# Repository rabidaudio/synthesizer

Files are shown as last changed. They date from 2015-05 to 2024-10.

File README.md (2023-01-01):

# Synth

> These are my custom modules for a from-scratch [Eurorack](https://en.wikipedia.org/wiki/Eurorack) analog synthesizer.

https://rabid.audio/projects/synth

## Modules

1. [Amplifier](amp)
  - LM13700
  - matched-pair PNP exponential converter
  - CV of 10V -> Gain=1
  - CV of <=0V -> Gain=\~0, 6 decades below Gain=1
  - allow overdrive to Gain=2
    - ideally this would begin to clip
  - mixdown
    - mono - full mix -> left and right
    - stereo split - A+C->left B+D->right
  - Direct stereo input jack
    - mix arbitrary signal with mixdown
    - e.g. for accepting signals from other synths
2. [Oscillator](vco)
  - 0-10V, 1V/octave, A0 to A10
  - Square/Triangle core via LM13700
  - Waveshapper for triangle -> sine
  - PWM control
    - triangle wave applied to comparator with CV controlling reference. Triangle wave means CV is linear
  - abs(triangle) can be used for 2x square
    - adds a lot of parts for little benefit
  - blending shapes isn't useful here, since we could use other oscillators for that
  - Option to sync with another osc?
    - in theory, grounding osc at a regular interval would reset the osc over and over, effectively changing it's frequency
  - CV control for shape?
  - Room for more shapes
    - white noise?
    - PDS
      - https://en.wikipedia.org/wiki/Phase_distortion_synthesis
      - a bit of wild harmonics
      - multiplication techniques
        - log/antilog
        - https://en.wikipedia.org/wiki/Gilbert_cell
        - AD633 ($11-$13 /unit on DigiKey!?)
        - EL4450C ($4/unit on Digikey but out of stock). It's a little more awkward to use since it's max differerential input voltage for linearity is 2V
      - the hard part will be the "slightly higher frequency" bit
        - perhaps instead you have another osc (555?) running at a fixed frequency and clipping the sine
        - square PWM control could also adjust this clip frequency
      - In Max you do PDS by `kink~`-ing a `phasor~` and using that to drive the phase of `cycle~`. Kink is somewhat straightforward to do - use a comparator to adjust the charge current after a threshold. But how you drive a sine wave phase with that I'm not sure
    - down ramp wave with just a JFET
      - up ramp wave probably needs another JFET and an inverter
    - sub octave
      - theory and example circuit: http://www.valvewizard.co.uk/uboat.html
    - octave
      - full wave rectifier
    - multiplying the triangle with a square wave with different phases and pulse-widths gives some neat sounds
    - polynomial
      - The EL4450C datasheet describes using a multiplier ic to create a polynomial of the form (k1 v^2 + v) / k2
      - it sounds like crap on a triangle wave and does nothing for a square wave, but it adds a nice second harmonic to a sine wave
      - from experiments in Max, good values are k1=1.5-2.5, k2=2
      - but at that point, should you just use 2 oscillators?
3. [A/D/S/R envelope](adsr)
  - 4 envelopes required for 4-voice polyphony
  - wired to VCA by default
  - save surface area with 1 set of ADSR controls for a pair of envelopes
  - fully modular means you could borrow one for VCF instead, or send to both VCA and VCF
4. Filter
  -  4P LP(/HP?)
  - Cutoff frequency control has same range as oscillator
    - 0-10V, 1V/octave, A0 to A10
  - filter we designed for class
    - standard vactrols are available on Thonk
  - CV control of cutoff + resonance
  - Default to track cutoff with VCO-CV
  - individual filter knobs, plus a global knob for filter sweeps
5. [Utilities](utils)
  - Buffer, Sum, Attenuate, Invert, Gate
  - Could be all-in one
    - A input (default ground)
    - B input (default ground)
    - level knob attenuator
    - gate digital CV in, default on
    - `(A+B)*level*gate` output
    - `-(A+B)*level*gate` output
    - Constant CV out if A and B disconnected

Bitcrusher?
4 filters or one?
Noise?
Clock?
Headphone output no longer required
2D mixer?

## TODO

- utility module
  - [x] Verify on breadboard
  - [x] design PCB
  - [x] order parts
  - [x] come up with a cute name
  - [x] design front panel
  - [x] assemble Rev. A PCB
    - bend the regulators first
    - plenty of 4066s
    - flip orientation of power connector
    - pot orientation - both channels:
      - right side (facing) to inside of board (from top)
      - left side (facing) to outside of board (from top)
  - [x] test with Neutron
    - constant output is only 9 to -7.8
    - high noise when used as a buffer
      - perhaps input signal is clipping?
      - white noise when the gain is turned down
  - [x] adjust design for Rev. B
  - [x] assemble Rev. B proto board
  - fix prototype issues
    - [ ] sum pot is backwards
    - [ ] a bit of noise on the constant output near the center
    - [ ] verify output levels
    - [ ] hard click on gate
      - needs a LPF?
  - [ ] assemble Rev. B PCB
  - [ ] manufacture front panel
  - [ ] assemble module
- VCA
  - [x] Confirm amp on breadboard, finalize CV levels
  - [x] figure out where tuning trimmers are needed
  - [x] build prototype
  - fix prototype issues
    - [ ] output is too quiet for headphones, need about 2x gain
    - [ ] CV range is too wide, adjust scaling for faster change in db/V
  - [ ] finish PCB schematic for complete amplifier
  - [ ] Create PCB
  - [ ] design front panel
  - [ ] manufacture front panel
  - [ ] assemble module
- VCO
  - [ ] design core
    - [x] core osc - square/triangle
    - [x] wave shaper (sine)
    - [x] pwm control
    - [ ] additional shape
    - [x] shape selection
  - [x] Confirm amp on breadboard, finalize CV levels
  - fix breadboard test issues
    - [ ] pitch is very sensitive to power supply noise
    - [ ] tuning is rather difficult
  - [ ] Build prototype
  - fix prototype issues
    - TBD
  - [ ] design PCB
  - [ ] Create PCB
  - [ ] design front panel
  - [ ] manufacture front panel
  - [ ] assemble module
- Envelope
  - [x] design in SPICE
  - [ ] verify on breadboard
  - [ ] build prototype
  - fix prototype issues
    - TBD
  - [ ] design PCB
  - [ ] Create PCB
  - [ ] design front panel
  - [ ] manufacture front panel
  - [ ] assemble module
- VCF
  - TBD
- build tools
  - [x] tiny Breakout pcbs for headphone jacks
  - ~~transistor matcher circuit~~
    - bought matched pair BJTs instead
  - [x] quantized selector with hysteresis

## License

Schematics, board layouts, documentation, etc. is licensed under [Creative Commons Attribution-NonCommercial-ShareAlike 4.0 International License](http://creativecommons.org/licenses/by-nc-sa/4.0/).



If you're interested in commercial use, please ask first.

Any source code is licensed under [MIT](SOFTWARE_LICENSE).

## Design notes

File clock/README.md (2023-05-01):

# The Count

## [Writeup and documentation](https://rabid.audio/projects/synth/clk/)

## Features

- BPM from 15 to 400
- two outputs with relative rates
- 3-digit LED 7-segment display
- swing control
- tap tempo
- CV in
- pause
- save/load/reset settings

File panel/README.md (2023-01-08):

# Layout

- Jacks at the top, controls at the bottom
- 14mm spacing between jacks (center to center) in both directions
- Knob/switch spacing?

- 1HP=1/5"=5.08mm
  - standard graph paper is 5 squares per inch, meaning exactly 1 real world HP per square
- 84 HPs (426mm) of usable horizontal space in a 19" rack
- 3U=128.5mm
  - 112.5mm of useable vertical space after leaving room for mounting screws
- Maximum control density:
  - jacks = 14mm wide, 9mm high (12+ recommended)
  - knobs = 22mm square (30mm recommended)
    - note: some knobs have 21mm base and need to be bigger
- each jack is 3HP wide, each knob is 5 or 6HP wide

Reference for dimensions: http://www.doepfer.de/a100_man/a100m_e.htm

# Panels

Material: 0.08" thick 6061 Aluminum

This series of posts is super helpful for aluminum panel cutting and applying graphics with transfer paper:

- https://syntherjack.net/eurorack-module-diy-tutorial-1-drilling/
- https://syntherjack.net/eurorack-module-diy-tutorial-2-graphics/

# Case

TipTop is good starter product, has it has adapter for mounting modules in 19" rack, and included power supply

Power supply:

- 2000mA at +12V
- 500mA at -12V
- 170mA at +5V

- https://www.amazon.com/Tiptop-Audio-Happy-Ending-Kit/dp/B074B29GPR

NiftyKeyz - 112 HP

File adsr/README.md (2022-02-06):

# ADSR Envelope

This circuit operates by using the LM13700 as a variable current source charging
a capacitor. It is configured as a non-inverting op-amp charging the capacitor
to a reference voltage `V_ref` at the `+` pin with a slew rate limited by the current
control. The capacitor's voltage will change linearly based on `I_abc` until it settles
at `V_ref`. Then a bit of digital logic to create a 3-state state machine to select the
correct  `V_ref` and `I_abc`.

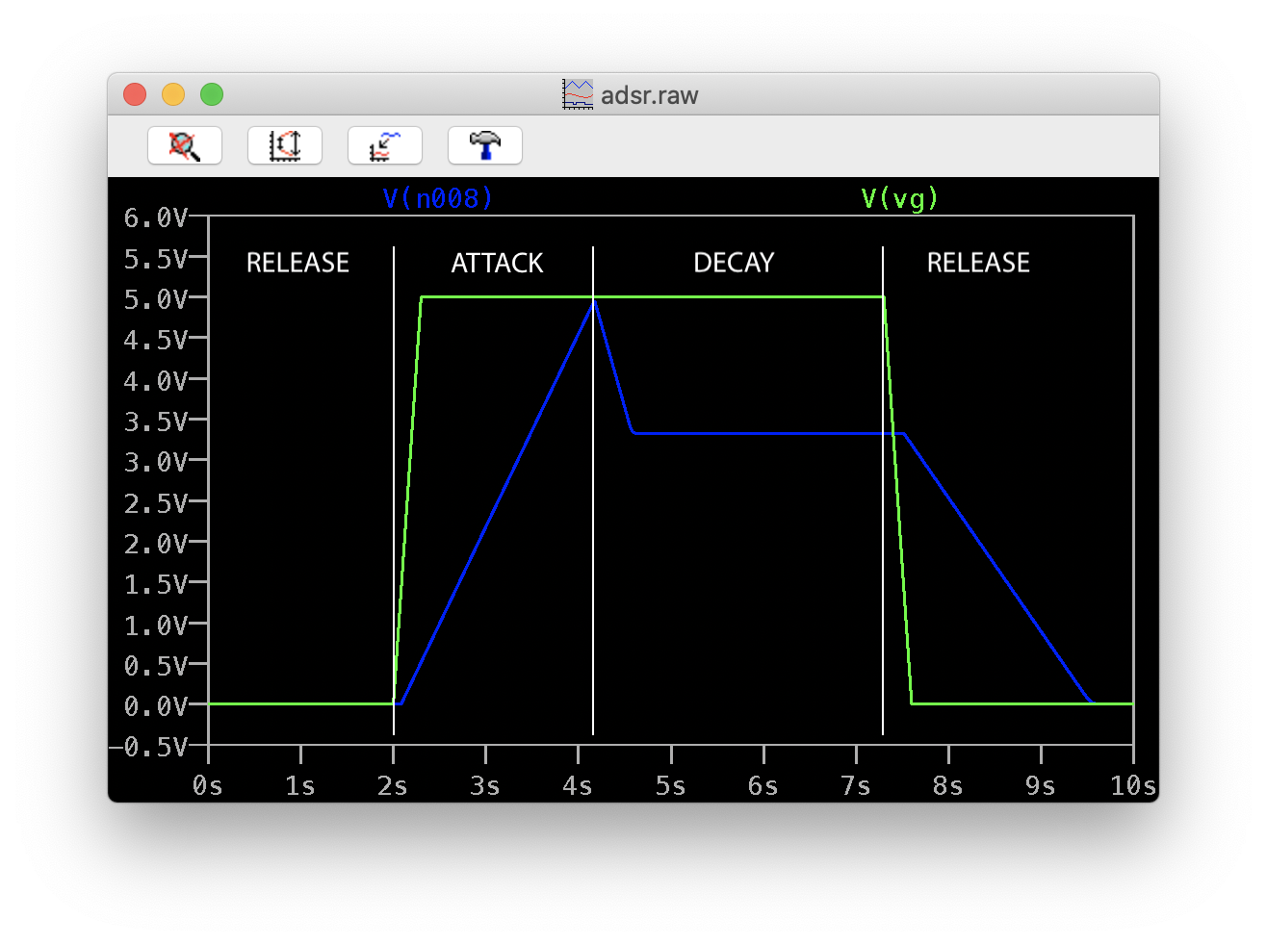
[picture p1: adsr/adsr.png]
shape


States:

- Attack: `V_gate=5V`, `V_ref=V_in`, `I_abc` controlled by `R_attack`
- Decay: `V_gate=5V`, `V_ref=V_sustain`, `I_abc` controlled by `R_decay`
- Release: `V_gate=0`, `V_ref=0`, `I_abc` controlled by `R_release`

The Attack, Decay, and Release knobs control `I_abc` in each state,
while the Sustain knob divides down `V_in` to set `V_ref` in the
Decay state.

A comparator, capacitor, and a few transistors create cheap analog
a flip-flop that turns on when the output hits `V_in` (flipping from
the Attack state to the Decay state), and turns off when `V_gate`
turns off.

Voltage control of the parameters could be possible by exposing
access to `I_abc`, but it doesn't make much sense to me to expose
those parameters with any control other than a knob - it's not the
kind of thing you need to modulate automatically.

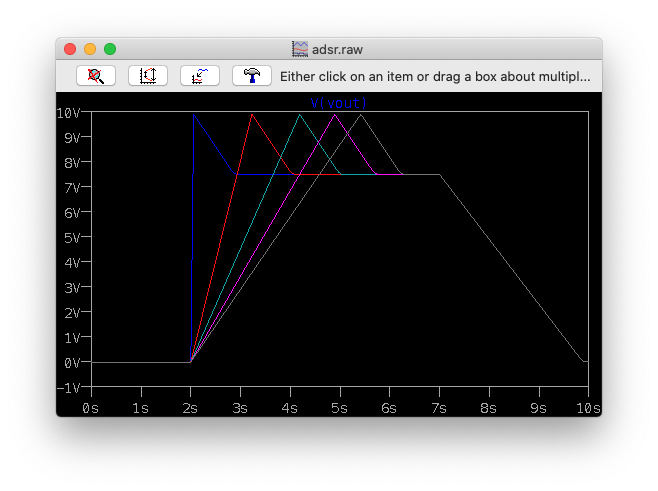
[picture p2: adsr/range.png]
range


Choice of the capacitor and the knob resistance control the time
range. Large values for both mean a longer charge time, but a large
capacitance effects the fastest charge time too, since `I_abc` is
capped at 2mA. Pot size effects dynamic range.

In practice, charge times less than 15ms are undetectable, and charge times above 2s are largely unnecessary.

A non-linear resistance would allow finer control at larger charge times. However linear seems to have plenty of expressiveness.

C=4.7u and a knob range of 1M gives a control range of 12ms to \~1.8s for a
0-5V change, i.e. a slew rate between 356 V/s and 2.4 V/s.

Could offer two caps, fast and slow, with a toggle switch. A 22u capacitor gives 58ms to 8.6s. A 1u capacitor gives \~5ms to \~55ms.

A current mirror isolates the 3 different reference voltages, without it they
interfere with each other.

Rates are dependant on the input level. This means if the input gate level is variable (for example it depends on MIDI note velocity), then the times will be slower for harder hits. We'd probably want constant rates regardless of velocity for example. However this seems difficult to achieve with the current design, as during release the input voltage is off, so without memory you don't have a reference to scale the output by.

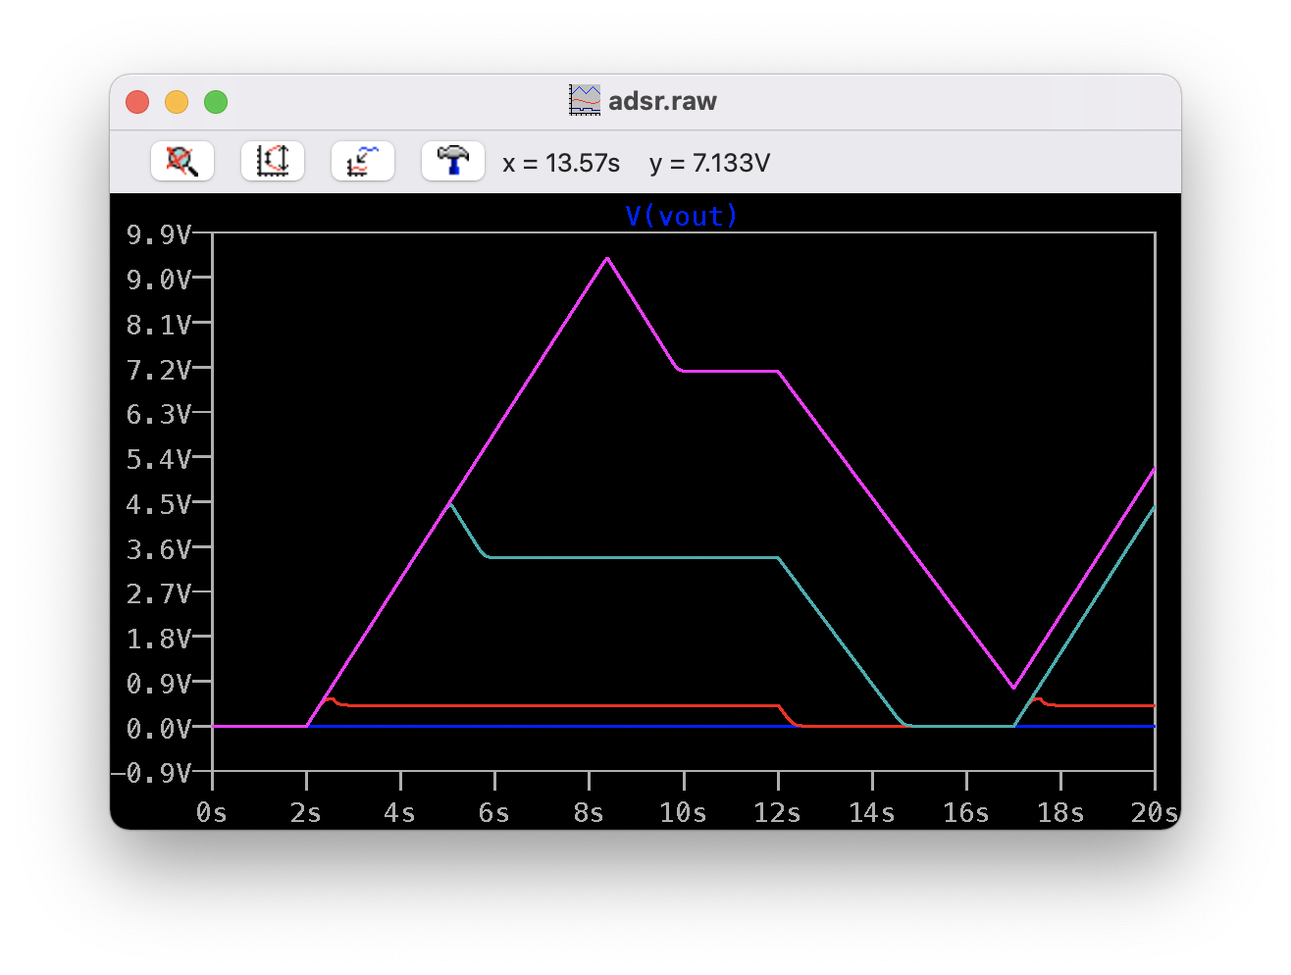
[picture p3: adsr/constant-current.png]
constant current means time depends on level


**TODO: power usage**

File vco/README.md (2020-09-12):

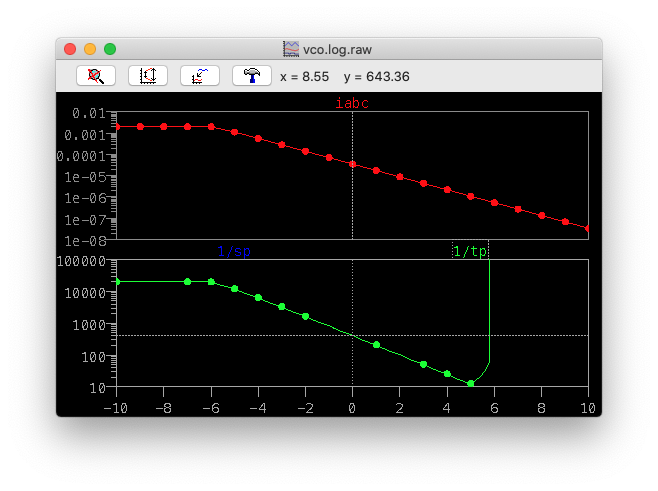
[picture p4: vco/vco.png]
vco response


Here, the frequency measurement flies off to infinity after 5V that's because the frequency has gotten too low to fit in the `.tran` time window. Increasing the time window wide enough to measure the frequency up to CV=10V causes the simulation to timeout. However, the exp. converter remains accurate to 3 decades below 0V, which is hypothetically CV=20V -> A-16 (f=419mHz or a period of \~40 seconds). The power supply max at CV=12 would be A-8 for a period of 9.8s.

`R_ref` was calculated to be 341K but empirically determined from LTSpice model to be 326K. A trim pot should allow precision tuning.

Accuracy seems to be dependant on min/max opamp output voltages. Might be good to invest in a real rail-to-rail comparator or use offset-null of TL071.

High-freq error seems to be from comparator slew rate. TL07X slew rate is roughly 13V/us (under best circumstances). At 14.08KHz, the period is \~71us, and it's got to travel 8.2V in two directions. That means 1.8% error right there.

From the simulation, the slew rate at 14.08KHz seems to be 3.8V/us, for an error of 6.2%, which is a bit closer to the measured 14%.

The LM311 datasheet claims a slew rate of up to 50V/us, equating to a \~0.5% error.

## Shapes

### Triangle

Triangle wave comes from the square/triangle core.

### Square

A base square wave comes from the square/triangle core. We feed that into a comparator which gives control over PWM.

### Sine

Triangle wave is converted to a sine wave using a textbook transistor waveshaper. The THD is on the order of 1-2%.

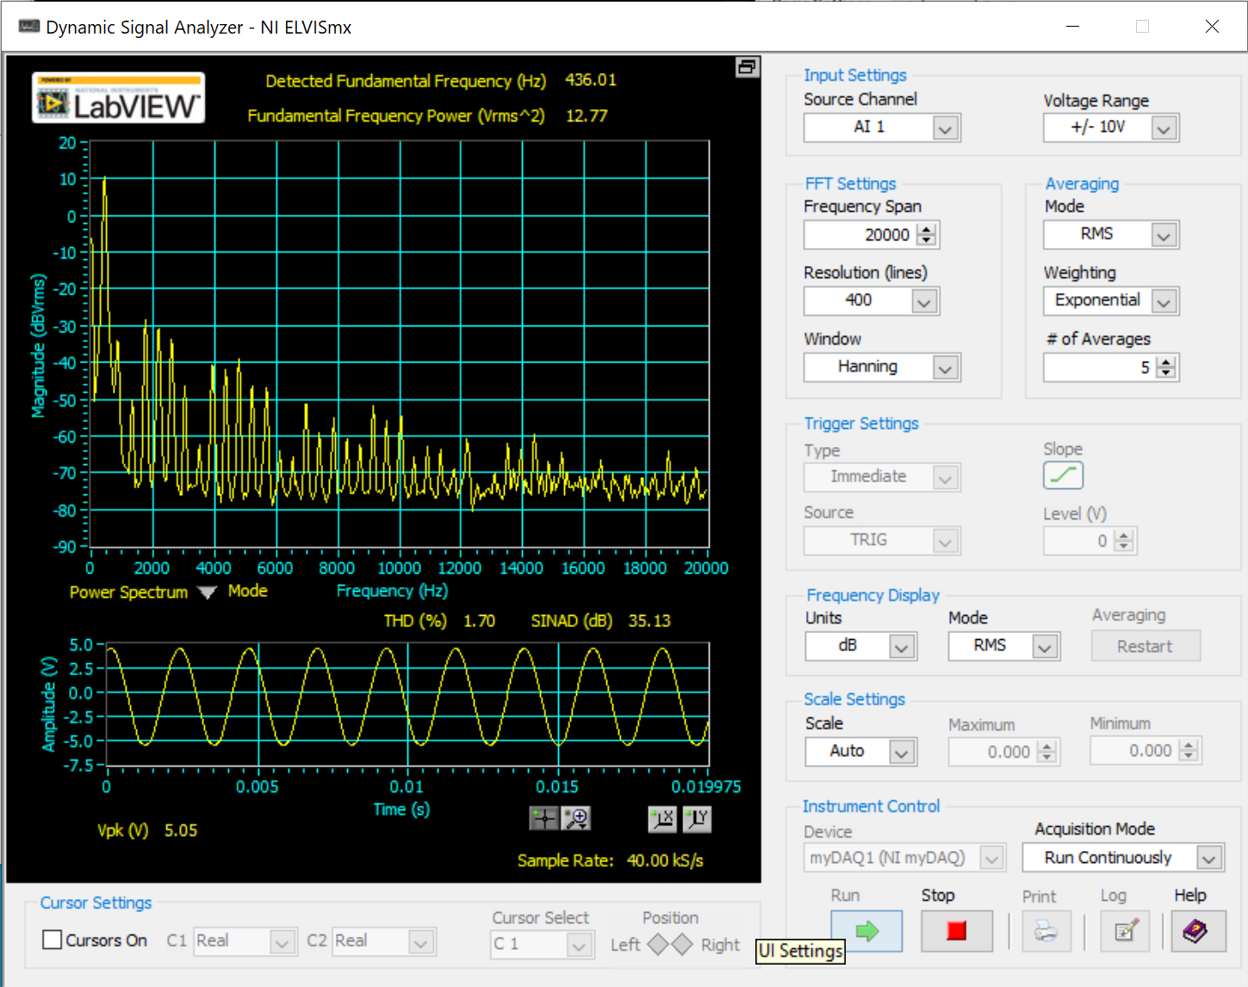
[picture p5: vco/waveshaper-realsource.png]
waveshaper-performance


### TODO: shape #4

Sub/super octave???

## Tuning

1. Set CV to 5V and adjust input network so VB=0V
2. Adjust square voltage divider network to 5V output and 0 offset
3. Adjust IREF to get 440Hz frequency
4. Set CV to 6V and adjust CV scale ratio to get 880Hz frequency
5. Adjust waveshaper current source pot until symmetric
6. Adjust waveshaper input voltage divider to minimize THD
7. Adjust waveshaper output stage to set level

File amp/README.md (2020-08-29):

# VCA

> 4-channel amplifier

## Description

Control Voltage 0-10V with `10V -> Gain=1`, `0V -> Gain~=0`. Can be overdriven up to `11V -> Gain=2` (actually slightly less because it will clip). Output is about 9.2 dB/V, with 0V around -98 dB.

Control voltage inputs are summed with a control knob, which adjusts CV between 0V and 10V.

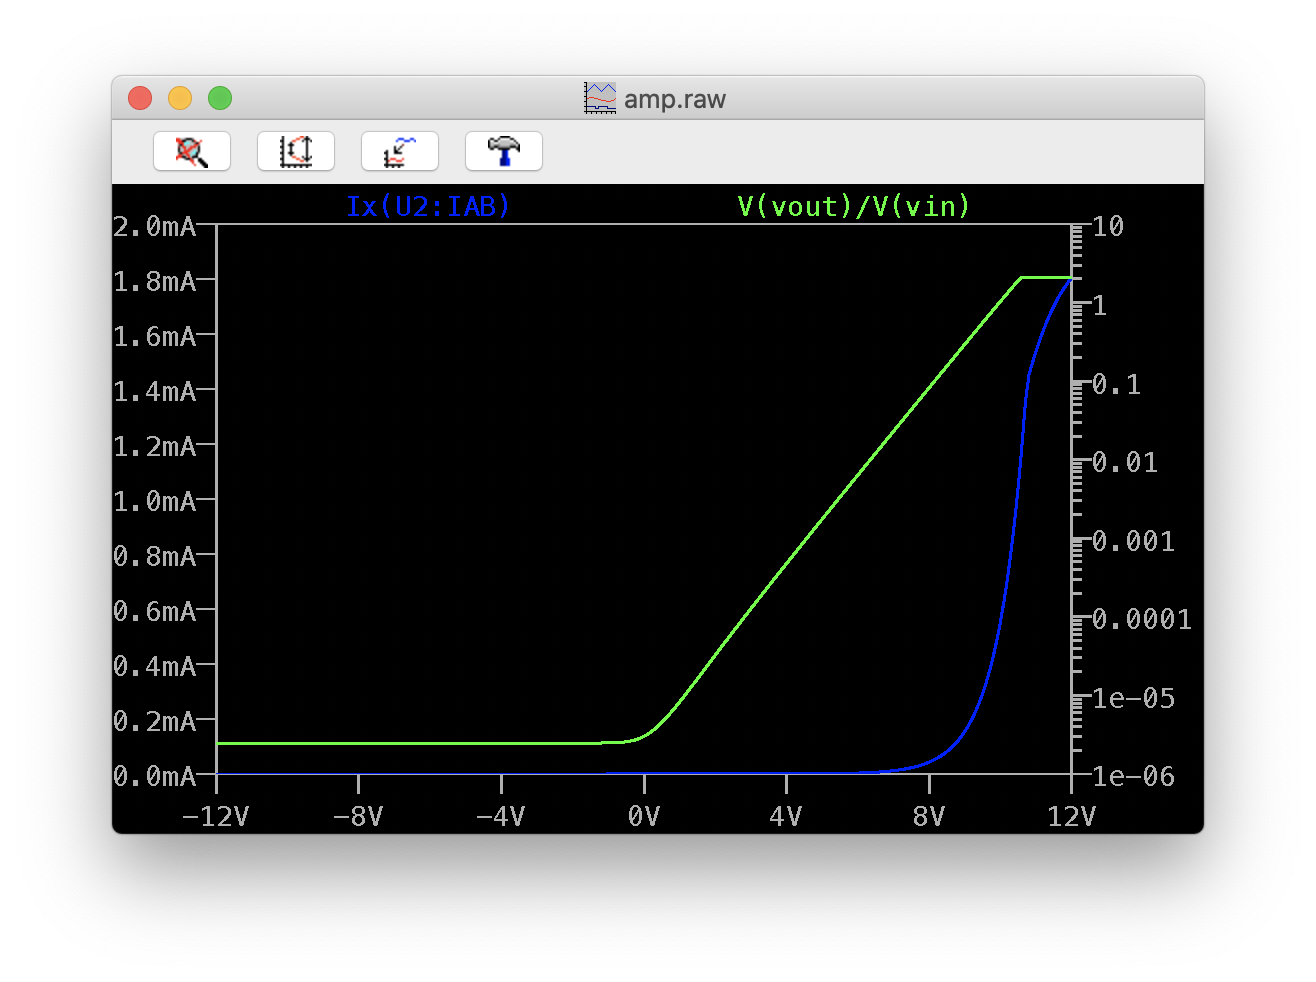
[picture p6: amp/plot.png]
cv-vs-gain


The 4 channels are connected to the 4 channels from the filter, unless an input is supplied.

The 4 channels are mixed down along with EXT-IN, an input for arbitrary external signals, such as those from another synth. In MIX mode, the result of the mix is sent to both left and right stereo outputs. in SPLIT mode, channels A and C go to the left channel output only, while B and D go to the right channel output only.

Both 1/4" TLS main and 3.2mm headphone outputs are available. **TODO: power calculation**

**TODO: power usage** 

## Design

The amplifier is designed around the [LM13700](../reference/datasheets/lm13700.pdf), with an [antilog converter](../reference/exponential.pdf) providing current control. Calculations of component values are [here](amp.xlsx).

The LM13700 acts as a linear amplifier when `Vd <= 20mV`. It's output is a current source given by the equation `Iout=0.5*Vd/Vt*Iabc` where `Vt=26mV` @ room temp. `Iabc` cannot exceed 2mA. Setting `Iabc=0.5mA` for unity gain puts `Iout=.192mA`. This can be converted back to a voltage with a resistor. `Rout=26kΩ `sets the overall voltage gain to unity.

## Tuning

1. Set CV-IN to 10V, and RV2 to completely off. Adjust RT1 until base of Q1A is 0V (or Q1 collectors are the same).
2. Adjust RT2 until the current through it is 0.5mA. One way to do this is to precicely measure the negative supply rail, and then adjust the resistance to match.
3. Set CV-IN to 0V, RV2 to completely on, and IN to 10V. Adjust RT3 until OUT is 10V (an overall gain of 1).

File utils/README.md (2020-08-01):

# Jackknife

> Buffer/Inverter/Gate/Adder/Scaler/Source

## Description

This is a collection of common tools for transforming signals, either control voltages or audio signals. While there are several distinct utilities, most are not mutually-exclusive.

### Source

When `A_IN` is disconnected, `OUT` is a constant voltage output based on the position of the knob. `OUT` is 0V when the knob is in the center position, and adjusts up to +/- 10V.

### Buffer / Scaler

When `A_IN` is supplied, it's value is buffered to `OUT`. The knob position linearly adjusts the output gain. At the center position, `OUT` is the same as `A_IN`. At the full-left position, `OUT` is off. At the full-right position, the value of `A_IN` is doubled. 

### Adder

When `B_IN` is supplied, it's value is added to `A_IN` before applying scaling.

### Inverter

`~OUT` is always the inverse of `OUT`.

### Gate

When `GATE` is supplied with a digital voltage, it allows disabling `OUT` (and `~OUT`) at logic-low (0V). An LED indicates when the gate is open. When `GATE` is not supplied, the outputs are always enabled, and the LED remains off.

### Digital logic

Digital `OR` can be implemented by summing signals on `A_IN` and `B_IN` With the knob at the 1/4 position. Digital `AND` can be implemented by applying one signal to `A_IN` and one to `GATE` with the knob at the 1/2 position.

## Design

A summing inverting amplifier with a variable feedback resistor handles the adder, inverter, and scalar. A connection on either A or B toggles an analog switch selecting between a constant voltage source and the summing output. Another
analog switch controlled by the gate allows that signal to be toggled before it is buffered in both an inverted and
re-inverted back to positive outputs.

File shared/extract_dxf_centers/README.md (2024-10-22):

# extract-dxf-centers

Parse a dxf file generated by OpenSCAD, cluster overlaping lines into layers, and print the center points of each cluster.

TODO

```bash
poetry run tox
poetry run extract_dxf_centers

poetry install
```

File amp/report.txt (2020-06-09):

Info: Backing up file “/Users/cjk/projects/synthesizer/amp/sym-lib-table” to file “/Users/cjk/projects/synthesizer/amp/rescue-backup/sym-lib-table-2020-03-15-19-12-47”.
Info: Backing up file “/Users/cjk/projects/synthesizer/amp/Amp.sch” to file “/Users/cjk/projects/synthesizer/amp/rescue-backup/Amp-2020-03-15-19-12-47.sch”.
Info: Backing up file “/Users/cjk/projects/synthesizer/amp/Amp.pro” to file “/Users/cjk/projects/synthesizer/amp/rescue-backup/Amp-2020-03-15-19-12-47.pro”.
Info: Backing up file “/Users/cjk/projects/synthesizer/amp/Amp-cache.lib” to file “/Users/cjk/projects/synthesizer/amp/rescue-backup/Amp-cache-2020-03-15-19-12-47.lib”.
Info: Backing up file “/Users/cjk/projects/synthesizer/amp/Amp-rescue.lib” to file “/Users/cjk/projects/synthesizer/amp/rescue-backup/Amp-rescue-2020-03-15-19-12-47.lib”.
Info: Backing up file “/Users/cjk/projects/synthesizer/amp/Amp-rescue.dcm” to file “/Users/cjk/projects/synthesizer/amp/rescue-backup/Amp-rescue-2020-03-15-19-12-47.dcm”.
Info: Adding library “Amp-rescue”, file “${KIPRJMOD}/Amp-rescue.lib” to project symbol library table.
Symbol “R” mapped to symbol library “Device”.
Symbol “TL072” mapped to symbol library “Amp-rescue”.
Symbol “C” mapped to symbol library “Device”.
Symbol “-12VA” mapped to symbol library “power”.
Symbol “+12VA” mapped to symbol library “power”.
Symbol “GND” mapped to symbol library “power”.
Symbol “R” mapped to symbol library “Device”.
Symbol “LM13700” mapped to symbol library “Amp-rescue”.
Symbol “LM13700” mapped to symbol library “Amp-rescue”.
Symbol “+12VA” mapped to symbol library “power”.
Symbol “-12VA” mapped to symbol library “power”.
Symbol “-12VA” mapped to symbol library “power”.
Symbol “+12VA” mapped to symbol library “power”.
Symbol “R” mapped to symbol library “Device”.
Symbol “R” mapped to symbol library “Device”.
Symbol “R” mapped to symbol library “Device”.
Symbol “R” mapped to symbol library “Device”.
Symbol “GND” mapped to symbol library “power”.
Symbol “GND” mapped to symbol library “power”.
Symbol “GND” mapped to symbol library “power”.
Symbol “-12VA” mapped to symbol library “power”.
Symbol “2N3906” mapped to symbol library “Amp-rescue”.
Symbol “2N3906” mapped to symbol library “Amp-rescue”.
Symbol “-12VA” mapped to symbol library “power”.
Symbol “R” mapped to symbol library “Device”.
Symbol “R” mapped to symbol library “Device”.
Symbol “GND” mapped to symbol library “power”.
Symbol “POT” mapped to symbol library “Amp-rescue”.
Symbol “GND” mapped to symbol library “power”.
Symbol “R” mapped to symbol library “Device”.
Symbol “C” mapped to symbol library “Device”.
Symbol “TL072” mapped to symbol library “Amp-rescue”.
Symbol “-12VA” mapped to symbol library “power”.
Symbol “+12VA” mapped to symbol library “power”.
Symbol “GND” mapped to symbol library “power”.
Symbol “TL072” mapped to symbol library “Amp-rescue”.
Symbol “-12VA” mapped to symbol library “power”.
Symbol “+12VA” mapped to symbol library “power”.
Symbol “R” mapped to symbol library “Device”.
Symbol “-12VA” mapped to symbol library “power”.
Symbol “R” mapped to symbol library “Device”.
Symbol “R” mapped to symbol library “Device”.
Symbol “GND” mapped to symbol library “power”.
Symbol “-12VA” mapped to symbol library “power”.
Info: Symbol library table mapping complete!

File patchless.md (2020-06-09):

analog modules with standardized plugs, no patch cables.
all patching done in software, e.g. iPad app, MAX, vst plugins, etc.

Possible with an ASIC which is just a bunch of CD4066-style bidirectional analog switches. Multiplexing every input to every other grows exponentially. Instead, you have a limited set of "patch cables" (channels) that each io can connect to. On-board memory to store switch state, which can be programmed (e.g. SPI).

```
64 patches, 128 io pins => 8192 switches, 16K transistors, 1KB of memory

8086 had 20K nMOS transistors, this is basically the same thing

singals are single-digit voltages at 100s of uAs, so power disipation is defintely a concern

144 pin BGAs exist
128x io, V+, V-, VDD, GND, 4xSPI, 8xNC
```

Bespoke ASIC design is $$$, but perhaps you cound build a company and raise money around it.

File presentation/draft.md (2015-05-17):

I'm Julian. By day I write software for drones, and by night I make side projects.
As the week progresses my nights take over my days, so I freelance hardware and software
development so that I can just do side projects for a living.

Today I thought I'd show you one of my side projects, the synthesizer I'm putting together,
and maybe inspire you to dive into hardware.

I figure most of the people in this room are software people. And I suspect there are a few people
who've maybe played with an arduino or a raspberry pi, sensors and LEDs and the like, but the 
thought of transistors or capacitors intimidates you. 

Well, synthesizers are a great jumping off point into analog electronics. 

1. They're modular
2. You interact with them on a human level, artistic
3. $$$

The modular is a big one for you software types.

### Intro to Synths

### No calculus

Just like software developers, hardware developers are lazy

##### 4 equations

- V=I*R (Ohm's law)
- fo = 1/(2*pi*R*C) (RC filter cutoff)
- (Ideal Op amps) Vo/Vi = -Rf/Ri, Rf/Ri + 1
- ???

### Modules

    CV CV
     | |
in->[   ]->out

VCO(oneVoltPerOctaveFrequencyCV, shape){
  exponentialVoltage = LinearExponentialConvert(oneVoltPerOctaveFrequencyCV);
  resistorFrequencyCV = OTA(exponentialVoltage);
  [square, triangle] = 2OpAmpSqTriOsc(resistorFrequencyCV);
  sine = WaveShape(triangle);

  switch(shape){
    case 'square': wave = square;
    case 'triangle': wave = triangle;
    case 'sine': wave = sine;
  }

  return wave;
}

### LFO

### Sequencer

while(record){
  buffer.push(analogRead(input));
}

....

while(play){
  analogWrite(buffer.next(), output);
}

10 bit vs. 16 bit

features:

- reverse
- adjustable rate
- clear
-trigger mode

### Boards

Eagle

### Future work

- replace Werkstatt with all custom modules
- 3 filters: 4-pole LP, HP, state-variable
- buffed-up VCA:
  - individually-controllable inputs (mixer)
  - higher output
  - stereo output
  - ability to invert stereo phase
- 2 to 4  4decade LFO's with clock input, PWM control
- second oscillator with relative tune control
- MIDI keyboard+EV replacement
- patch memory

### Learn more

Ray Wilson
Aaron Lanterman

### Me

@charlesjuliank

github.com/rabidaudio/synthesizer

rabid.audio/blog

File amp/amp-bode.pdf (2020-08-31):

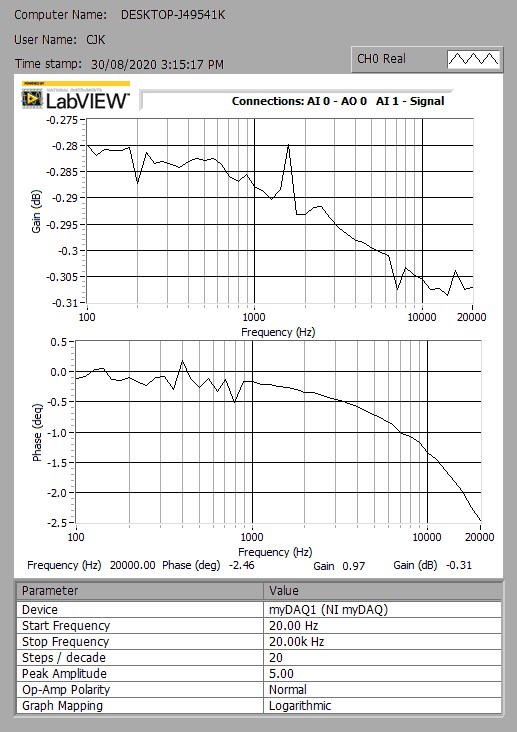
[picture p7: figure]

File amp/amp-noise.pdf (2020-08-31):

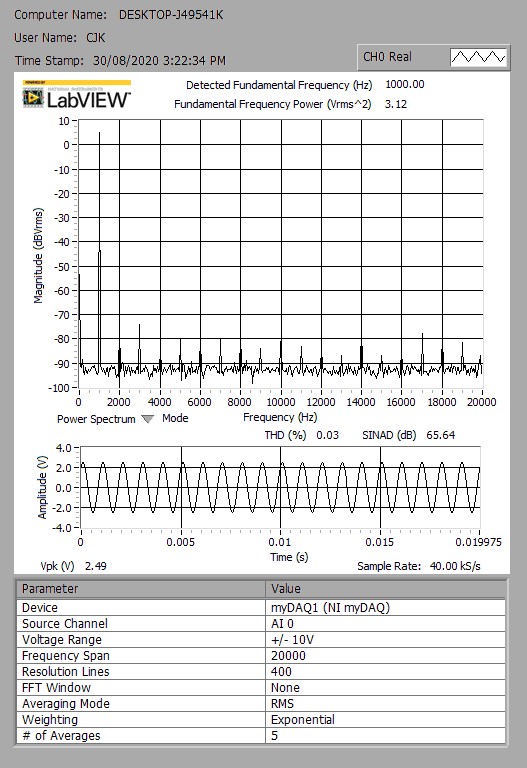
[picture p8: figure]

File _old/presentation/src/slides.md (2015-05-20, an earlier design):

name: title
layout: true
class: center, middle
---
class: inverse

# Custom modular synthesizer

alien music

<i class="fa fa-twitter"></i> [@charlesjuliank](https://twitter.com/charlesjuliank)  
<i class="fa fa-github"></i> [rabidaudio/synthesizer](https://github.com/rabidaudio/synthesizer)

???

I'm Julian. By day I write software for drones, and by night I make side projects.
As the week progresses my nights take over my days, so I freelance hardware and software
development so that I can just do side projects for a living.

Today I thought I'd show you one of my side projects, the synthesizer I'm putting together,
and maybe inspire you to dive into hardware.

I figure most of the people in this room are software people. And I suspect there are a few people
who've maybe played with an arduino or a raspberry pi, sensors and LEDs and the like, but the 
thought of transistors or capacitors intimidates you. 

Well, synthesizers are a great jumping off point into analog electronics. 

---

# Why synthesizers?

???

So why learn electronics with synthesizers?

---
name: whysynth
## 1
# human

???

It's a form of artistic expression. connecting the technical with the artistic.

It's very sensory driven. Turning knobs changes what you hear, etc.

---
## 2
# old

???

This stuff is old-fashioned. Nowadays everything is smaller, more complicated, and harder to use.
Old stuff like this, the components are bigger, the circuits are simpler, and the patents have started to expire.

---

## 3
#$$$

???

Original modular synths which used to be trashed for parts are now selling for thousands or tens of thousands of dollars.
Analog systems are starting to make a comeback, and I think it is thanks to an intersection between the DIY maker community and the
rising popularity of EDM and Dubstep. 

---
class: list

## Anatomy of a synthesizer

.my-left-column[
### pitch
### loudness
### timbre
]

<i class="fa fa-arrow-right myarrow"></i>

.my-right-column[
### frequency
### amplitude
### shape (harmonics)
]

???

Some of you probably don't have any idea how a synthesizer works or what it does, so here's a 
very brief, simplified introduction. 

When making music, you've basically got control of three parameters:

- pitch
- loudness
- timbre

These are directly related concepts to signals:

- frequency
- amplitude
- shape (harmonics)

### 

---
class: webcam

<!-- Webcam -->

???

### Demo 1

I have here a Moog Werkstatt. It's an open-source hackable synthesizer. 

First we use an oscillator to make a wave. We can control the frequency, and the shape (square vs. saw).
Then we pass it through a filter, were we can control more of the shape by cutting off higher harmonics
or even adding more.
Finally we pass it through an amplifier to control the loudness.

Filter cutoff is wah sound for guitarists in the room

So the nice thing is all of these are modules

---

# Modularity
### Where the magic comes from

---
background-image: url(/i/module.png)

???

All modules basically work like so.

You have a signal input and output, and you control how the signal is changed through control voltages.

---
background-image: url(/i/VCF.png)

???

So here's the same diagram for the filter i just showed you.

VCF stands for voltage controlled filter

We've got two controls for our filter, cutoff frequency and resonance. it would take too long 
to explain exactly what the resonance does, but for now just know it adds higher harmonics.

---

# Modulation

???

And Modularity gives us Modulation

### GO BACK TO DEMO

filter sweep at a regular rate?
External modulation: LFO filter sweep
Vibrato
FM modulation

---

# So what did *you* build?

---
class: list

# LFO

- Oscillates  roughly .1Hz to 100Hz
- Square and triangle outputs
- Adjustable amount

.footnote[*not yet voltage controllable]

???

## Go back to demo

- just my LFO
- my LFO at a different rate than bult-in
- mine adjusting the rate of the built-in

---
class: list

# Sequencer

- Record patterns and play them back
- Change the playback rate
- ~30 seconds of record time
- reverse mode
- trigger mode

???

### Demo!!!

- show recording a pattern
- changing speed
- reverse mode
- trigger mode

You might notice it's a little out of tune.
the ATMega has 10 bit DACs and ADCs, so a single bit
of variation is a pretty significant pitch change (you can hear it)

I bought some external 16-bit DACs and ADCs. However, they are really small

---

.left-column[
## Memory

## onRecord

## onPlay
]

.right-column[
```C
short buffer[512];
```

```C
while(record){
  buffer.push(analogRead(input));
}
```

```C
while(play){
  analogWrite(buffer.next(), output);
}
```
]

.footnote[
  Super simplified. See Github for source.
]

???

Here's the basicly what the microprocessor does it half-C,
half-javascript Frankenstein pseudo-code.

The source code is out on the github link if you want to see it.

---
# TI ADS1110
### 16-bit I<sup>2</sup>C

adc

---
background-image: url(/i/quarter2.jpg)

---
background-image: url(/i/schem.png)

???

Doing PCB layouts in Eagle. The Schematic is done

---
class: bgblack
background-image: url(/i/board.png)

???

The board needs a little work

---
# Others

---
# Octopus VCF

???

For class, we build a Low pass filter using Vactrols, which
are LEDs glued to voltage-controlled resistors. 

We 3d printed a little box for the LEDs and designed the board. 

Had to turn it in, so I couldn't bring it but to show, but I'm going
to make another one soon. 

---
background-image: url(/i/octopus.jpg)

???

- 4-pole lowpass filter
- cutoff and resonance controls
- custom vactrols
- combined Buchla's vactrol current circuits with Ray Wilson's 4-pole design

---
background-image: url(/i/box.png)

---
# Second VCO

---
background-image: url(/i/vco.jpg)

???

I'm also adding a second VCO to the mix.

It doesn't work yet, and you can probably tell why. 

It will be tunable relative to the first vVCO
so they can be in tune, or in thirds, or fifths or octaves above or below

---
class: list

# Future work

- Entirely custom modules
- 3 filters: 4-pole LP, HP, state-variable
- Buffed-up VCA
- Extra LFOs
- Second VCO with relative tune
- MIDI keyboard
- Patch memory

???

- replace Werkstatt with all custom modules
- 3 filters: 4-pole LP, HP, state-variable
- buffed-up VCA
  - individually-controllable inputs (mixer)
  - higher output
  - stereo output
  - ability to invert stereo phase
- a couple 4-decade LFO's with clock input, PWM control
- second oscillator with relative tune control
- MIDI keyboard+EV replacement
- patch memory

---
class: inverse

### Learn more
[rabidaudio/synthesizer](https://github.com/rabidaudio/synthesizer)  
[rabid.audio/blog](http://rabid.audio/blog)

### DIY Synth resources
[Ray Wilson, *Make: Analog Synthesizers*](http://www.amazon.com/Make-Analog-Synthesizers-Ray-Wilson/dp/1449345220)  
[Aaron Lanterman's class notes](http://users.ece.gatech.edu/lanterma/acms)

.footnote[
  @charlesjuliank
]

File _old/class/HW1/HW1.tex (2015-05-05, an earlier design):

\documentclass[12pt]{article}
\usepackage{amssymb, amsthm, graphics, graphicx}
\usepackage{amsmath}
\usepackage{url}

%these are initial settings. Ron recommended them, so that's just what I use.
\textwidth = 6.5 in
\textheight = 9 in
\oddsidemargin = 0.0 in
\evensidemargin = 0.0 in
\topmargin = -.75in
\parskip = 0.2 in
\parindent = 15 pt
\renewcommand{\baselinestretch}{1.25}
\renewcommand*{\thefootnote}{[\arabic{footnote}]} %square brackets

\providecommand{\e}[1]{\ensuremath{\times 10^{#1}}}
\providecommand{\degree}[0]{\ensuremath{^{\circ}}}

\providecommand{\ah}[1]{\ensuremath{\hat{a}_{#1}}}
\providecommand{\ahx}[0]{\ensuremath{\ah{x}}}
\providecommand{\ahy}[0]{\ensuremath{\ah{y}}}
\providecommand{\ahz}[0]{\ensuremath{\ah{z}}}
\providecommand{\pfs}[0]{\ensuremath{\epsilon_{0}}} %permittivity of free space => 1/(36\pi) \e{-9}
%\providecommand{\vec}[1]{\ensuremath{\textbf{#1}}} %vector notation ACTUALLY \vec is _real_ vector notation
\providecommand{\ohm}[0]{\ensuremath{\Omega}}

\newtheorem*{prob}{Problem}

\begin{document}
\begin{flushright}
\textbf{Charles Julian Knight}\\
ECE4892\\
\today
\end{flushright}

\begin{center}
\huge HW 1
\end{center}

\begin{prob}[1.a]{
  Design an circuit with a single op amp that will covert pitch control voltages from the Moog standard to the Buchla standard. You may assume that your conversion module is given an input from a voltage source with zero output impedance and is being fed to a module with an infinite input impedance; you also do not need to worry about input and output protection (assume nobody will be abusing your module). For this part of the exercise, assume you have perfect ``zero-tolerance'' resistors.
}\end{prob}

Since the Moog standard is lower than the Buchla standard and we don't want to invert the signal, let's use
a non-inverting amplifier with a gain of
\[ \frac{V_o}{V_i} = \frac{1.2V}{1V} = 1.2 = \left(1+\frac{R_i}{R_f}\right) \rightarrow R_i = .2R_f \]
If we pick $R_i = 1k\ohm$, then $R_f = 20k\ohm$, both of which are common resistor values.

\begin{prob}[1.b]{
  Off-the-shelf resistors never exactly match their listed values. Let's do a ``worst case'' analysis for the case where your circuit is given a one volt input. If you use 5\% resistors, assuming the true resistance is uniformly distributed, what is the highest voltage you might get out? What is the lowest voltage? How many semitones above and below the desired value are these voltages in the Buchla pitch standard?
}\end{prob}

The highest gain would happen when $R_i$ is $5\%$ too big and $R_f$ is $5\%$ too small (and vice versa for the lowest gain). 
\[ 1V \left(1+\frac{1.05R_i}{.95R_f}\right) = 1.221V \rightarrow +0.21 semitones \]
\[ 1V \left(1+\frac{.95R_i}{1.05R_f}\right) = 1.181V \rightarrow -0.19 semitones \]

This means the notes would be about $20$ cents sharp or flat. 

\begin{prob}[1.c]{
  Repeat the above analysis for 1\% resistors.
}\end{prob}

\[ 1V \left(1+\frac{1.01R_i}{.99R_f}\right) = 1.204V \rightarrow +0.04 semitones \]
\[ 1V \left(1+\frac{.99R_i}{1.01R_f}\right) = 1.196V \rightarrow -0.04 semitones \]

This means the notes would still be about $4$ cents sharp or flat. According to a Georgia Tech student's master's thesis\footnote{\url{https://en.wikipedia.org/wiki/Cent_(music)#Human_perception}}, the limits of human pitch perception are around $5-6$ cents, so you could probably get away with these resistors.
%%%%%%%%%%%%%%%%%%%%%%%%%%%%%%%%%%%%%%%%%%%%%%%%%%%%%%%%%%%%%%%%%%%%%%%%%%%%%%%%%%%%%%%%%%%%%%%%%%%%%%%%%%

\begin{prob}[2.a]{
  Find the voltage at the output of IC3:B. You can do this quickly if you realize that this op amp is acting in a standard ``inverting mixer'' configuration. (Remember we are assuming the wiper of the ``pan'' pot is at ground).
}\end{prob}
This opamp appears to be in an inverting setup. By our ideal opamp rules, the inverting pin must be a virtual ground. Since the pan pot is also at ground, no current flows through R7. Thus the current through R3 is $\frac{V^- - 0}{120k} = -.1mA$. That same current flows through R5, so the output voltage must be
\[0.1mA *100k\ohm = 10V\footnote{Or simply $-12*-100k/120k=10$}\]

\begin{prob}[2.b]{
  Given all the notes above and the assumption that the current through the base of Q2 is negligible, so we may approximate its collector and emitter currents as being equal, find the current input to the OTA ($I_{con}$) as a function of $V_{con}$.
}\end{prob}
Since the inverting input of the opamp is at virtual ground, there's a current comming from IC3B of $10V/100k=.1mA$ and a current coming from our control J5 $V_{con}/100k$. Some of those two currents are going to $V^-$ through R16, but the rest must be going through R12. The current through R12 (let's call it $I_{12}$) must be $I_{12}=.1mA + V_{con}/100k - .0545mA =.04545mA -V_{con}/100k$. That means the voltage at the emitter of Q2 is $-10K I_{12}$. So $I_{con}$ is $I_{12}$ plus the part that goes through R18 from ground. So in total,
\[I_{con} = I_{12} + I_{12}\frac{10k}{1.5k} = 7.66I_{12} = .349mA - \frac{7.66V_{con}}{100k} \]
%  R12 and R18 appear to be in parallel. Thus
% \[I_{con} = \frac{V_{con}}{R12||R18} = \frac{V_{con}}{1.3K\ohm} \]

\begin{prob}[2.c]{
  Now let's look at the main part of the VCA, with input at J2 and output at J11. Find the gain of the VCA as a function of $I_{con}$. For now, you may ignore C12 (i.e. open the cap, which is a reasonable assumption for low frequencies).
}\end{prob}
We're taking the non-inverting input of the 13600 to be ground. I'll call the signal at J2 $V_{in}$ and at J11 $V_{out}$. We know the output of the OTA to be
\[I_{out} = I_{con}\frac{\left(\frac{220}{220+22k}\right)V_{in} -0}{2V_T}\]
Then $I_{out}$ is fed into an inverting amp. If that same current is through R52, then $V_{out} = R52 I_{out}$. The gain is then
\[ 33k\frac{\left(\frac{220}{220+22k}\right)}{2V_T}I_{con} = -(6.283 mA^{-1})I_{con} \]

\begin{prob}[2.d]{
  Suppose $V_{con}$ = 10V (from what I understand, the envelope generators in the PAiA 9700 series can generate up to 10V, so that's a reasonable voltage to try). What is $I_{con}$ in this case?
}\end{prob}
Assuming my equation in part b is correct,
  \[ I_{con} = 7.66I_{12} = .349mA - \frac{7.66\cdot10V}{100k} = -.417 mA \]

\begin{prob}[2.e]{
  Take a look at the ``Absolute Maximum Ratings'' section of the LM 13600 datasheet. What is the maximum rating for the control current (which the data sheet will call $I_{ABC}$)? Is the value you found in part (d) above or below this?
}\end{prob}
The max current is $2mA$, so this is quite a safe current.

\begin{prob}[2.f]{
  What is the gain of the VCA for $V_{con}$ = 10 V?
}\end{prob}
Assuming my equation for part c is correct,
\[A = -(6.283 mA^{-1})I_{con} = 2.62347 \]

\begin{prob}[2.g]{
  Without going through extensive calculations - i.e., by just reasoning your way through the circuit - what happens to the VCA gain as the wiper of the ``pan'' pot is turned away from ground and toward V+.
}\end{prob}
Sweeping the pan pot decreases $I_{con}$ for the right VCA that we were analyzing which reduces the gain, but at the same it increases $I_{con}$ for the left VCA which has an identical circuit amplifying J1 to J10.

\begin{prob}[2.h]{
  Previously, we ignored C12. If we now consider it, we see that C12, R52, and IC6:B act as a current-to-voltage single-pole lowpass filter with a cutoff frequency (half-power point) of $1/(2\pi RC)$). What is the cutoff frequency of this filter? Is this cutoff frequency above or below the limit of typical human hearing?
}\end{prob}
\[f_c = \frac{1}{2\pi RC} = 48.2 KHz\]
which is much higher than 20 KHz. I imagine this helps avoid high-frequency oscillations.

\begin{prob}[2.i]{
  What is the input impedance of the VCA?
}\end{prob}
Looking in from J2, the signal sees a $22K\ohm$ and $220\ohm$ series resistance to ground. So the input impedance is $22.22k\ohm$.

\begin{prob}[2.j]{
  What is the output impedance of the VCA? (Assume the op amps are all ideal, i.e., they have zero output impedance).
}\end{prob}
At J10 and J11, they didn't put any series output resistors, so it is theoretically (not practically) infinite. But on J12, which could be some sort of mixdown of left and right, the output impedance is R116$||$R117 = $5k\ohm$.

% %%%%%%%%%%%%%%%%%%%%%%%%%%%%%%%%%%%%%%%%%%%%%%%%%%%%%%%%%%%%%%%%%%%%%%%%%%%%%%%%%%%%%%%%%%%%%%%%%%%%%%%%%%%5
\begin{prob}[3]{
  On a single graph, plot (a) the voltage at ``C'' as a function of R, for $0 < R < 10K$, and (b) the same thing as (a), except suppose that the 120K resistor is actually a 10K resistor. I recommend using MATLAB to make the graph, but you may use whatever computer program you prefer.\\ Which graph, (a) or (b), looks more linear?
}\end{prob}
\[V_{out}(R) = V^+ \left(\frac{(R||120k)}{(R||120k)+(10k-R)}\right)\]
\begin{verbatim}
EDU>> R = linspace(1,10000);
EDU>> R2=120000;
EDU>> V=12;
EDU>> parallel = (R*R2)./(R+R2);
EDU>> out = V*(parallel./(parallel + (10000-R)));
EDU>> plot(R, out)
EDU>> R2=10000;
EDU>> parallel = (R*R2)./(R+R2);
EDU>> out = V*(parallel./(parallel + (10000-R)));
EDU>> plot(R, out)
\end{verbatim}
\begin{center}
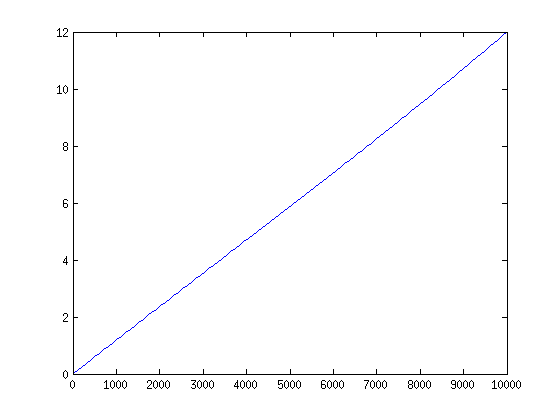
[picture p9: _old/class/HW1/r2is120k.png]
  
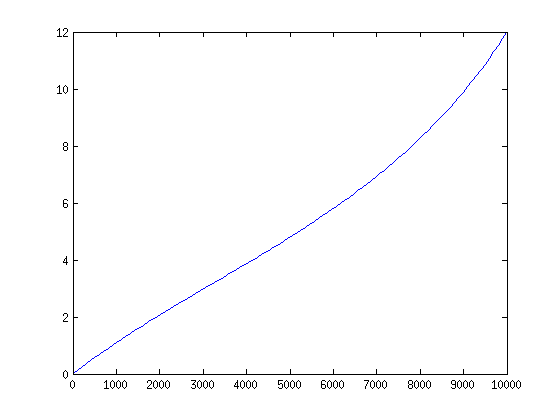
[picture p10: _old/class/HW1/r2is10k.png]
  
\end{center}
I think it is pretty obvious why R7 is $>>$ R109.

% %%%%%%%%%%%%%%%%%%%%%%%%%%%%%%%%%%%%%%%%%%%%%%%%%%%%%%%%%%%%%%%%%%%%%%%%%%%%%%%%%%%%%%%%%%%%%%%%%%%%%%%%%%%5
\begin{prob}[4.a]{
  Find the gain of the VCA as a function of $I_{con}$.
}\end{prob}
We can use the same method as 3.c. The gain of the OTA is
\[ I_{out} = \frac{I_{con}}{2V_T}(0 - V_-)\]
$I_{out}$ goes into a $1.5k$ resistor, and that voltage goes through a non-inverting amp with a gain of 1. So
\[V_{out} = \frac{I_{con}}{2V_T}(-V_-)\frac{1}{1.5k} \]
For $V_-$, we need to figure out the gain of the input stage amp. This is an inverting amp with a gain of $100k/100k=1$,
which is then fed into a voltage divider $\frac{100}{12.1k}$ so $V_- = -.00826V_{in}$. Thus
\[V_{out} = \frac{I_{con}}{2V_T}(.00826V_{in})\frac{1}{1.5k} \]
\[A = \frac{V_{out}}{V_{in}} = \frac{I_{con}}{2V_T}(.00826)\frac{1}{1.5k} = (.1058mA)I_{con} \]

\begin{prob}[4.b]{
  What is the input impedance of the VCA?
}\end{prob}
Since there is an inverting amp on the input, the input impedance is R10 $=100k\ohm$.

\begin{prob}[4.c]{
  What is the output impedance of the VCA? (Assume the op amps are all ideal, i.e., they have zero output impedance).
}\end{prob}
Since there is a non-iverting amp on the output, the output impedance is R19 $=470\ohm$.

\end{document}

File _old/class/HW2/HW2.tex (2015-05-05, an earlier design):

\documentclass[12pt]{article}
\usepackage{amssymb, amsthm, graphics, graphicx}
\usepackage{amsmath}

%these are initial settings. Ron recommended them, so that's just what I use.
\textwidth = 6.5 in
\textheight = 9 in
\oddsidemargin = 0.0 in
\evensidemargin = 0.0 in
\topmargin = -.75in
\parskip = 0.2 in
\parindent = 15 pt
\renewcommand{\baselinestretch}{1.25}

\providecommand{\e}[1]{\ensuremath{\times 10^{#1}}}
\providecommand{\degree}[0]{\ensuremath{^{\circ}}}

\providecommand{\ah}[1]{\ensuremath{\hat{a}_{#1}}}
\providecommand{\ahx}[0]{\ensuremath{\ah{x}}}
\providecommand{\ahy}[0]{\ensuremath{\ah{y}}}
\providecommand{\ahz}[0]{\ensuremath{\ah{z}}}
\providecommand{\pfs}[0]{\ensuremath{\epsilon_{0}}} %permittivity of free space => 1/(36\pi) \e{-9}
%\providecommand{\vec}[1]{\ensuremath{\textbf{#1}}} %vector notation ACTUALLY \vec is _real_ vector notation
\providecommand{\ohm}[0]{\ensuremath{\Omega}}

\newtheorem*{prob}{Problem}

\begin{document}
\begin{flushright}
\textbf{Charles Julian Knight}\\
ECE4892\\
\today
\end{flushright}

\begin{center}
\huge HW 2
\end{center}

\begin{prob}[1.a]{
When the output of the comparator is $+10$ V, what is the voltage at the positive input terminal of U3A?
}\end{prob}
We can assume D1 is off, and D2 is on. Thus the voltage at the $k$ side of D2 is $10-.7=9.3$V. It see's a path to ground through a 100K, a 50K (half of R25), and a 1K. The input voltage is a divider:
\[ V_{in} = 9.3 \frac{1K}{151K} = 61.6 mV \]

\begin{prob}[1.b]{
When the output of the comparator is $+10$ V, using the nonlinear ``tanh'' model for OTA behavior, what is the output current of the OTA as a function of the current control input (pin 1) of the OTA? (Note that unlike the Buchla 259 VCO circuit we looked at in class, the OTA here does not seem to be fully saturated.)
}\end{prob}
The non-linear model:
\[ V_o = 19.2 I_{con} \tanh(v_+ - v_-) = 19.2 I_{con} \tanh(61.6mV) = 1.81 A^{-1}I_{con} \]

\begin{prob}[1.c]{
When the output of the comparator is $+10$ V, what voltage at the output of the integrating op amp (pin 1 of U2-A) would cause 0 V to appear at the positive terminal of the comparator op amp (pin 3 of U4-A)? (Note that this will tell you the maximum level of the triangle wave).
}\end{prob}
We know the output of the comparator to be $10V$, so we can think of the input of the comparator to be a voltage divider with the top fixed and the bottom ($v_{tri}$) variable. I'm calling the input of the comparator $v_{ci}$.
\[ v_{ci} = (10-v_{tri})\frac{120K}{120K+270K} \]
\[ v_{tri} = 10 - v_{ci}\frac{13}{4} \]
Thus, when $v_{ci}=0V$, $v_{tri}=0V$.

\begin{prob}[1.d]{
What is the frequency of the triangle wave as a function of the current control input (pin 1) of the OTA?
}\end{prob}
We're running the output of the OTA into an integrator, so let's integrate our equation from part b:
\[v_{tri} = -\int_0^t 1.81 A^{-1}I_{con} d \tau  = -1.81 A^{-1}I_{con} t \]
We found our voltage swing to be from $61.6$mV to $0$V, and that's the change in one period, so
\[ t = \frac{-61.6mV}{-1.81 A^{-1}I_{con}}\]

Of course, frequency is $1/t$, so
\[ freq = 29.4 \ohm^{-1} I_{con} \]

But since this is one-half swing, the total triangle frequency would be twice this.
Units of seconds should be somewhere in there, not sure where they went. But the proportions should be right.

\begin{prob}[1.e]{
Take a look at the TRI output in the middle of the page (pin 2 of R15). What is the output impedance of the TRI output?
}\end{prob}
The output impedance is simply R15 $= 1K\ohm$.

%%%%%%%%%%%%%%%%%%%%%%%%%%%%%%%%%%%%%%%%%%%%%%%%%%%%%%%%%%%%%%%%%%%%%%%%%%%%%%%%%%%%%%%%%%%%%%
\begin{prob}[2.a]{
What is $I_{ref}$?
}\end{prob}
If $I_{ref}$ is the right-side current, then that opamp is holding the top of that 330K (collector of right BJT) at a virtual ground. The current (from top to bottom) is then
\[ \frac{0V--15V}{330K} = .0455 mA \]

\begin{prob}[2.b]{
 Assuming that the CV offset trim pot is set all the way to the ``right'' (i.e. at ground), what change in CV will cause the control current to double? (Assume the PNP BJTs draw insignificant current through their bases).
}\end{prob}
To get the control current to double, the factor inside the exponent must increase by $\ln(2)$.

The base voltage into the right BJT is given by the voltage divider
\[ v_{rb} = CV\frac{100K||4.7K}{150K+100K||4.7K} = .029*CV \]

So
\[.029CV_2 = .029CV_1 + \ln(2) \]
\[CV_2-CV_1 = \frac{\ln(2)}{.029} = 23.9 V\]
This is stupidly large, so obviously I did something wrong. We want a really small swing in CV, not a really big one.

\begin{prob}[2.c]{
 Assuming the OTA is operating in the linear region, give an expression relating the audio output voltage to the audio input voltage in terms of the current at the control input pin of the OTA. (You may ignore the offset trimming circuitry of the OTA. Assume the positive input of the 3080 is grounded.)
}\end{prob}

\begin{prob}[2.d]{
What is the input impedance of this VCA?
}\end{prob}
\[ 100K + 220 = 100,220 \approx 100K\ohm\]

\begin{prob}[2.e]{
What is the output impedance of this VCA? (It might be ``0'' - remember we're assuming ideal op amps.)
}\end{prob}
The output is buffered by an opamp, so the output impedance is appreciably $0$.
%%%%%%%%%%%%%%%%%%%%%%%%%%%%%%%%%%%%%%%%%%%%%%%%%%%%%%%%%%%%%%%%%%%%%%%%%%%%%%%%%%%%%%%%%%%%%%
\begin{prob}[3.a]{
Given Ray's description of the circuit operation, find the frequency of the oscillator in Hertz in terms of $I_{freq}$. (To make things easy, assume the reset time is finite.)
}\end{prob}

\begin{prob}[3.b]{
Given you result in part (a), what value of $I_{freq}$ would generate a 440 Hz tone?
}\end{prob}

\begin{prob}[3.c]{
Now let's get some practice in reasoning with tempco resistors (see your notes from class session 7). Suppose that R8, R10, R18, R23, R27 aren't there, and we'll focus just on the CV1 input through R15. What is the output of U1-A (pin 1) as a function of voltage CV1 if the tempco is at a temperature of 25 degrees celcius (the base resistance is 2K for 25 degrees celcius)?
}\end{prob}

\begin{prob}[3.d]{
Now suppose you're using Ray's VCO circuit to make sound for an art installation at the Burning Man Project, which can get up to and above 100 degrees fahrenheit during the day. Redo problem (c), except use a temperature of 40 degrees celcius instead of 25 degrees celcius.
}\end{prob}

\end{document}

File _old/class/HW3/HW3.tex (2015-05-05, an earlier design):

\documentclass[12pt]{article}
\usepackage{amssymb, amsthm, graphics, graphicx}
\usepackage{amsmath}

%these are initial settings. Ron recommended them, so that's just what I use.
\textwidth = 6.5 in
\textheight = 9 in
\oddsidemargin = 0.0 in
\evensidemargin = 0.0 in
\topmargin = -.75in
\parskip = 0.2 in
\parindent = 15 pt
\renewcommand{\baselinestretch}{1.25}

\providecommand{\e}[1]{\ensuremath{\times 10^{#1}}}
\providecommand{\degree}[0]{\ensuremath{^{\circ}}}

\providecommand{\ah}[1]{\ensuremath{\hat{a}_{#1}}}
\providecommand{\ahx}[0]{\ensuremath{\ah{x}}}
\providecommand{\ahy}[0]{\ensuremath{\ah{y}}}
\providecommand{\ahz}[0]{\ensuremath{\ah{z}}}
\providecommand{\pfs}[0]{\ensuremath{\epsilon_{0}}} %permittivity of free space => 1/(36\pi) \e{-9}
%\providecommand{\vec}[1]{\ensuremath{\textbf{#1}}} %vector notation ACTUALLY \vec is _real_ vector notation
\providecommand{\ohm}[0]{\ensuremath{\Omega}}

\newtheorem*{prob}{Problem}

\begin{document}
\begin{flushright}
\textbf{Charles Julian Knight}\\
ECE4893\\
\today
\end{flushright}

\begin{center}
\huge HW 3
\end{center}

\begin{prob}[1.a]{
}\end{prob}
With the 4066 open, the non-inverting input of IC2 is at 
\[\frac{24k}{24k+4.7M}15V \approx .076V\]
Let's call this $V_m$. We've got two inputs into the inverting amp
configuration, so
\[\frac{V_m - V_{saw}}{11k} = \frac{V_{tri}-V_m}{22k} + \frac{-15 - V_m}{82k}\]
\[V_{saw} = -11k \left( \frac{V_{tri}-V_m}{22k} + \frac{-15 - V_m}{82k}\right) + V_m \]
\[ = 1.63V_m - 0.5V_{tri}+2.01V = 2.13V - 0.5V_{tri}\]

\begin{prob}[1.b]{
}\end{prob}
When the 4066 is closed, $V_m$ becomes dependant on $V_{tri}$ also. 
\[V_m = .076 + \frac{56k}{56k+16k}V_{tri} = .076 + .777V_{tri}\]
\[V_{saw} =1.63(.076 + .777V_{tri}) - 0.5V_{tri}+2.01V = 2.14V + .77V_{tri} \]

\begin{prob}[3]{
}\end{prob}
If we apply the ideal opamp rules, what we have is an RC network like this:
\begin{center}
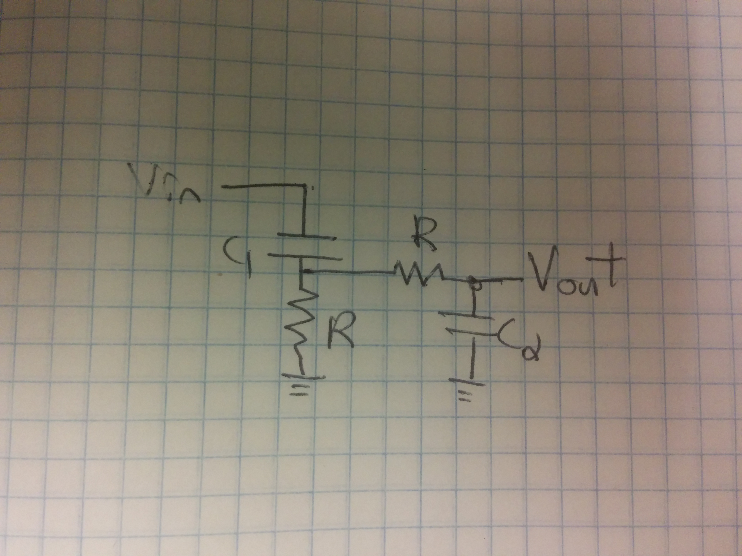
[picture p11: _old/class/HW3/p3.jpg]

\end{center}
We can look at $V_{out}$ as the cascade of two impedance ladders.
Let's let $Z_1 = 1/sC_1$ and $Z_2=1/sC_2$.
\[V_{out} = \left( \frac{R||(Z_2+R)}{Z_1+R||(Z_2+R)} \right)\left( \frac{Z_2}{R+Z_2} \right)V_{in}\]
%\[V_{out} = \left(\frac{R}{\frac{1}{sC_1}+R}\right)\left(\frac{\frac{1}{sC_2}}{\frac{1}{sC_2}+R}\right)V_{in}\]
%\[T(s) = \frac{V_{out}}{V_{in}} = \frac{ \frac{R}{sC_2} }{ \frac{1}{s^2 C_1 C_2} + \frac{R}{sC_1}+ \frac{R}{sC_2} +R^2 }\]
%Multiplyng top and bottom by $\frac{sC_2}{R}$,
If we dump this into Wolfram$|$Alpha, this simplifies to
\[T(s) = \frac{RZ_2}{R^2 + RZ_2 + 2RZ_1 + Z_1Z_2}\]
If we divide the numerator and denomonator by $RZ_2$,
\[T(s) = \frac{1}{R/Z_2 + 1 + 2Z_1/Z_2 + Z_1/R} = \frac{1}{RC_2s + \frac{1}{RC_1s} + 2C_1/C_2 + 1}\]
\[= \frac{s}{RC_2s^2 + (2C_1/C_2 + 1)s+ \frac{1}{RC_1}}\]
This looks like a bandpass filter as expected. This makes sense, because the signal goes through the capacitor
in the first stage (a high pass pattern).

\end{document}

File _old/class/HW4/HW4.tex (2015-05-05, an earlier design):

\documentclass[12pt]{article}
\usepackage{amssymb, amsthm, graphics, graphicx}
\usepackage{amsmath}

%these are initial settings. Ron recommended them, so that's just what I use.
\textwidth = 6.5 in
\textheight = 9 in
\oddsidemargin = 0.0 in
\evensidemargin = 0.0 in
\topmargin = -.75in
\parskip = 0.2 in
\parindent = 15 pt
\renewcommand{\baselinestretch}{1.25}

\providecommand{\e}[1]{\ensuremath{\times 10^{#1}}}
\providecommand{\degree}[0]{\ensuremath{^{\circ}}}

\providecommand{\ah}[1]{\ensuremath{\hat{a}_{#1}}}
\providecommand{\ahx}[0]{\ensuremath{\ah{x}}}
\providecommand{\ahy}[0]{\ensuremath{\ah{y}}}
\providecommand{\ahz}[0]{\ensuremath{\ah{z}}}
\providecommand{\pfs}[0]{\ensuremath{\epsilon_{0}}} %permittivity of free space => 1/(36\pi) \e{-9}
%\providecommand{\vec}[1]{\ensuremath{\textbf{#1}}} %vector notation ACTUALLY \vec is _real_ vector notation
\providecommand{\ohm}[0]{\ensuremath{\Omega}}
\providecommand{\jw}[0]{\ensuremath{j \omega}}

\newtheorem*{prob}{Problem}

\begin{document}
\begin{flushright}
\textbf{Charles Julian Knight}\\
ECE4893\\
\today
\end{flushright}

\begin{center}
\huge HW 4
\end{center}

\begin{prob}[1.a]{
Assume that the transductance gain of the OTA is $19.2*I_{con}$, where $I_{con}$ is the current flowing into the control pin of the OTA. What is the cutoff frequency of the filter block in terms of ($I_{con}$) in Hertz?
}\end{prob}
From our linear-region OTA equation, and using the input voltage divider $\frac{1k}{100k+1k}\approx .01$,

\[I_o = 19.1 I_{con}(0-.01 V_i)\]

This is then fed into the capacitor (as we assume the buffer input impedance is infinite). To avoid calculus, let's stay in the
frequency domain:

\[V_o = I_o Z_c = \frac{19.1 I_{con}(0-.01 V_i)}{\jw C} = \frac{-.191 I_{con}V_i}{\jw C}\]
Since the buffer is an ideal non-inverting, we can expect this to be the same on the other side. The transfer function is then
\[H(s) = \frac{1}{s \frac{C}{-.191I_{con}}}\]

where $\frac{C}{-.191I_{con}}$ is our ``kinda RC'' constant which defines our cutoff frequency.

\[f_o = \frac{.191I_{con}}{100p} = 1.91\e{9}I_{con} Hz \]

\begin{prob}[1.b]{
Given the result in (a), what value $I_{con}$ would be needed for the cutoff frequency of one stage to be 1000 Hz?
}\end{prob}
\[I_{con} = 1000/1.91\e{9} = 52.4 \mu A \]
This sounds too small. I expected something in the small mA range. I don't see any order-of-magnitude errors in my calculation though.

\begin{prob}[1.c]{
Now let's consider the full four-pole cascade with feedback level denoted as K, as in lecture. Let the cutoff frequency of a single stage be 1000 Hz. Using MATLAB, Mathematica, Maple, or some similar tool, on the same plot, show the magnitude of the frequency response (with the horizontal axis in Hertz), from DC to some value that you think best shows off the curves, for four cases: K=0, K just big enough so that you can just barely see a resonance ``bump'' in the curve, K close to 4 (but not so big that it swamps your other curves), and a K somewhere between the last two cases that you think is interesting.
}\end{prob}

Below are log-log plots (from 2Hz to 20KHz) of $K \in [0, .8, 3, 3.9]$. I used $0.8$ because, just as with second-order lowpass filters, the Butterworth response occurs at $K=.707$ so I picked a slightly larger value.  

\begin{center}
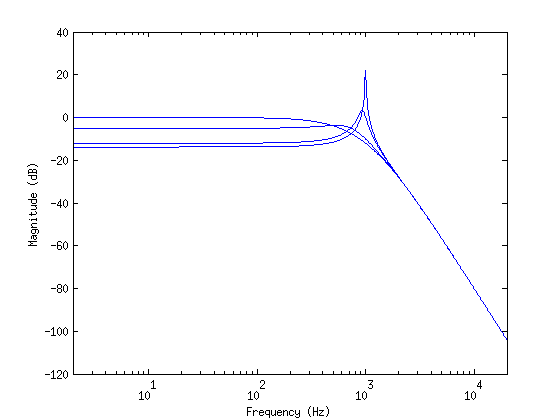
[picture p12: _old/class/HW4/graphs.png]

\end{center}

Below are the MATLAB-computed DC magnitudes for each K value. They agree with the expected $\frac{1}{1+K}$ to 4 decimal places.

\[ [1.0000, 0.5556, 0.2500, 0.2041] \]

%%%%%%%%%%%%%%%%%%%%%%%%%%%%%%%%%%%%%%%%%%%%%%%%%%%%%%%%%%%%%%%%%%%%%%%%%%%%%%%%%

\begin{prob}[2.a]{
Using this formula, find the cutoff frequency (in Hertz) of one of those sections in the Minimoog's transistor ladder as a function of the control current being pulled from the tied emitters of the transistor pair that feeds the ladder.
}\end{prob}

\[ f_c = \frac{1}{8\pi C V_T}I_f = (4.42\e{-8}HzA^{-1}) I_f \]

For a cutoff in the KHz range, this is again a control current in the 10s of $\mu A$ range.

\begin{prob}[2.b]{
Let's do some DC analysis. At DC, the caps are open circuits. For the purpose of this analysis, ignore R76 (the 330 ohm resistor) and the R73 (the 1K regeneration calibration pot); treat them as ``open'' too. Supposing that the transistors draw negligible current through the bases, what are the voltages at the bases of the four stages of the ladder? (Number the stages 1 through 4, from bottom to top; the first stage is Q23/Q24, the second is Q19/A20, the third is Q10/11, and the fourth is Q2/Q3).
}\end{prob}

At DC, we have a resistor ladder from $10V$ to ground: $[ 220\ohm, 150\ohm, 150\ohm, 150\ohm, 200\ohm ]$. The total is $870\ohm$.

\[ V_{b,stage1} = 10\frac{200}{870} = 2.30V \]
\[ V_{b,stage2} = 10\frac{350}{870} = 4.02V \]
\[ V_{b,stage3} = 10\frac{500}{870} = 5.75V \]
\[ V_{b,stage4} = 10\frac{650}{870} = 7.47V \]

%%%%%%%%%%%%%%%%%%%%%%%%%%%%%%%%%%%%%%%%%%%%%%%%%%%%%%%%%%%%%%%%%%%%%%%%%%%%%%%%%

\begin{prob}[3.a]{
Assuming a negative feedback factor of K, find the closed-loop transfer function of the complete filter. Write your answer so that it has $\omega_c^2$ in the numerator and a quadratic polynomial in s in the denominator. Make sure the highest power of s has unit coefficient, i.e. a coefficient of 1.
}\end{prob}
We can use the same equation for the four-pole version on the two-pole version, but updating the order:
\[ H_2(s) = \frac{\omega_c^2}{(s+\omega_c)^2 + K\omega_c^2} \]

\begin{prob}[3.b]{
 In class on March 5, we looked at a canonical lowpass 2nd-order filter transfer function of the form $\frac{\omega_n^2 }{s^2 + (\omega_n / Q) s + \omega_n^2}$, where $\omega_n$ was the ``natural frequency'' and Q was the ``quality factor.'' If you put your answer to (a) in this form, what are $\omega_n$ and Q in terms of $\omega_c$ and K?
}\end{prob}

\[ H_2(s) = \frac{\omega_c^2}{(s+\omega_c)^2 + K\omega_c^2} = \frac{\omega_c^2}{s^2+2\omega_cs + \omega_c^2 + K\omega_c^2} \]

\[ = \frac{\omega_c^2}{s^2+2\omega_cs + (1+K)\omega_c^2} \]

Thus, $\omega_n = \sqrt{1+K}\omega_c$ and $Q= \frac{1}{2\sqrt{1+K}}$.

\begin{prob}[3.c]{
What are $\omega_n$ and Q for the special case of K = 0 (i.e. no feedback)?
}\end{prob}
In this case, the equation simplifies to the normal 2nd order filter form, and $\omega_n=\omega_c$, and $Q=1/2$.

\begin{prob}[3.d]{
For what values of K does the filter exhibit a resonance bump, i.e. for what values of K is $Q > 1/\sqrt{2}$?
}\end{prob}

\[ Q = \frac{1}{2\sqrt{1+K}} > \frac{1}{\sqrt{2}} \]
\[ \frac{1}{4(1+K)} > \frac{1}{2}  \]
\[ 4(1+K) < 2 \]
\[ K < -2 \]

\begin{prob}[3.e]{
 Using the quadratic formula, find the locations of the poles of this filter as a function of $\omega_c$ and K.
}\end{prob}

\[ s_p = \frac{-(2)\pm \sqrt{2^2 - 4(1+K)}}{2} = \frac{-2\pm \sqrt{-K}}{2} \]

\begin{prob}[3.f]{
Where are the poles for the special case of K = 0?
}\end{prob}
\[ s_p0 = \frac{-2\pm \sqrt{0}}{2} = -1 \]
Thus, they are both at $-1$ (still on the real axis).

\begin{prob}[3.g]{
Describe how the poles move as K increases.
}\end{prob}

Using MATLAB, we can graph the poles for a few values. Below are plots for $K \in [-0.1, 0, .5]$. For negative values\footnote{Meaing positive feedback, I think? Nothing meaningful in the real world, in any case.} of K, the poles move along the real axis. At $K=0$ they meet, and above that they begin to move along the imaginary axis.

\begin{center}
% \includegraphics[width=2in]{k-2.png}
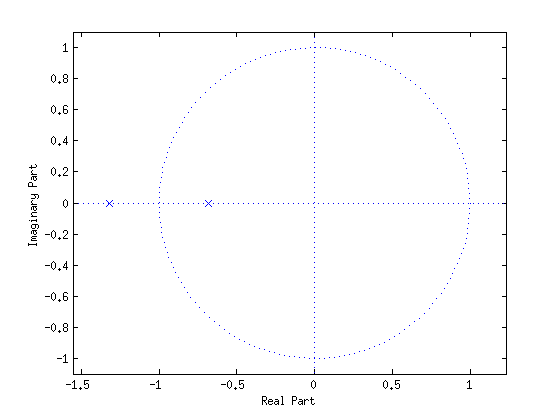
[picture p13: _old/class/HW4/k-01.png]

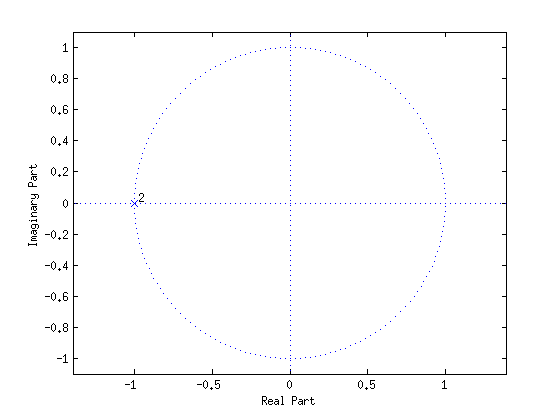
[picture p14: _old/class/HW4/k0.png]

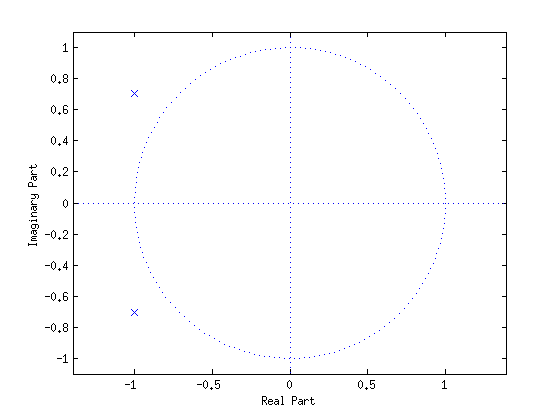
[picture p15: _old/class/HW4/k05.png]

% \includegraphics[width=2in]{k1.png}
\end{center}

\begin{prob}[3.h]{
Can this filter be made to self-oscillate like the four-pole-casade-with-feedback filter explored in the pervious problems? In other words, is there a value of $K > 0$ for which the poles can be made to lie on the imaginary axis?
}\end{prob}

No, because for $K>0$, the poles move only along the imaginary axis.

With negative values of K, one pole approaches the imaginary axis, and would cross at $K=-1$. But of course, if $K=-1$ then your $s^0$ term drops out and you loose an order and the pole disappears. Below are plots for $K \in [-0.9, -1, -11]$ to demonstrate.

\begin{center}
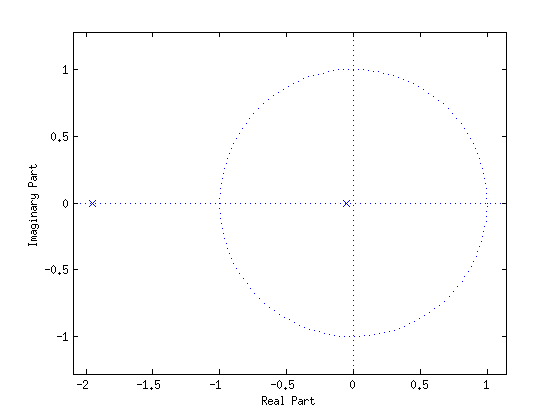
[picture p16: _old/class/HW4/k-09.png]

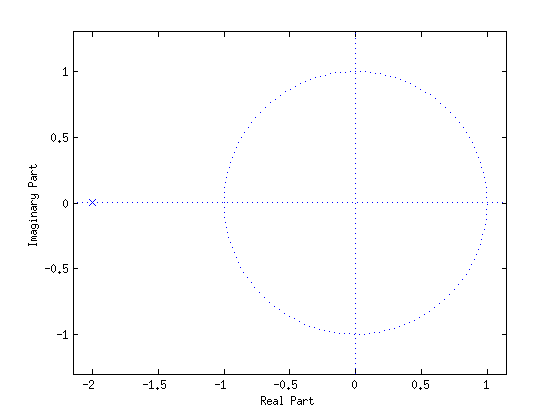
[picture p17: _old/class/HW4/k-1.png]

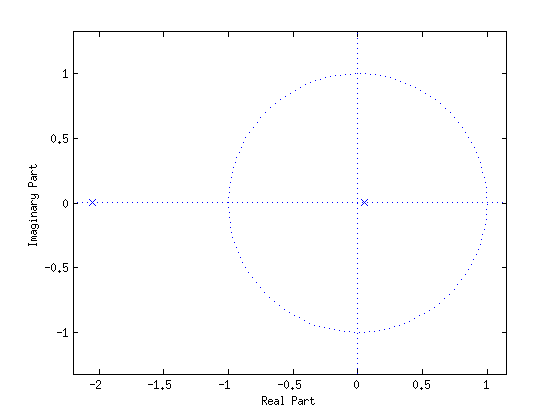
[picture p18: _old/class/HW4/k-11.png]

\end{center}

%\[ H(s) = \frac{\omega_c^2}{(s+\omega_c)^2 + K\omega_c^2}\frac{\omega_c^2}{(s+\omega_c)^2 + K\omega_c^2} \]

\end{document}

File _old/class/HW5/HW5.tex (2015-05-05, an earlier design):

\documentclass[12pt]{article}
\usepackage{amssymb, amsthm, graphics, graphicx}
\usepackage{amsmath}

%these are initial settings. Ron recommended them, so that's just what I use.
\textwidth = 6.5 in
\textheight = 9 in
\oddsidemargin = 0.0 in
\evensidemargin = 0.0 in
\topmargin = -.75in
\parskip = 0.2 in
\parindent = 15 pt
\renewcommand{\baselinestretch}{1.25}

\providecommand{\e}[1]{\ensuremath{\times 10^{#1}}}
\providecommand{\degree}[0]{\ensuremath{^{\circ}}}

\providecommand{\ah}[1]{\ensuremath{\hat{a}_{#1}}}
\providecommand{\ahx}[0]{\ensuremath{\ah{x}}}
\providecommand{\ahy}[0]{\ensuremath{\ah{y}}}
\providecommand{\ahz}[0]{\ensuremath{\ah{z}}}
\providecommand{\pfs}[0]{\ensuremath{\epsilon_{0}}} %permittivity of free space => 1/(36\pi) \e{-9}
%\providecommand{\vec}[1]{\ensuremath{\textbf{#1}}} %vector notation ACTUALLY \vec is _real_ vector notation
\providecommand{\ohm}[0]{\ensuremath{\Omega}}

\newtheorem*{prob}{Problem}

\begin{document}
\begin{flushright}
\textbf{Charles Julian Knight}\\
ECE4893\\
\today
\end{flushright}

\begin{center}
\huge HW 5
\end{center}

\begin{prob}[1.a]{
Find the $f_n$, the natural frequency of the 2nd-order filter in Hz, for the following four conditions:
\begin{itemize}
  \item Caps C5 and C7 switched ``out'' LDRs = infinite ohm
  \item Caps C5 and C7 switched ``out'' LDRs = 5 kohm
  \item Caps C5 and C7 switched ``in'' LDRs = infinite ohm
  \item Caps C5 and C7 switched ``in'' LDRs = 5 kohms
\end{itemize}
}\end{prob}
\begin{itemize}
  \item Case 1: 
    \[ \frac{1}{2\pi (R8)(C6)} = \frac{1}{2\pi (220K) (1.8nF)} = 401.9 Hz \]
  \item Case 2:
    \[ \frac{1}{2\pi (R8||R_{LDR})(C6)} = \frac{1}{2\pi (220K||5K) (1.8nF)} = 18.09 KHz \]
  \item Case 3:
    \[ \frac{1}{2\pi (R8)(C6+C5)} = \frac{1}{2\pi (220K) (1.8nF+2.2nF)} = 180.9 Hz \]
  \item Case 4:
    \[ \frac{1}{2\pi (R8||R_{LDR})(C6+C5)} = \frac{1}{2\pi (220K||5K) (1.8nF+2.2nF)} = 8.140 KHz \]
\end{itemize}

\begin{prob}[1.b]{
  According to the VTL5C3/2 datasheet, what control current would generate a 5 kohm LDR resistance? Use curve \#4 on the graph.
}\end{prob}
From the graph, it looks like the current is $6mA$.
\begin{prob}[1.c]{
  Consider the ``Peak'' 150K pot. As the wiper is moved to the left on the schematic, does the Q increase or decrease? Explain your reasoning.
}\end{prob}
  The Peak pot controls the amount of feedback from the first stage back to the input. Both the input stage and the first filter stage are inverting, so the feedback is positive. Thus, decreasing the feedback resistance (pot to the left) increases the ammount of positive feedback, which should increase the Q. 

\begin{prob}[2.a]{
  Are the variable-gain integrators forming this SVF inverting or non-inverting?
}\end{prob}
The op-amp configuration is inverting, but since the OTA is inverting, I think the whole filter will actually act as non-inverting.

\begin{prob}[2.b]{
  Find $f_n$ (the natural frequency in Hertz) as a function of the current fed to the control current inputs of the OTAs. This should be a simple calculation once you find the component values you need.
}\end{prob}
  The voltage divider into the OTA is $\frac{R21}{R21+R20}\approx \frac{22}{10k}= .0022$. The OTA is inverting (because the positive input is grounded), so the current output of the OTA is
    \[19.2 I_{abc}(0-.0022V_{in}) = -(0.042V_{in})I_{abc}\]
  Thus, the conductance of the OTA is thus $.042I_{abc}$. Then we use the ``RC'' time constant to find the natural frequency.
  \[f_n = \frac{1}{2\pi RC}=\frac{1}{2\pi (\frac{1}{.042I_{abc}})(330pF)} = (2.02\e{7})I_{abc}\]

\begin{prob}[2.c]{
  If R16 was increased, would the Q of this filter increase or decrease? Briefly explain your reasoning.
}\end{prob}
Increasing R16 decreases the ammount of feedback, causing Q to decrease.

\begin{prob}[3.a]{
When switched in the lowpass mode, find the OTA control current that would result in a natural frequency (in Hertz), $f_n$, of 2500 Hz. Remember you can fold the $R_{small}/R_{big}$ factor in with the gain of the OTA when using the formula for the critical frequency of a Sallen-Key filter. Because the two capacitor values are the same and the resistor values are the same, this is a relatively simple calculation.
}\end{prob}
The output of the OTA is
\[19.2I_{abc}(0-\frac{220}{10K}V_{in})\]
Thus the conductance is $0.4224I_{abc}$.
\[f_n = 2.5KHz = \frac{1}{2\pi (\frac{1}{0.4224I_{abc}})(.002uF)}\]
\[I_{abc} = 7.5\e{-5}A = 74\mu A \]

\begin{prob}[3.b]{
  In the original Korg MS-20, resonance is controlled with a pot. Notice how Tom has modified the circuit to make the resonance voltage controllable. In class, we showed that for this ``Bach'' topology, a feedback of K < 2 is needed, or else the filter will go unstable. What value of control current for the resonance-controlling OTA would give a feedback of 2?
}\end{prob}
The ammount of feedback is controlled by the ``voltage divider'' $\frac{10K}{10K+R_f}$ where
\[ R_f = 1/g_m = \frac{1}{19.2I_{abc}(1K/47K)}\]
Thus we solve for $I_{abc}$:
\[ 2 = \frac{10K}{10K+\frac{1}{19.2I_{abc}(1K/47K)}} \]
\[ 2\left(10K+\frac{1}{(.41)I_{abc}}\right) = 10K\]
\[20K-10K = -\frac{2}{(.41)I_{abc}} \]
\[I_{abc} = -\frac{2}{(.41)10K} = .49mA\]

\begin{prob}[4.a]{
Find the current through the vactrol diode as a function of the control voltage input at jack 11 in the upper left hand corner of the schematic.
}\end{prob}
Let's call the node voltage to the left of the diode $V_D$. First, there is a virtual ground at the non-inverting opamp input. Thus, the current from the input is 
\[\frac{V_{in}-0}{(470K||100K)}\]
Thus the current to the left of the $V_D$ node is the same. Therefore
\[\frac{V_D-0}{33K+(10K||10K)} = -\frac{V_{in}-0}{(470K||100K)} \]
\[ V_D = \frac{38K}{81K}V_{in} \]
Let's apply the current law to this node to build an expression for $I_D$.
\[ \frac{V_D}{38K} + \frac{V_D-0}{4.7K} + I_D = 0 \]
\[I_D = -\frac{\frac{38K}{81K}V_{in}}{38K} -\frac{\frac{38K}{81K}V_{in}}{4.7K} \]
\[I_D = -\frac{V_{in}}{112\ohm}\]
For $V_{in} = -5V$, the current is about $44mA$, which is on the high end of resonable for an LED. 

\begin{prob}[4.b]{
  Find the voltage at the output terminal of op amp 9 as a function of the control voltage input at jack 11. Assume that the vactrol LED has a ``diode drop'' of 1.65 volts. I found this figure on the VTL5C3 datasheet.
}\end{prob}
The voltage at the output of the opamp is the voltage at $V_D$ minus the diode drop and the drop across R11.
\[V_o = V_D - 1.65 - 470I_D = \frac{38K}{81K}V_{in} + 470\frac{V_{in}}{112\ohm} - 1.65 = 4.67V_{in}-1.65\]
Thus the CV should be pretty low (like $\approx 1V$).

\end{document}

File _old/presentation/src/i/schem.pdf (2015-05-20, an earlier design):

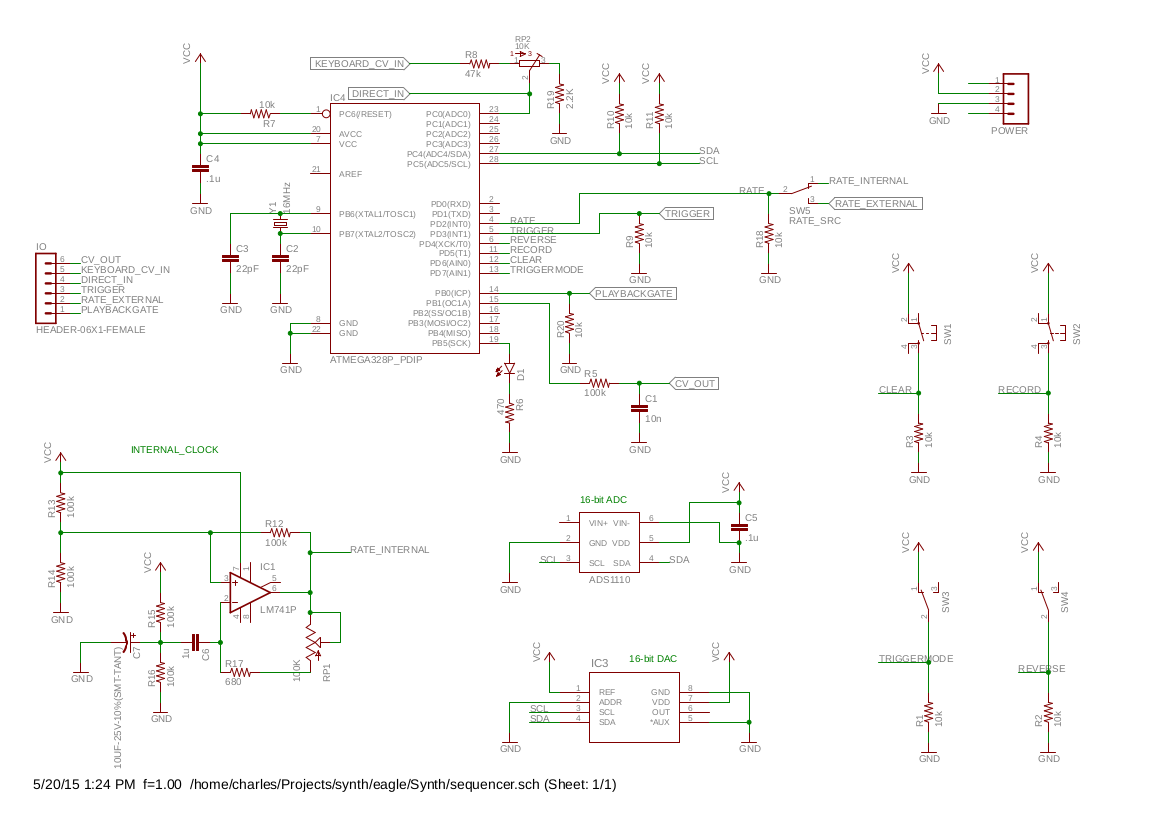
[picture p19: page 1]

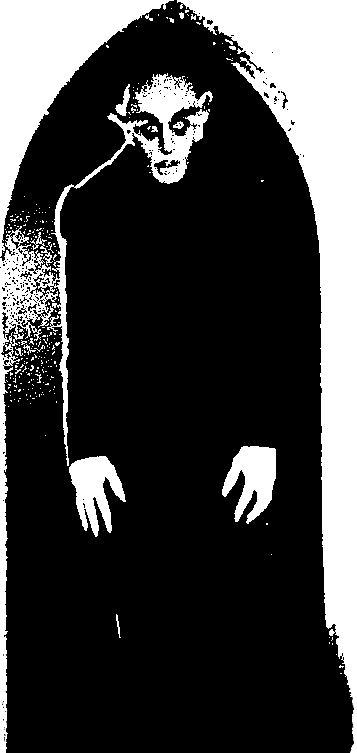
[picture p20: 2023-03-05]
clock/panel/assets/nosferatu-stand-posterize2.png

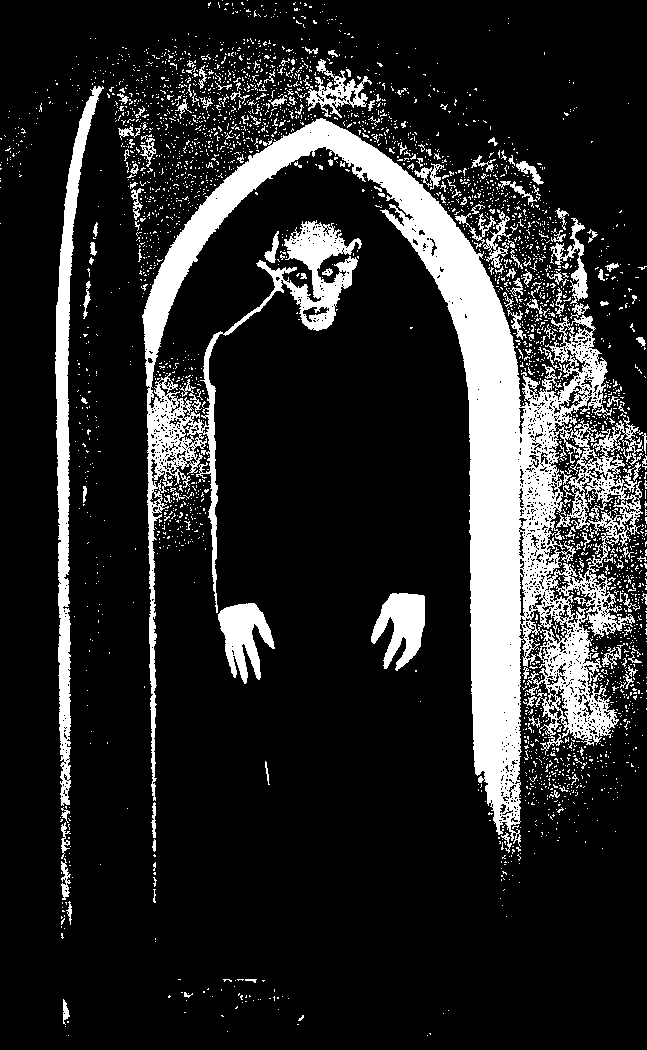
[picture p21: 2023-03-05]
clock/panel/assets/nosferatu-stand-posterize.png

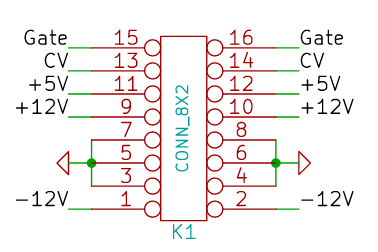
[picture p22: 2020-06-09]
pinout.png

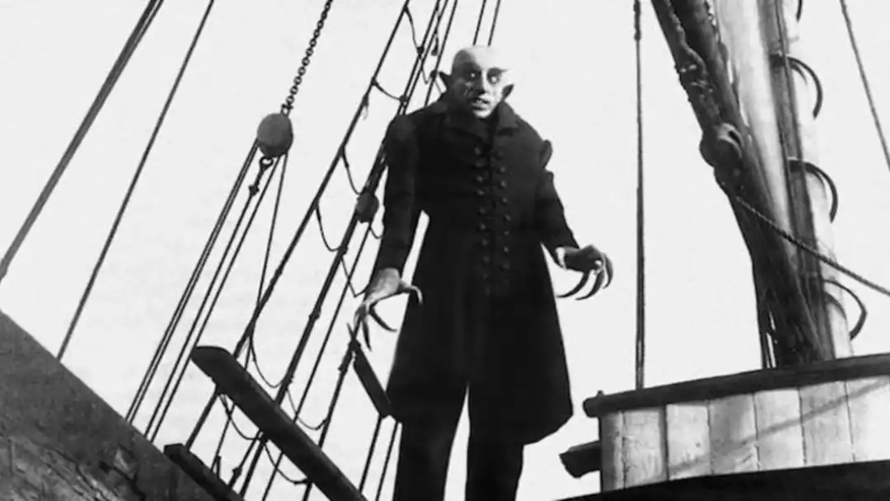
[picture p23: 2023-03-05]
clock/panel/assets/nosferatuhed-b97c5529d344557524657ba57892efc1.webp

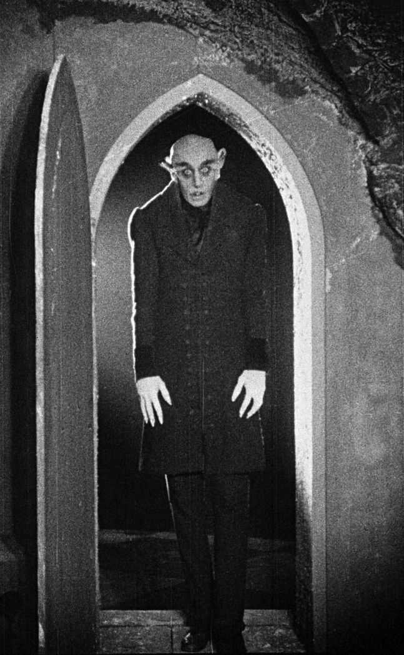
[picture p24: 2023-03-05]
clock/panel/assets/tumblr_649b9087541225a087f87a32f962c9b5_68c0562e_1280.jpg

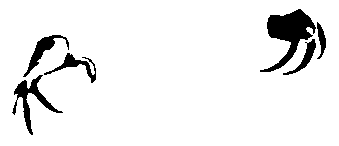
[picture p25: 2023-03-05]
clock/panel/assets/hands.png

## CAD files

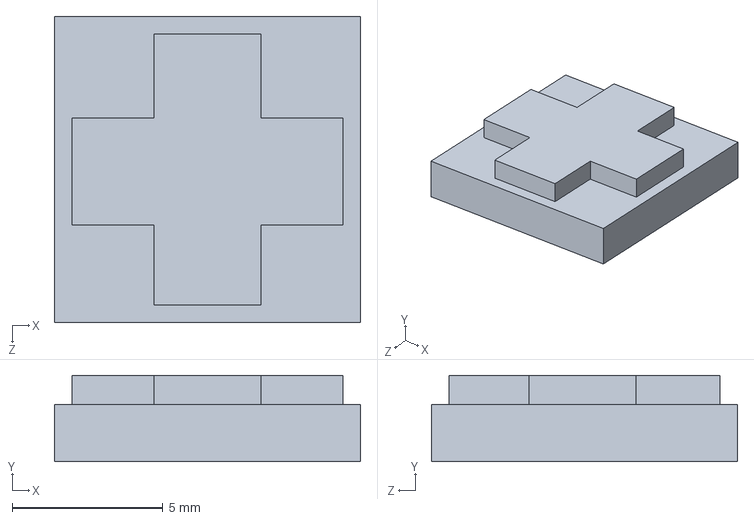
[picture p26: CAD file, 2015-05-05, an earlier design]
_old/class/project/Part22.SLDPRT
10.2 x 2.87 x 10.2 mm

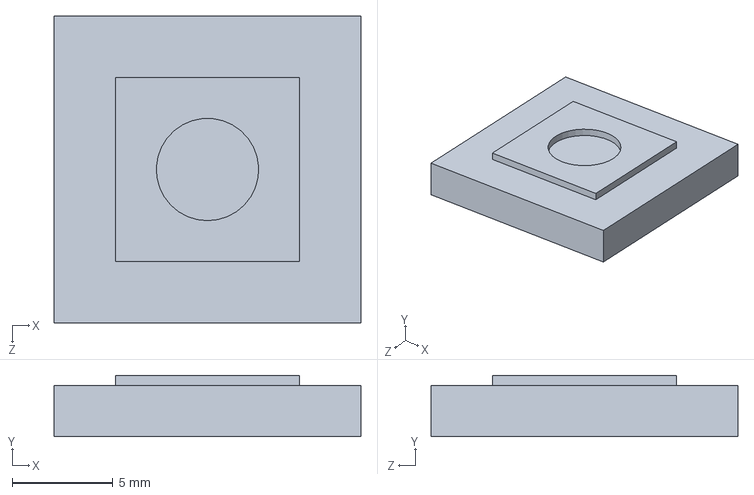
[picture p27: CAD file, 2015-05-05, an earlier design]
_old/class/project/and-a-cherry-on-top.SLDPRT
15.2 x 3.05 x 15.2 mm

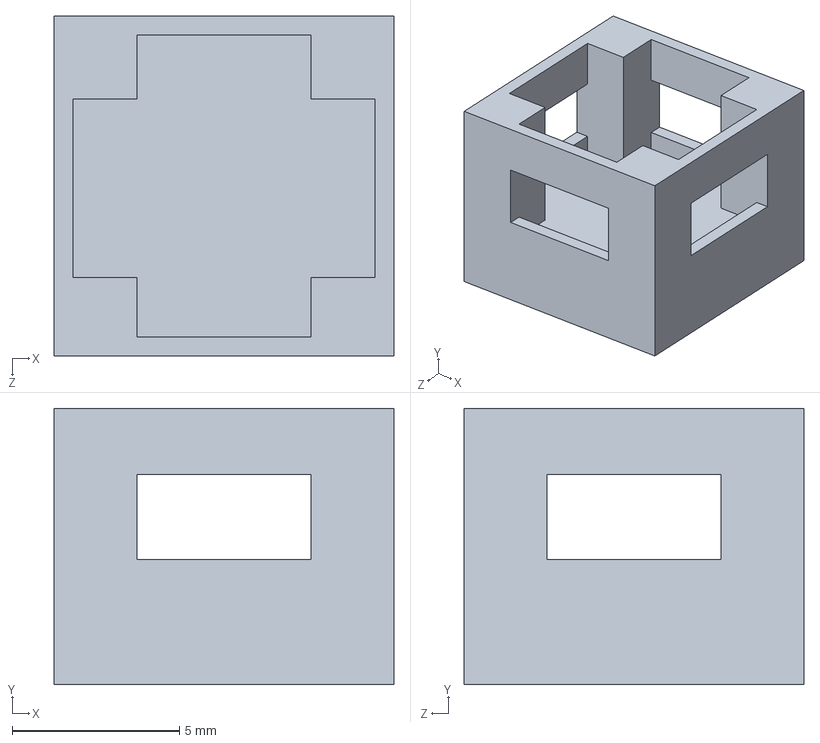
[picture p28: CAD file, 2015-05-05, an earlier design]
_old/class/project/Part2.SLDPRT
10.2 x 8.26 x 10.2 mm

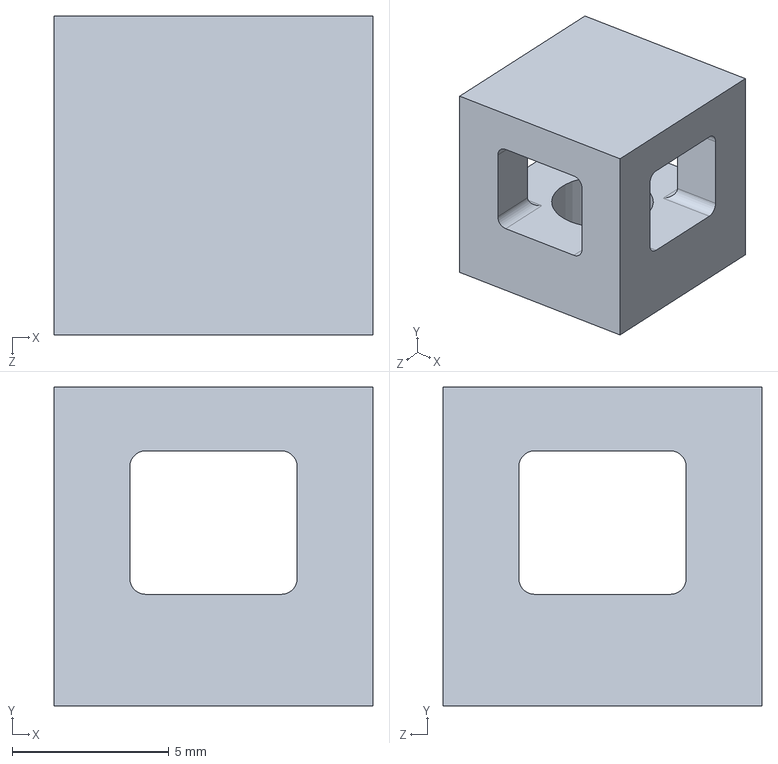
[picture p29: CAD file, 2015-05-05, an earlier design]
_old/class/project/Part1.SLDPRT
10.2 x 10.2 x 10.2 mm

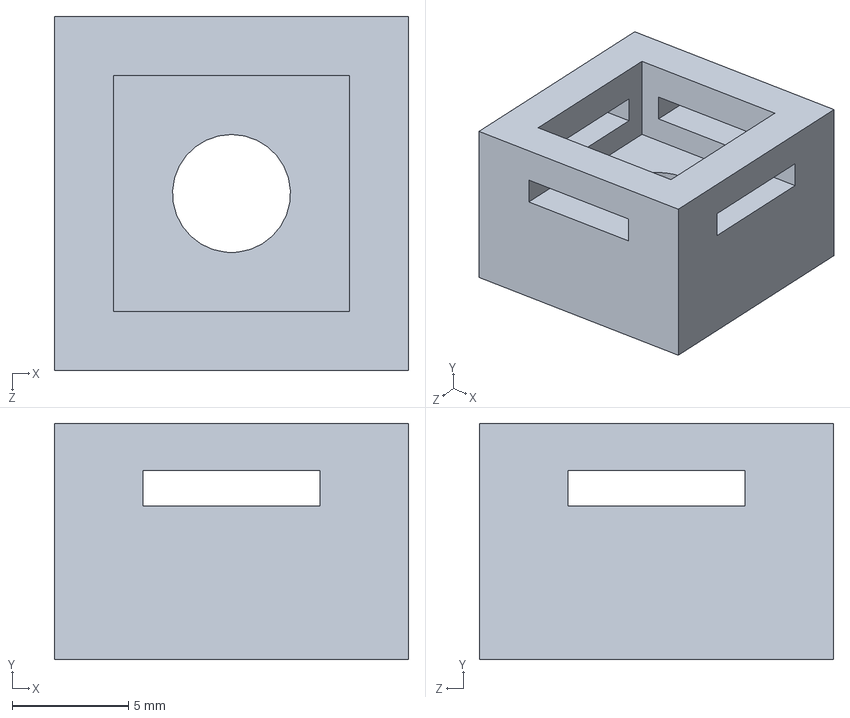
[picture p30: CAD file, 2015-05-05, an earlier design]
_old/class/project/third-times-the-charm.SLDPRT
15.2 x 10.2 x 15.2 mm

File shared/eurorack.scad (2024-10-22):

function hp(count = 1) = count * 5.08 /*mm*/;
function u3() = 128.5;    // mm
function panel_lip() = 8; // mm
function panel_center(width_hp) = [ hp(width_hp) / 2, u3() / 2 ];

// src: https://github.com/elentok/openscad/blob/210b5aa151ece6d43d49d6ab0fd53597e926df5b/lib/rsquare.scad#L31C1-L39C2
module rsquare(size, radius)
{
    x = size.x - radius * 2;
    y = size.y - radius * 2;

    assert(radius < size.x / 2, "Radius must be less than half the height");
    assert(radius < size.y / 2, "Radius must be less than half the width");

    offset(r = radius) square([ x, y ], center = true);
}

module box_outline(size, line_width = 0.25, center = false)
{
    if ($preview)
    {
        if (center)
        {
            difference()
            {
                square(size, center = true);
                square([ size.x - line_width * 2, size.y - line_width * 2 ], center = true);
            }
        }
        else
        {
            difference()
            {
                square(size);
                translate([ line_width, line_width ]) square([ size.x - line_width * 2, size.y - line_width * 2 ]);
            }
        }
    }
}

// place a rectangular grid of count copies of child,
// with row_size items per row, separated by offset.
// Optionally pass an array of 0-indexed indicies to skip
// placement.
module place_grid(count, row_size, offset, skips = [])
{
    for (i = [0:count - 1])
    {
        x = i % row_size;
        y = floor(i / row_size);
        if (len(search(i, skips)) == 0)
        {
            translate([ x * offset.x, -1 * y * offset.y ]) children();
        }
    }
}

module bounds(width_hp)
{
    color("#cccccc") box_outline([ hp(width_hp), u3() ], center = false);
}

module screw(center_pos, circular = false)
{
    drill_w = 5.8;
    drill_h = 4.2;
    screw_dia = 5.82;
    // drill
    translate([ center_pos[0], center_pos[1], 0 ]) color("#000000") if (circular)
    {
        circle(d = drill_h);
    }
    else
    {
        rsquare([ drill_w, drill_h ], (min(drill_w, drill_h) - 0.1) / 2);
    }
    // screw bounds
    if ($preview)
    {
        translate([ center_pos[0], center_pos[1], 0 ]) color("#cccccc")
            box_outline([ screw_dia, screw_dia ], center = true);
    }
}

module screws(width_hp, count_per_side = -1)
{
    count = count_per_side < 0 ? floor(width_hp / 8) + 1 : count_per_side;

    if (count == 1)
    {
        // only draw one in the center
        // bottom screw
        screw([ hp(width_hp) / 2, panel_lip() / 2 ]);
        // top screw
        screw([ hp(width_hp) / 2, u3() - panel_lip() / 2 ]);
    }
    else
    {
        space_between = hp(width_hp - 2) / (count - 1);
        for (i = [0:count - 1])
        {
            // bottom screw
            screw([ hp() + i * space_between, panel_lip() / 2 ]);
            // top screw
            screw([ hp() + i * space_between, u3() - panel_lip() / 2 ]);
        }
    }
}

module jack(center_pos)
{
    drill_dia = 8;
    // jacks = 14mm wide, 9mm high (12+ recommended)
    access_bounds = [ 14, 12 ];
    if ($preview)
    {
        translate([ center_pos[0], center_pos[1], 0 ]) color("#cccccc") box_outline(access_bounds, center = true);
    }
    // drill
    translate([ center_pos[0], center_pos[1], 0 ]) color("#000000") circle(d = drill_dia);
}

module knob(center_pos)
{
    drill_dia = 9;
    // knobs = 22mm square (30mm recommended)
    access_bounds = [ 22, 22 ];
    if ($preview)
    {
        translate([ center_pos[0], center_pos[1], 0 ]) color("#cccccc") box_outline(access_bounds, center = true);
    }
    // drill
    translate([ center_pos[0], center_pos[1], 0 ]) color("#000000") circle(d = drill_dia);
}

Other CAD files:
_old/class/project/Part1-rotated.stl
_old/class/project/Part1.STL
_old/class/project/and-a-cherry-on-top.STL
_old/class/project/third-times-the-charm.STL

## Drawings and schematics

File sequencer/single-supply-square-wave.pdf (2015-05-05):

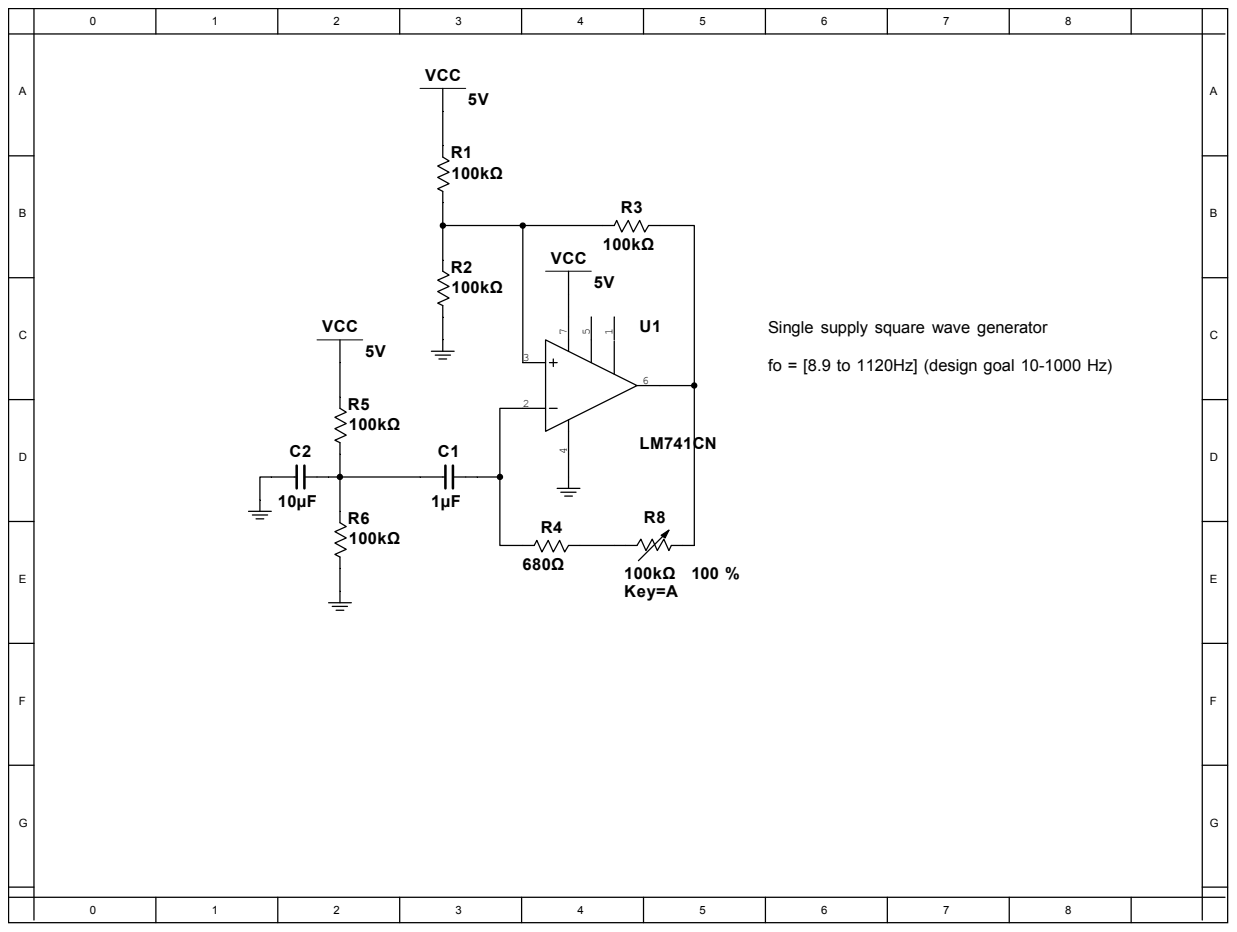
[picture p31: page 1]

Single supply square wave generator

fo = [8.9 to 1120Hz] (design goal 10-1000 Hz)

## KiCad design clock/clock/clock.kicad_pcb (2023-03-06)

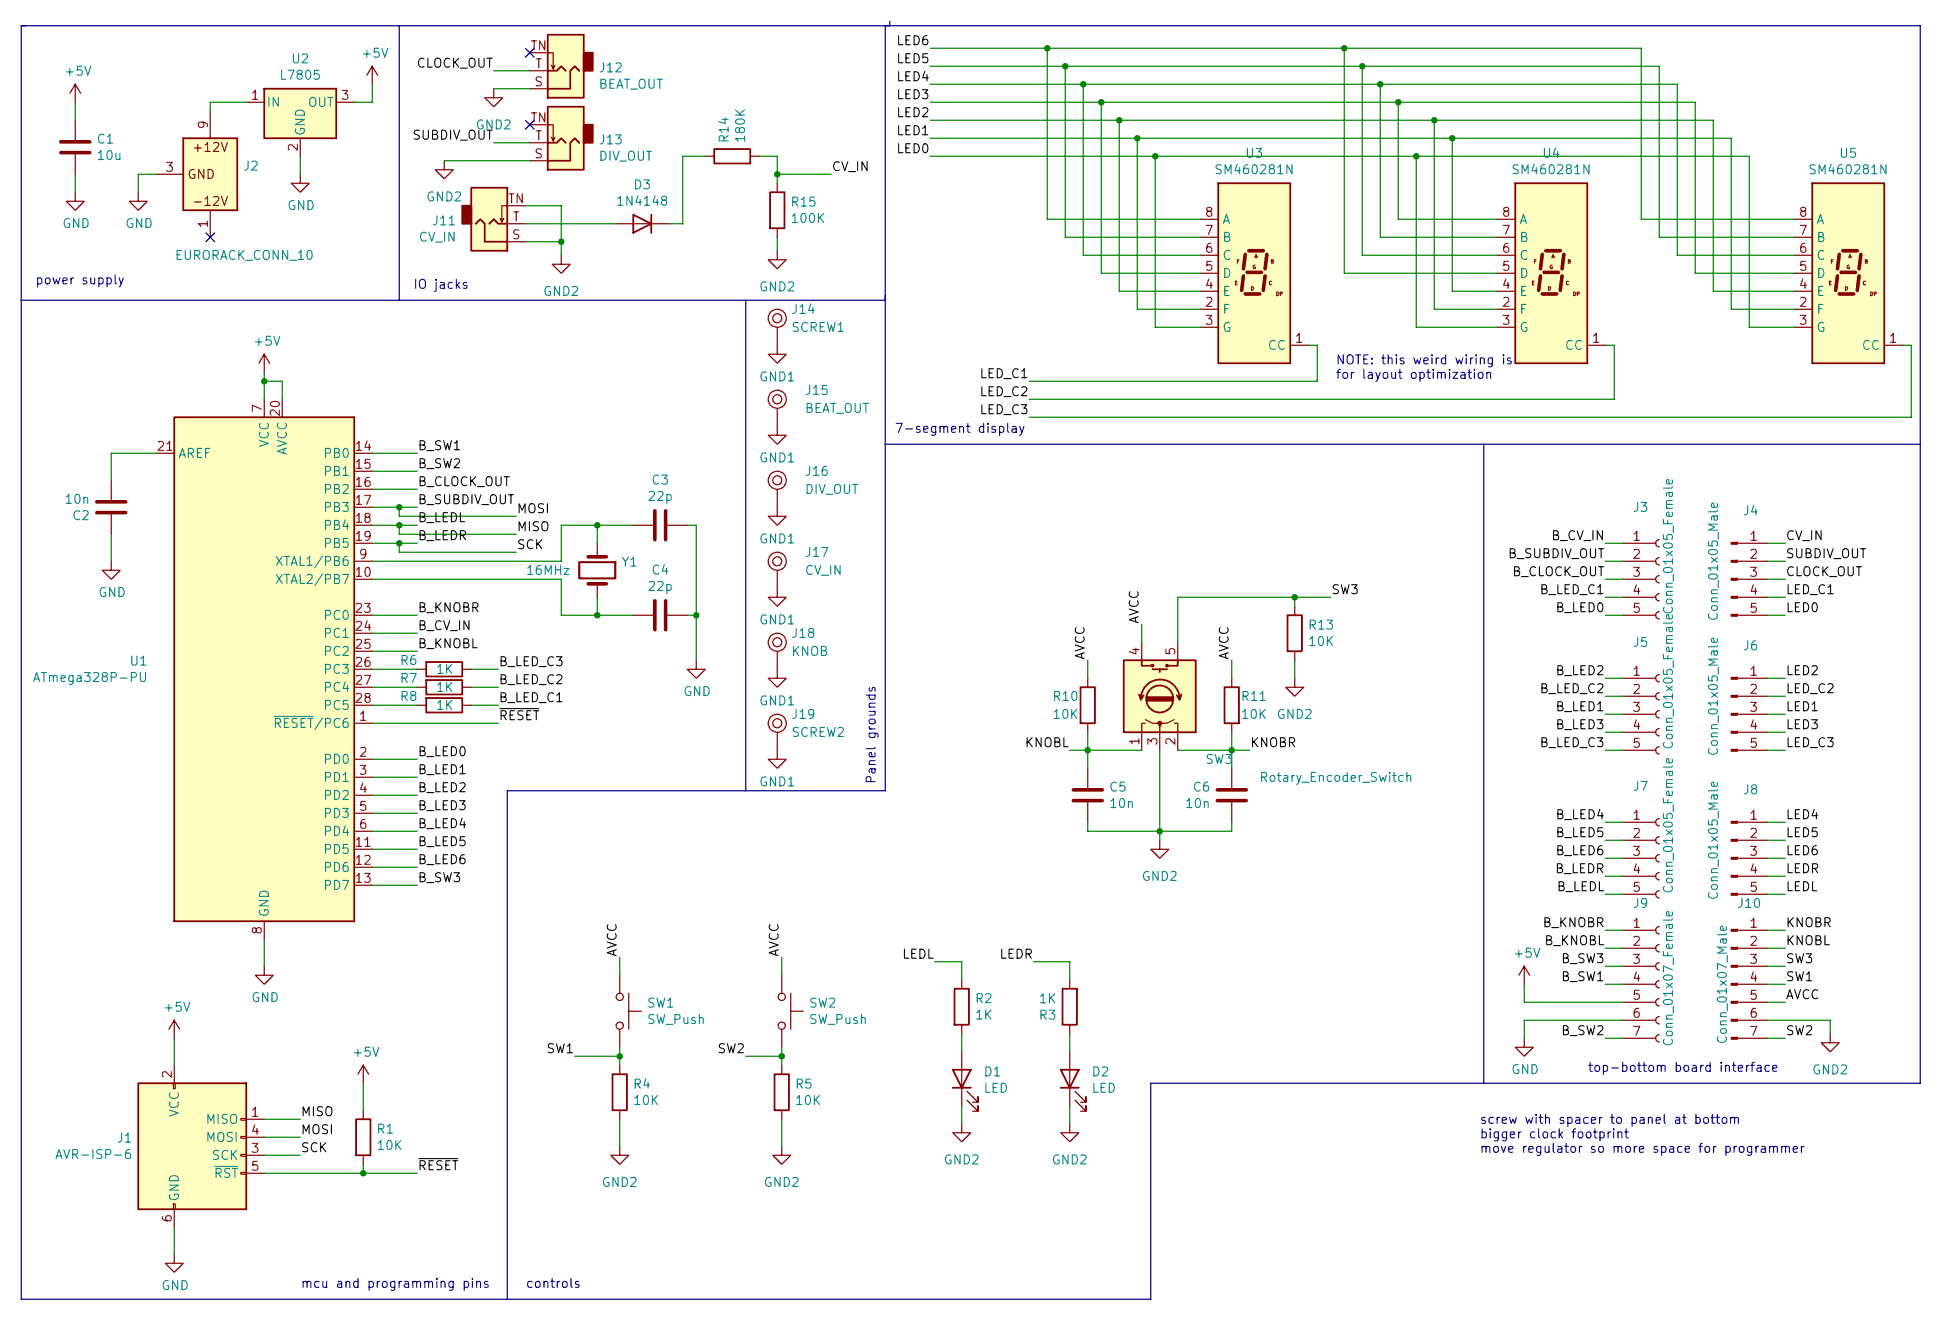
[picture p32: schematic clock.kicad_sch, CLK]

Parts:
C1: 10u; CP_Radial_Tantal_D4.5mm_P2.50mm
C2, C5, C6: 10n; C_Rect_L7.0mm_W3.5mm_P5.00mm
C3, C4: 22p; C_Rect_L7.0mm_W3.5mm_P5.00mm
D1, D2: LED; LED_D3.0mm
D3: 1N4148; D_T-1_P5.08mm_Horizontal
J1: AVR-ISP-6; PinHeader_2x03_P2.54mm_Vertical
J2: EURORACK_CONN_10; EURORACK_10_IDC
J3, J5, J7: Conn_01x05_Female; PinSocket_1x05_P2.54mm_Vertical
J4, J6, J8: Conn_01x05_Male; PinHeader_1x05_P2.54mm_Vertical
J9: Conn_01x07_Female; PinSocket_1x07_P2.54mm_Vertical
J10: Conn_01x07_Male; PinHeader_1x07_P2.54mm_Vertical
J11: CV_IN; Jack_3.5mm_QingPu_WQP-PJ398SM_Vertical_CircularHoles
J12: BEAT_OUT; Jack_3.5mm_QingPu_WQP-PJ398SM_Vertical_CircularHoles
J13: DIV_OUT; Jack_3.5mm_QingPu_WQP-PJ398SM_Vertical_CircularHoles
J14: SCREW1; eurorack_screw_hole
J15: BEAT_OUT; thonkiconn_hole
J16: DIV_OUT; thonkiconn_hole
J17: CV_IN; thonkiconn_hole
J18: KNOB; knob_hole
J19: SCREW2; eurorack_screw_hole
R1, R4, R5, R10, R11, R13: 10K; R_Axial_DIN0207_L6.3mm_D2.5mm_P2.54mm_Vertical
R2, R3, R6, R7, R8: 1K; R_Axial_DIN0207_L6.3mm_D2.5mm_P2.54mm_Vertical
R14: 180K; R_Axial_DIN0207_L6.3mm_D2.5mm_P2.54mm_Vertical
R15: 100K; R_Axial_DIN0207_L6.3mm_D2.5mm_P2.54mm_Vertical
SW1, SW2: SW_Push; SW_PUSH_6mm
SW3: Rotary_Encoder_Switch; RotaryEncoder_Bourns_PEC11R_Vertical_Switch
U1: ATmega328P-PU; DIP-28_W7.62mm
U2: L7805; TO-220-3_Vertical
U3, U4, U5: SM460281N; SM460281N_ARKLED_0.28mm_CC_7-segment_LED
Y1: 16MHz; Crystal_HC52-8mm_Vertical

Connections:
+5V: C1.1, J1.2 (VCC), J9.5, R1.1, U1.7 (VCC), U1.20 (AVCC), U2.3 (OUT)
/AVCC: J10.5, R10.1, R11.1, SW1.1, SW2.1, SW3.4 (S1)
/B_CLOCK_OUT: J3.3, U1.16 (PB2)
/B_CV_IN: J3.1, U1.24 (PC1)
/B_KNOBL: J9.2, U1.25 (PC2)
/B_KNOBR: J9.1, U1.23 (PC0)
/B_LED0: J3.5, U1.2 (PD0)
/B_LED1: J5.3, U1.3 (PD1)
/B_LED2: J5.1, U1.4 (PD2)
/B_LED3: J5.4, U1.5 (PD3)
/B_LED4: J7.1, U1.6 (PD4)
/B_LED5: J7.2, U1.11 (PD5)
/B_LED6: J7.3, U1.12 (PD6)
/B_LEDL: J1.1 (MISO), J7.5, U1.18 (PB4)
/B_LEDR: J1.3 (SCK), J7.4, U1.19 (PB5)
/B_LED_C1: J3.4, R8.1
/B_LED_C2: J5.2, R7.1
/B_LED_C3: J5.5, R6.1
/B_SUBDIV_OUT: J1.4 (MOSI), J3.2, U1.17 (PB3)
/B_SW1: J9.4, U1.14 (PB0)
/B_SW2: J9.7, U1.15 (PB1)
/B_SW3: J9.3, U1.13 (PD7)
/CLOCK_OUT: J4.3, J12.T
/CV_IN: J4.1, R14.2, R15.1
/KNOBL: C5.1, J10.2, R10.2, SW3.1 (A)
/KNOBR: C6.1, J10.1, R11.2, SW3.2 (B)
/LED0: J4.5, U3.3 (G), U4.3 (G), U5.3 (G)
/LED1: J6.3, U3.2 (F), U4.4 (E), U5.2 (F)
/LED2: J6.1, U3.4 (E), U4.2 (F), U5.4 (E)
/LED3: J6.4, U3.5 (D), U4.8 (A), U5.5 (D)
/LED4: J8.1, U3.6 (C), U4.7 (B), U5.6 (C)
/LED5: J8.2, U3.7 (B), U4.6 (C), U5.7 (B)
/LED6: J8.3, U3.8 (A), U4.5 (D), U5.8 (A)
/LEDL: J8.5, R2.1
/LEDR: J8.4, R3.2
/LED_C1: J4.4, U3.1 (CC)
/LED_C2: J6.2, U4.1 (CC)
/LED_C3: J6.5, U5.1 (CC)
/SUBDIV_OUT: J4.2, J13.T
/SW1: J10.4, R4.1, SW1.2
/SW2: J10.7, R5.1, SW2.2
/SW3: J10.3, R13.1, SW3.5 (S2)
/~RESET: J1.5 (~RST), R1.2, U1.1 (~RESET/PC6)
GND: C1.2, C2.1, C3.1, C4.1, J1.6 (GND), J2.3 (GND), J9.6, U1.8 (GND), U1.22 (GND), U2.2 (GND)
GND1: J14.1, J15.1, J16.1, J17.1, J18.1, J19.1
GND2: C5.2, C6.2, D1.1 (K), D2.1 (K), J10.6, J11.S, J11.TN, J12.S, J13.S, R4.2, R5.2, R13.2, R15.2, SW3.3 (C)
unnamed: C2.2, U1.21 (AREF)
unnamed: C3.2, U1.9 (XTAL1/PB6), Y1.1
unnamed: C4.2, U1.10 (XTAL2/PB7), Y1.2
unnamed: D1.2 (A), R2.2
unnamed: D2.2 (A), R3.1
unnamed: D3.1 (K), R14.1
unnamed: D3.2 (A), J11.T
unnamed: J2.9 (12V_P), U2.1 (IN)
unnamed: R6.2, U1.26 (PC3)
unnamed: R7.2, U1.27 (PC4)
unnamed: R8.2, U1.28 (PC5)

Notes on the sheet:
NOTE: this weird wiring is for layout optimization
7-segment display
Panel grounds
top-bottom board interface
power supply
screw with spacer to panel at bottom bigger clock footprint move regulator so more space for programmer
mcu and programming pins
IO jacks
controls

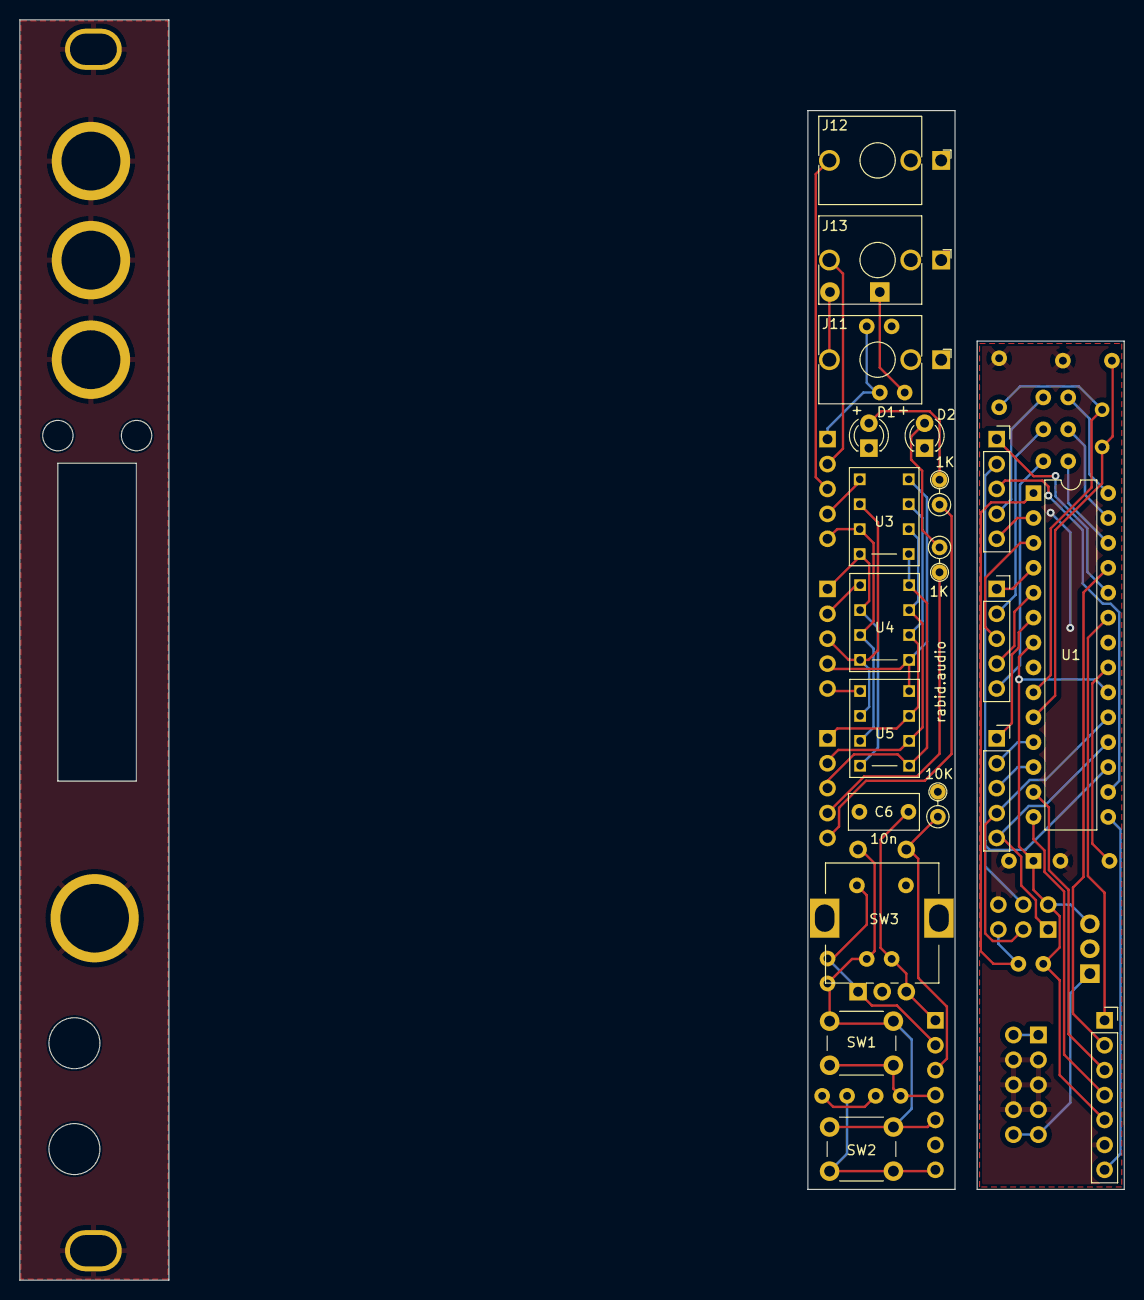
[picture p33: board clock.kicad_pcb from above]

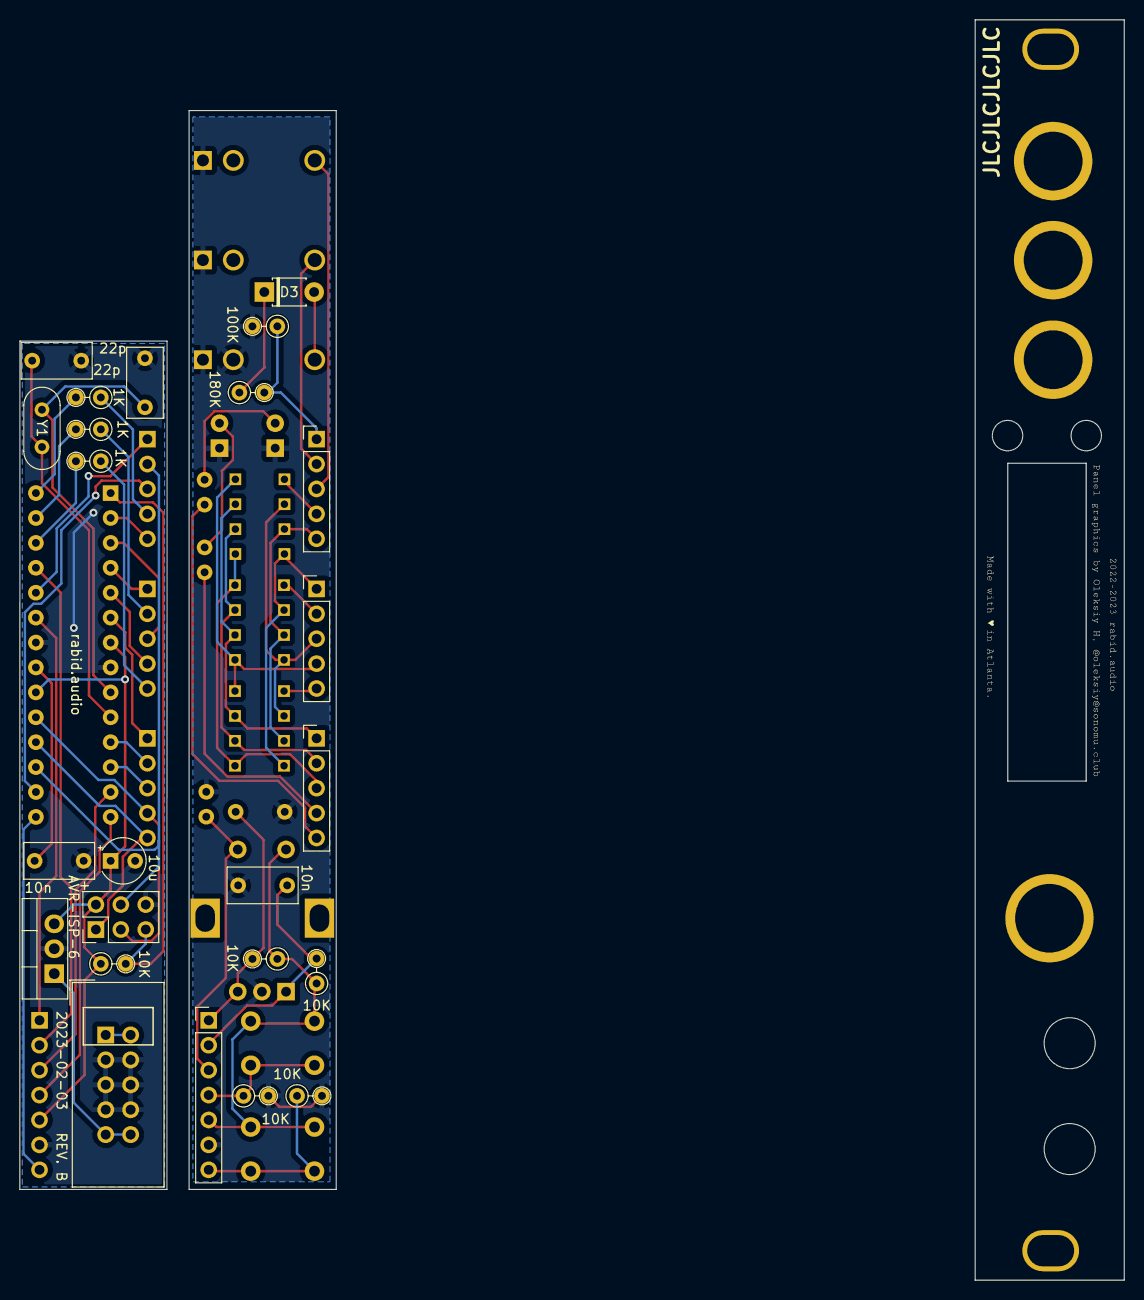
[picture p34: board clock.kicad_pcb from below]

Board: 2 copper layers, 112.6 x 128.5 mm, 50 parts (24 on the bottom side), 57 nets.

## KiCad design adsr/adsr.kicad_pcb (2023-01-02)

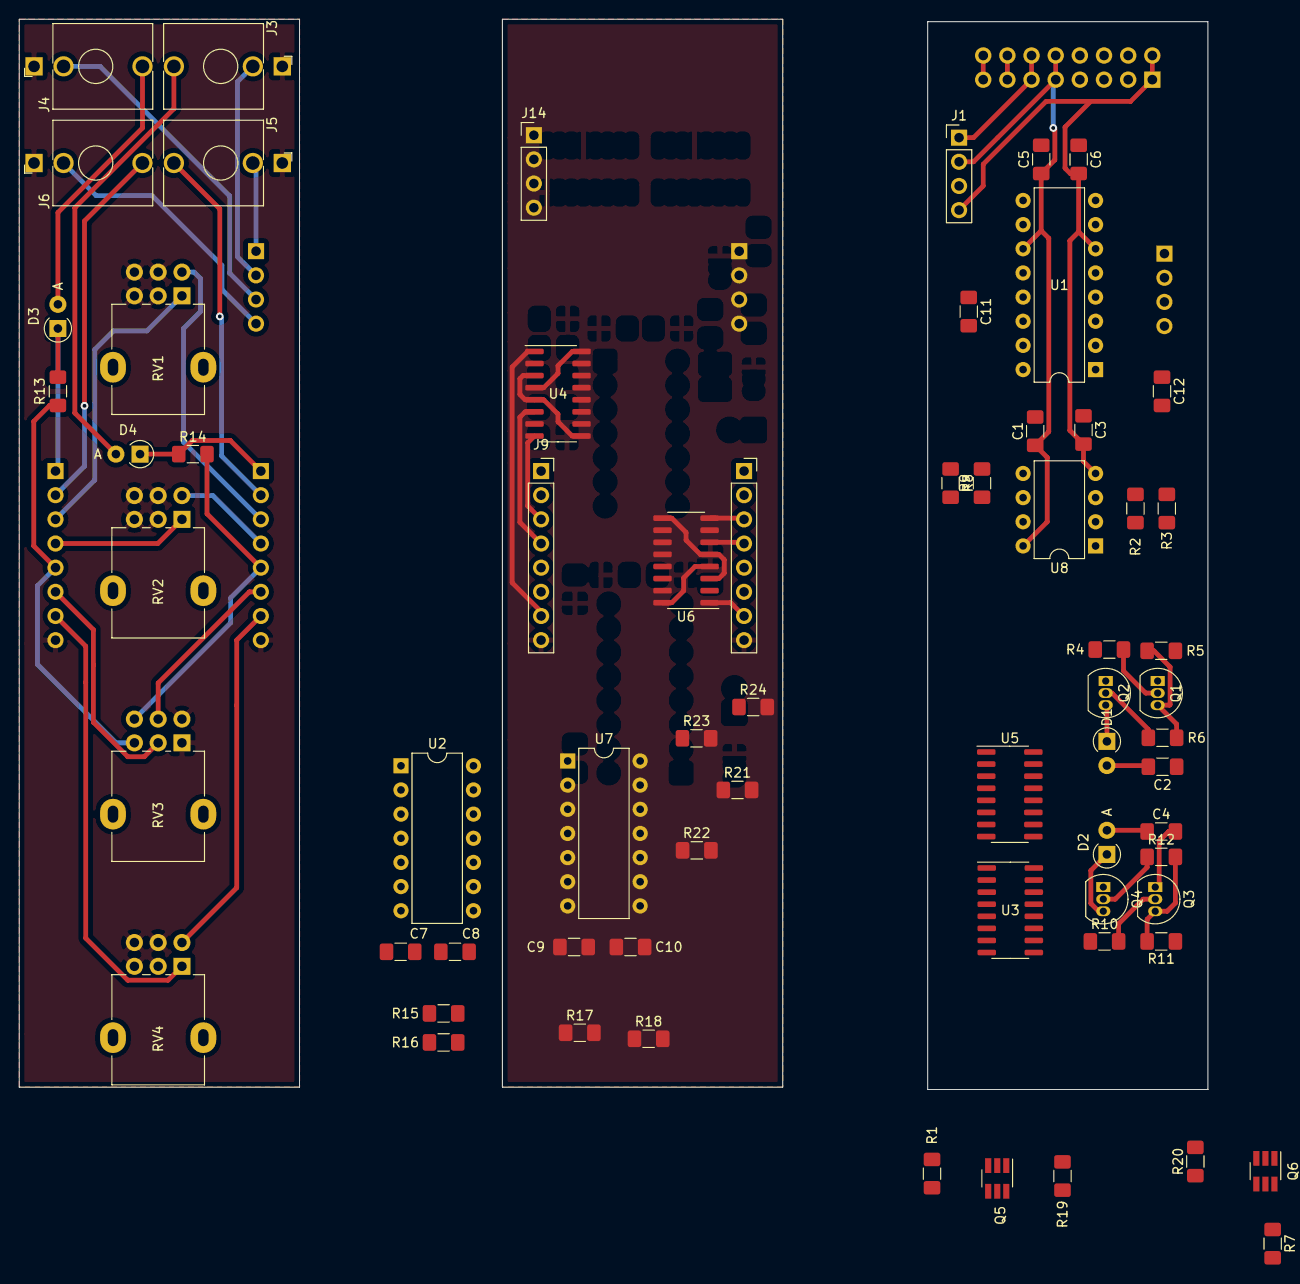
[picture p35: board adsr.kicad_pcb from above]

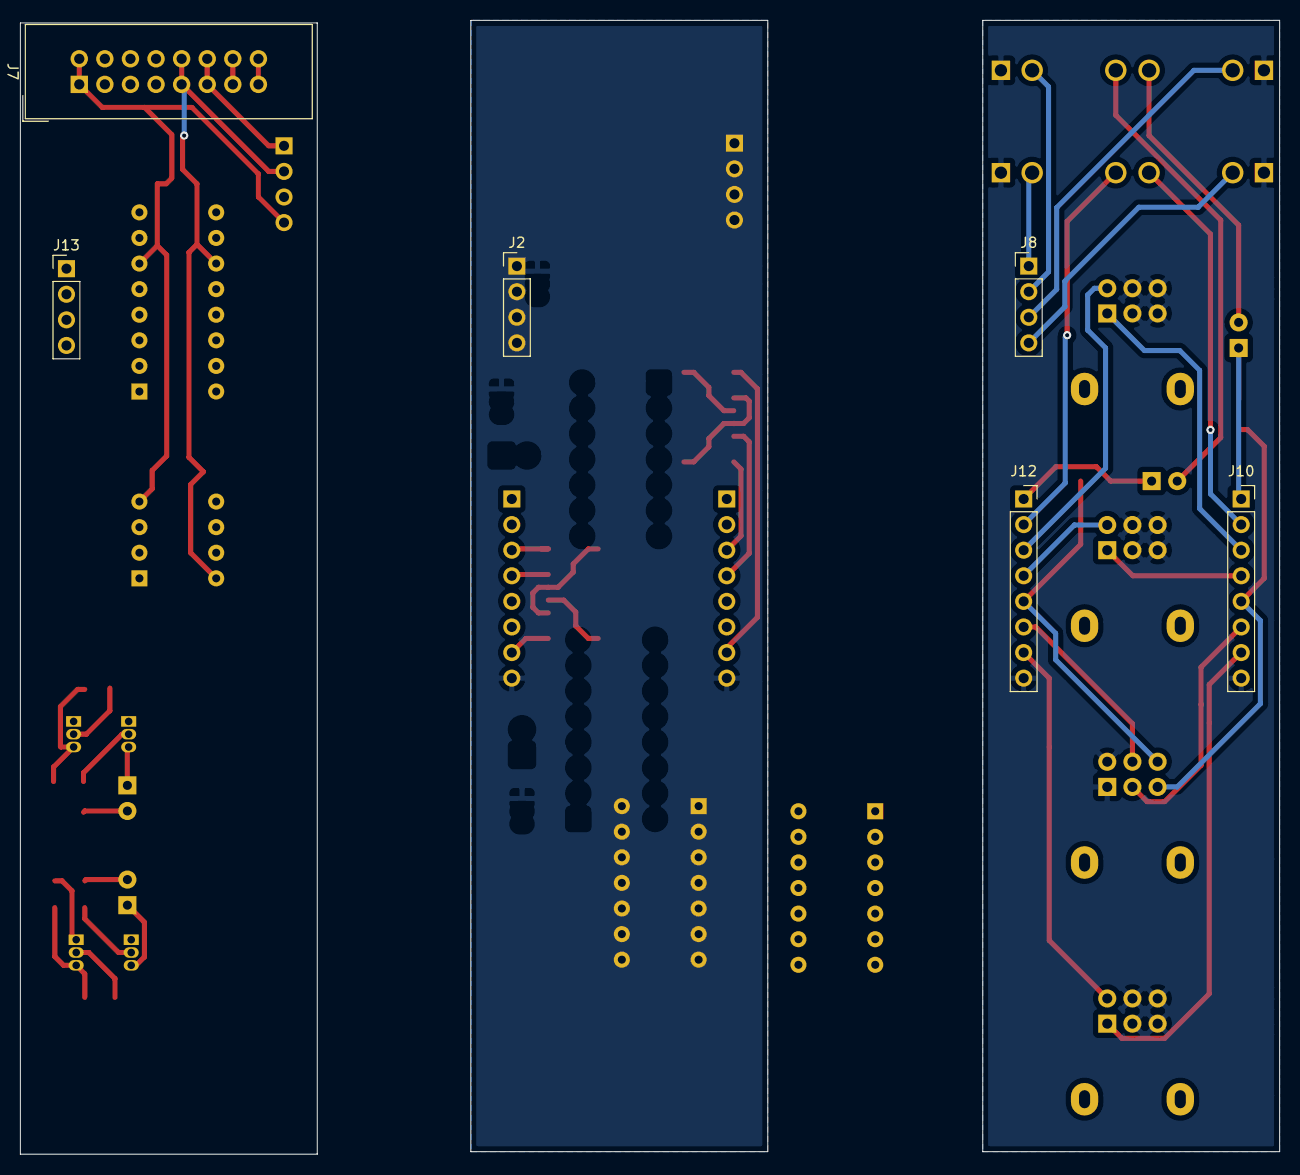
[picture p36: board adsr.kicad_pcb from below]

Board: 2 copper layers, 125.0 x 112.5 mm, 72 parts (6 on the bottom side), 64 nets.

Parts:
C1, C3, C5, C6, C7, C8, C9, C10: 0.1u; C_1206_3216Metric_Pad1.42x1.75mm_HandSolder
C2, C4: 100n; C_1206_3216Metric_Pad1.42x1.75mm_HandSolder
C11, C12: 4.7u; C_1206_3216Metric_Pad1.42x1.75mm_HandSolder
D1, D2, D3, D4: D; D_A-405_P2.54mm_Vertical_AnodeUp
J1: Conn_01x04_Female; PinHeader_1x04_P2.54mm_Vertical
J2, J8, J13, J14: Conn_01x04_Male; PinHeader_1x04_P2.54mm_Vertical
J3: B_IN; Jack_3.5mm_QingPu_WQP-PJ398SM_Vertical_CircularHoles
J4: A_IN; Jack_3.5mm_QingPu_WQP-PJ398SM_Vertical_CircularHoles
J5: B_OUT; Jack_3.5mm_QingPu_WQP-PJ398SM_Vertical_CircularHoles
J6: A_OUT; Jack_3.5mm_QingPu_WQP-PJ398SM_Vertical_CircularHoles
J7: EURORACK_CONN_16; EURORACK_16_IDC
J9, J11: Conn_01x08_Female; PinSocket_1x08_P2.54mm_Vertical
J10, J12: Conn_01x08_Male; PinSocket_1x08_P2.54mm_Vertical
Q1, Q2, Q3, Q4: 2N3904; TO-92_Inline
Q5, Q6: DMMT5401; SOT-23-6_Handsoldering
R1, R7, R19, R20: 6.8k; R_1206_3216Metric_Pad1.42x1.75mm_HandSolder
R2, R6, R8, R12, R21, R23: 1K; R_1206_3216Metric_Pad1.42x1.75mm_HandSolder
R3, R4, R5, R9, R10, R11, R22, R24: 100K; R_1206_3216Metric_Pad1.42x1.75mm_HandSolder
R13, R14: 1M; R_1206_3216Metric_Pad1.42x1.75mm_HandSolder
R15, R16, R17, R18: 10K; R_1206_3216Metric_Pad1.42x1.75mm_HandSolder
RV1: R_ATTACK; Potentiometer_Alpha_RD902F-40-00D_Dual_Vertical
RV2: R_DECAY; Potentiometer_Alpha_RD902F-40-00D_Dual_Vertical
RV3: R_SUSTAIN; Potentiometer_Alpha_RD902F-40-00D_Dual_Vertical
RV4: R_RELEASE; Potentiometer_Alpha_RD902F-40-00D_Dual_Vertical
U1: LM13700; DIP-16_W7.62mm
U2, U7: TL074; DIP-14_W7.62mm
U3, U4, U5, U6: DG403; SOIC-16_3.9x9.9mm_P1.27mm
U8: TL072; DIP-8_W7.62mm

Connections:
+5V: J1.1, J7.11 (5V), J14.4, U3.12 (VL), U4.12 (VL), U5.12 (VL), U6.12 (VL)
+12V: C1.1, C5.1, C7.1, C9.1, J1.2, J7.9 (12V_P), J14.3, Q5.5 (E2), Q5.6 (E1), Q6.5 (E2), Q6.6 (E1), R5.1, R11.1, R22.2, R24.2, U1.11 (V+), U2.4 (V+), U3.11 (V+), U4.11 (V+), U5.11 (V+), U6.11 (V+), U7.4 (V+), U8.8 (V+)
-12V: C3.2, C6.2, C8.2, C10.2, J1.4, J7.1 (12V_N), J14.1, U1.6 (V-), U2.11 (V-), U3.14 (V-), U4.14 (V-), U5.14 (V-), U6.14 (V-), U7.11 (V-), U8.4 (V-)
/envelope/ATTACK: J9.3, J10.3, RV1.1, U4.8 (D2)
/envelope/DECAY: J9.4, J10.4, RV2.1, U4.6 (D4)
/envelope/IN_RAW: D3.1 (K), J9.1, J10.1, R13.1, U2.12 (+)
/envelope/REF: R2.1, U2.1, U2.2 (-), U3.8 (D2)
/envelope/REF_RAW: J9.5, J10.5, R13.2, RV3.3, U2.3 (+)
/envelope/RELEASE: J9.7, J10.7, RV4.1, U4.1 (D1)
/envelope/STATE: C2.1, D1.2 (A), U1.9, U3.10 (IN2), U4.10 (IN2)
/envelope/SUS: U2.6 (-), U2.7, U3.6 (D4)
/envelope/SUS_RAW: J9.6, J10.6, RV3.2, U2.5 (+)
/envelope/VC: C11.1, U1.12, U1.13 (-), U2.10 (+), U8.3 (+)
/envelope/VINS: R4.1, U2.14, U3.15 (IN1), U4.15 (IN1)
/sheet5F5D80AF/ATTACK: J11.3, J12.3, RV1.4, U6.8 (D2)
/sheet5F5D80AF/DECAY: J11.4, J12.4, RV2.4, U6.6 (D4)
/sheet5F5D80AF/IN_RAW: D4.1 (K), J11.1, J12.1, R14.1, U7.5 (+)
/sheet5F5D80AF/REF: R8.1, U5.8 (D2), U7.8, U7.9 (-)
/sheet5F5D80AF/REF_RAW: J11.5, J12.5, R14.2, RV3.6, U7.10 (+)
/sheet5F5D80AF/RELEASE: J11.7, J12.7, RV4.4, U6.1 (D1)
/sheet5F5D80AF/STATE: C4.1, D2.2 (A), U1.8, U5.10 (IN2), U6.10 (IN2)
/sheet5F5D80AF/SUS: U5.6 (D4), U7.13 (-), U7.14
/sheet5F5D80AF/SUS_RAW: J11.6, J12.6, RV3.5, U7.12 (+)
/sheet5F5D80AF/VC: C12.1, U1.4 (-), U1.5, U7.3 (+), U8.5 (+)
/sheet5F5D80AF/VINS: R10.1, U5.15 (IN1), U6.15 (IN1), U7.7
A_IN: D3.2 (A), J4.T
A_IN_DEFAULT: J2.3, J4.TN, J8.3, J13.3
A_OUT: J6.T, J9.2, J10.2, R16.2, U2.8
A_OUT_DEFAULT: J2.4, J6.TN, J8.4, J13.4
B_IN: D4.2 (A), J3.T
B_IN_DEFAULT: J2.2, J3.TN, J8.2, J13.2
B_OUT: J5.T, J11.2, J12.2, R18.2, U7.1
B_OUT_DEFAULT: J2.1, J5.TN, J8.1, J13.1
GND: C1.2, C2.2, C3.1, C4.2, C5.2, C6.1, C7.2, C8.1, C9.2, C10.1, C11.2, C12.2, J1.3, J3.S, J4.S, J5.S, J6.S, J7.3 (GND), J9.8, J10.8, J11.8, J12.8, J14.2, Q1.1 (E), Q2.1 (E), Q3.1 (E), Q4.1 (E), R3.2, R9.2, R15.1, R17.1, R21.2, R23.2, RV1.2, RV1.3, RV1.5, RV1.6, RV2.2, RV2.3, RV2.5, RV2.6, RV3.1, RV3.4, RV4.2, RV4.3, RV4.5, RV4.6, U3.1 (D1), U3.13 (GND), U4.13 (GND), U5.1 (D1), U5.13 (GND), U6.13 (GND)
unnamed: D1.1 (K), Q2.3 (C)
unnamed: D2.1 (K), Q4.3 (C)
unnamed: Q1.2 (B), R4.2
unnamed: Q1.3 (C), R5.2, R6.2
unnamed: Q2.2 (B), R6.1
unnamed: Q3.2 (B), R10.2
unnamed: Q3.3 (C), R11.2, R12.2
unnamed: Q4.2 (B), R12.1
unnamed: Q5.1 (C1), Q5.2 (B1), Q5.3 (B2), R19.1
unnamed: Q5.4 (C2), R1.1
unnamed: Q6.1 (C1), Q6.2 (B1), Q6.3 (B2), R20.1
unnamed: Q6.4 (C2), R7.1
unnamed: R1.2, U1.16
unnamed: R2.2, R3.1, U8.2 (-)
unnamed: R7.2, U1.1
unnamed: R8.2, R9.1, U8.6 (-)
unnamed: R15.2, R16.1, U2.9 (-)
unnamed: R17.2, R18.1, U7.2 (-)
unnamed: R19.2, U4.4 (S3), U4.16 (S1)
unnamed: R20.2, U6.4 (S3), U6.16 (S1)
unnamed: R21.1, R22.1, U2.13 (-)
unnamed: R23.1, R24.1, U7.6 (-)
unnamed: U1.3 (+), U5.4 (S3), U5.16 (S1)
unnamed: U1.7, U8.7
unnamed: U1.10, U8.1
unnamed: U1.14 (+), U3.4 (S3), U3.16 (S1)
unnamed: U3.3 (D3), U3.5 (S4), U3.9 (S2)
unnamed: U4.3 (D3), U4.5 (S4), U4.9 (S2)
unnamed: U5.3 (D3), U5.5 (S4), U5.9 (S2)
unnamed: U6.3 (D3), U6.5 (S4), U6.9 (S2)

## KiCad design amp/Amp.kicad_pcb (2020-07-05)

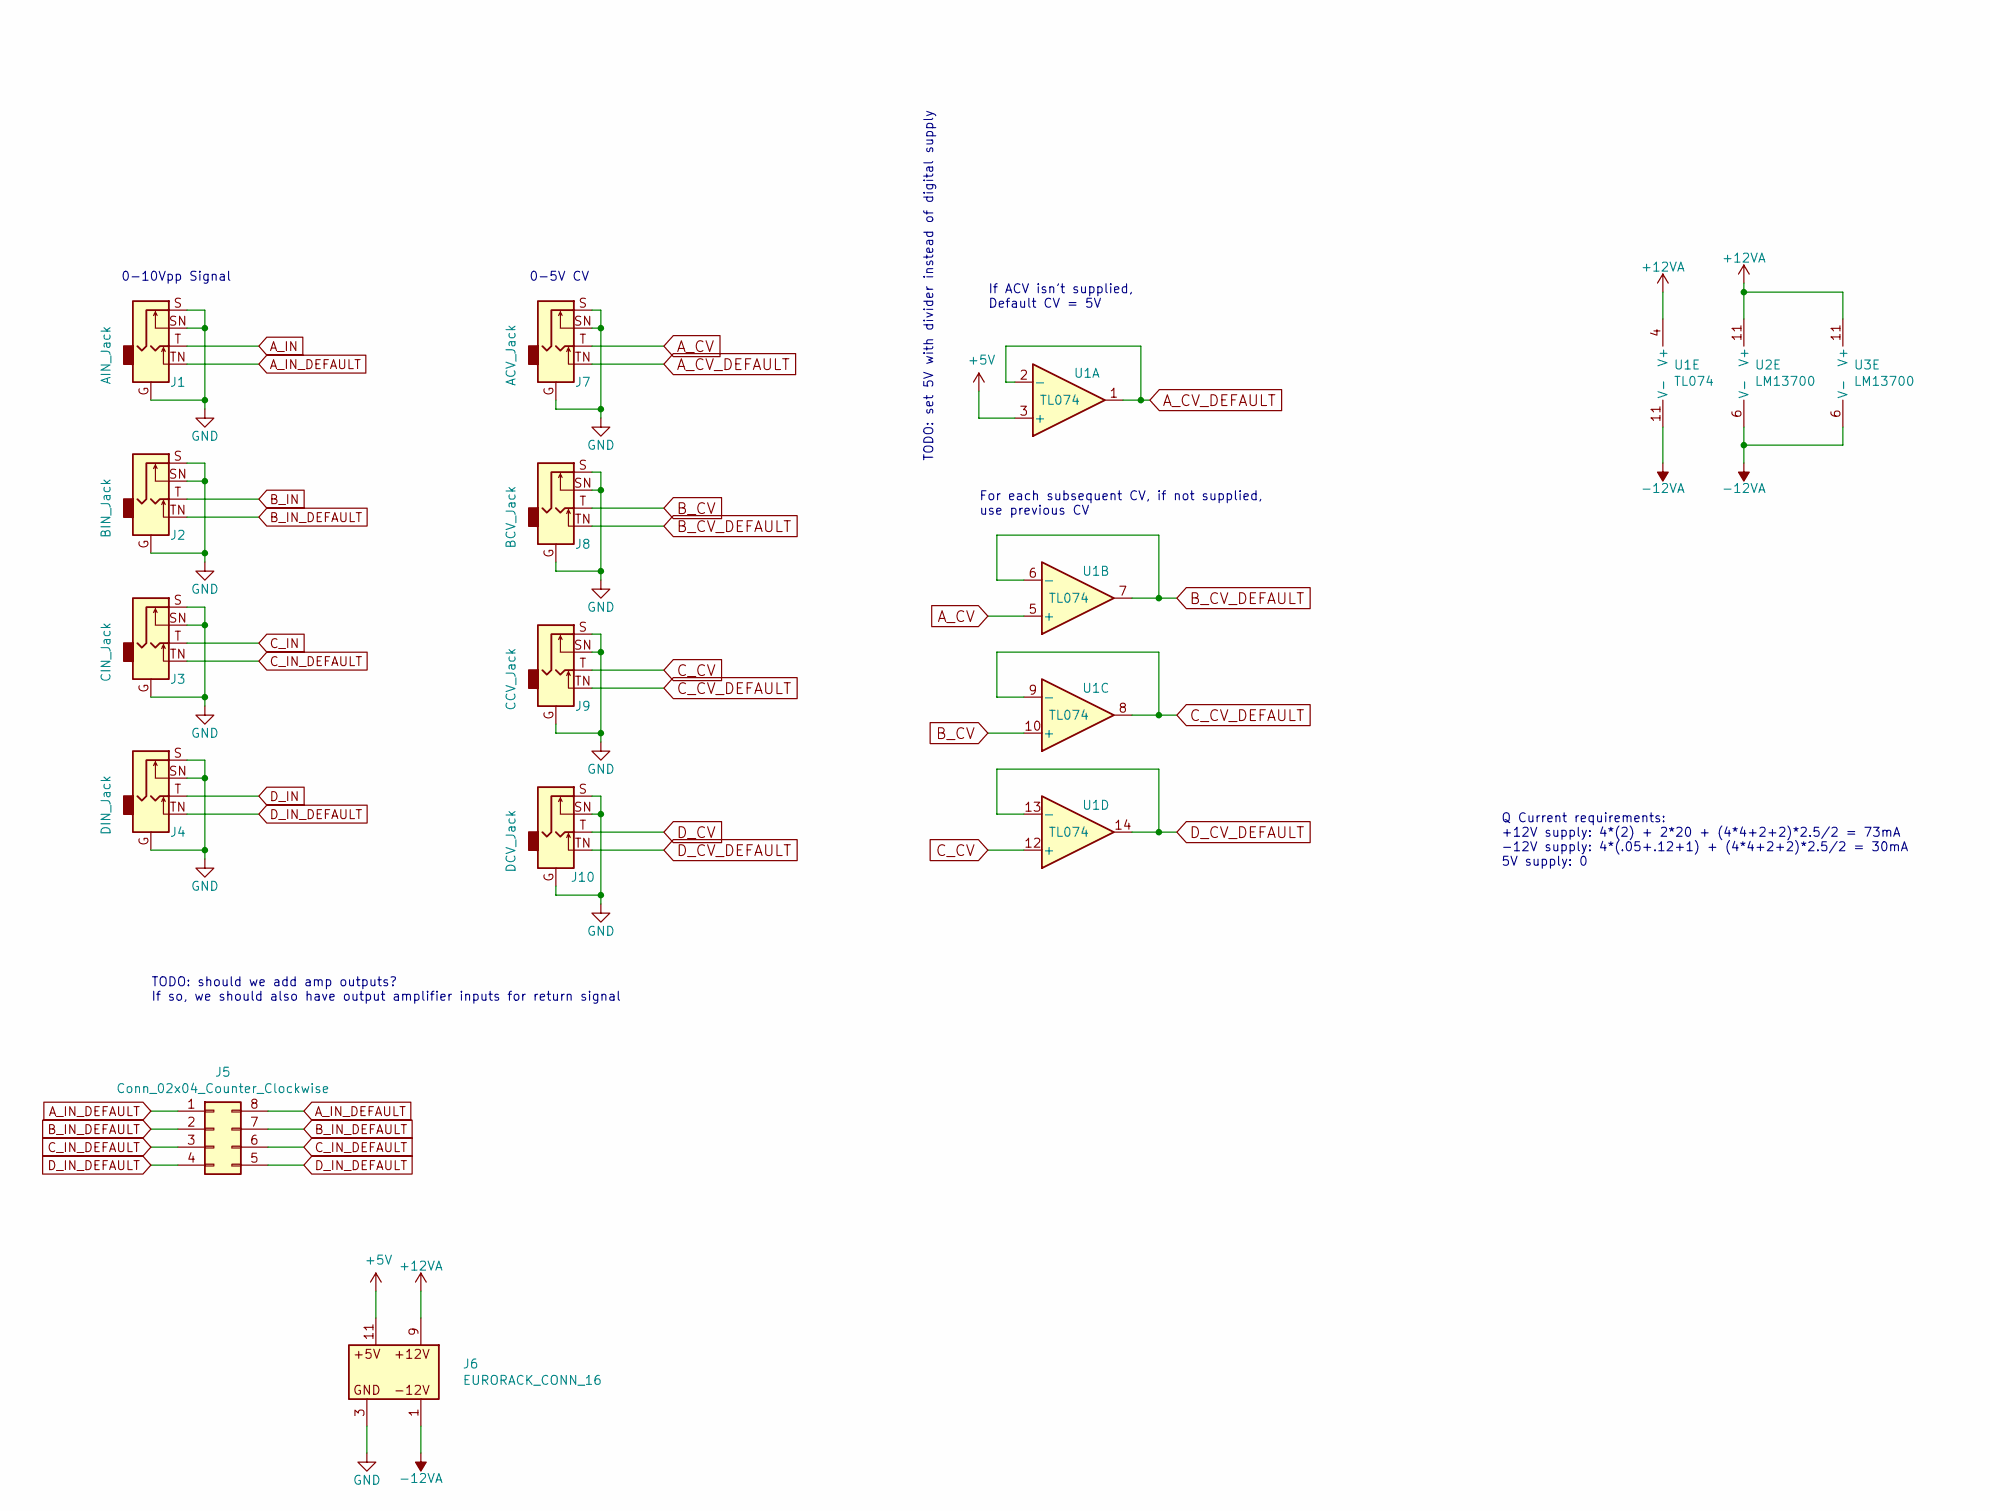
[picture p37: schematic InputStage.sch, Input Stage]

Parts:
J1: AIN_Jack; 3.5MM_Jack_Breakout_Vertical
J2: BIN_Jack; 3.5MM_Jack_Breakout_Vertical
J3: CIN_Jack; 3.5MM_Jack_Breakout_Vertical
J4: DIN_Jack; 3.5MM_Jack_Breakout_Vertical
J5: Conn_02x04_Counter_Clockwise; PinHeader_2x04_P2.54mm_Vertical
J6: EURORACK_CONN_16; EURORACK_16_IDC
J7: ACV_Jack; 3.5MM_Jack_Breakout_Vertical
J8: BCV_Jack; 3.5MM_Jack_Breakout_Vertical
J9: CCV_Jack; 3.5MM_Jack_Breakout_Vertical
J10: DCV_Jack; 3.5MM_Jack_Breakout_Vertical
U1: TL074; DIP-14_W7.62mm
U2, U3: LM13700; DIP-16_W7.62mm

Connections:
+5V: J6.11 (5V), U1.3 (+)
+12VA: J6.9 (12V_P), U1.4 (V+), U2.11 (V+), U3.11 (V+); also elsewhere on the board
-12VA: J6.1 (12V_N), U1.11 (V-), U2.6 (V-), U3.6 (V-); also elsewhere on the board
A_CV: J7.T, U1.5 (+); also elsewhere on the board
A_CV_DEFAULT: J7.TN, U1.1, U1.2 (-)
A_IN: J1.T; also elsewhere on the board
A_IN_DEFAULT: J1.TN, J5.1, J5.8
B_CV: J8.T, U1.10 (+); also elsewhere on the board
B_CV_DEFAULT: J8.TN, U1.6 (-), U1.7
B_IN: J2.T; also elsewhere on the board
B_IN_DEFAULT: J2.TN, J5.2, J5.7
C_CV: J9.T, U1.12 (+); also elsewhere on the board
C_CV_DEFAULT: J9.TN, U1.8, U1.9 (-)
C_IN: J3.T; also elsewhere on the board
C_IN_DEFAULT: J3.TN, J5.3, J5.6
D_CV: J10.T; also elsewhere on the board
D_CV_DEFAULT: J10.TN, U1.13 (-), U1.14
D_IN: J4.T; also elsewhere on the board
D_IN_DEFAULT: J4.TN, J5.4, J5.5
GND: J1.G, J1.S, J1.SN, J2.G, J2.S, J2.SN, J3.G, J3.S, J3.SN, J4.G, J4.S, J4.SN, J6.3 (GND), J7.G, J7.S, J7.SN, J8.G, J8.S, J8.SN, J9.G, J9.S, J9.SN, J10.G, J10.S, J10.SN, U2.4 (-), U3.4 (-); also elsewhere on the board
unnamed 60: U3.1; also elsewhere on the board
unnamed 63: U2.1; also elsewhere on the board
unnamed 91: U3.3 (+); also elsewhere on the board
unnamed 94: U3.5; also elsewhere on the board
unnamed 99: U2.3 (+); also elsewhere on the board
unnamed 102: U2.5; also elsewhere on the board

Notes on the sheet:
0-10Vpp Signal
If ACV isn’t supplied, Default CV = 5V
For each subsequent CV, if not supplied, use previous CV
0-5V CV
Q Current requirements: +12V supply: 4*(2) + 2*20 + (4*4+2+2)*2.5/2 = 73mA -12V supply: 4*(.05+.12+1) + (4*4+2+2)*2.5/2 = 30mA 5V supply: 0
TODO: should we add amp outputs? If so, we should also have output amplifier inputs for return signal
TODO: set 5V with divider instead of digital supply

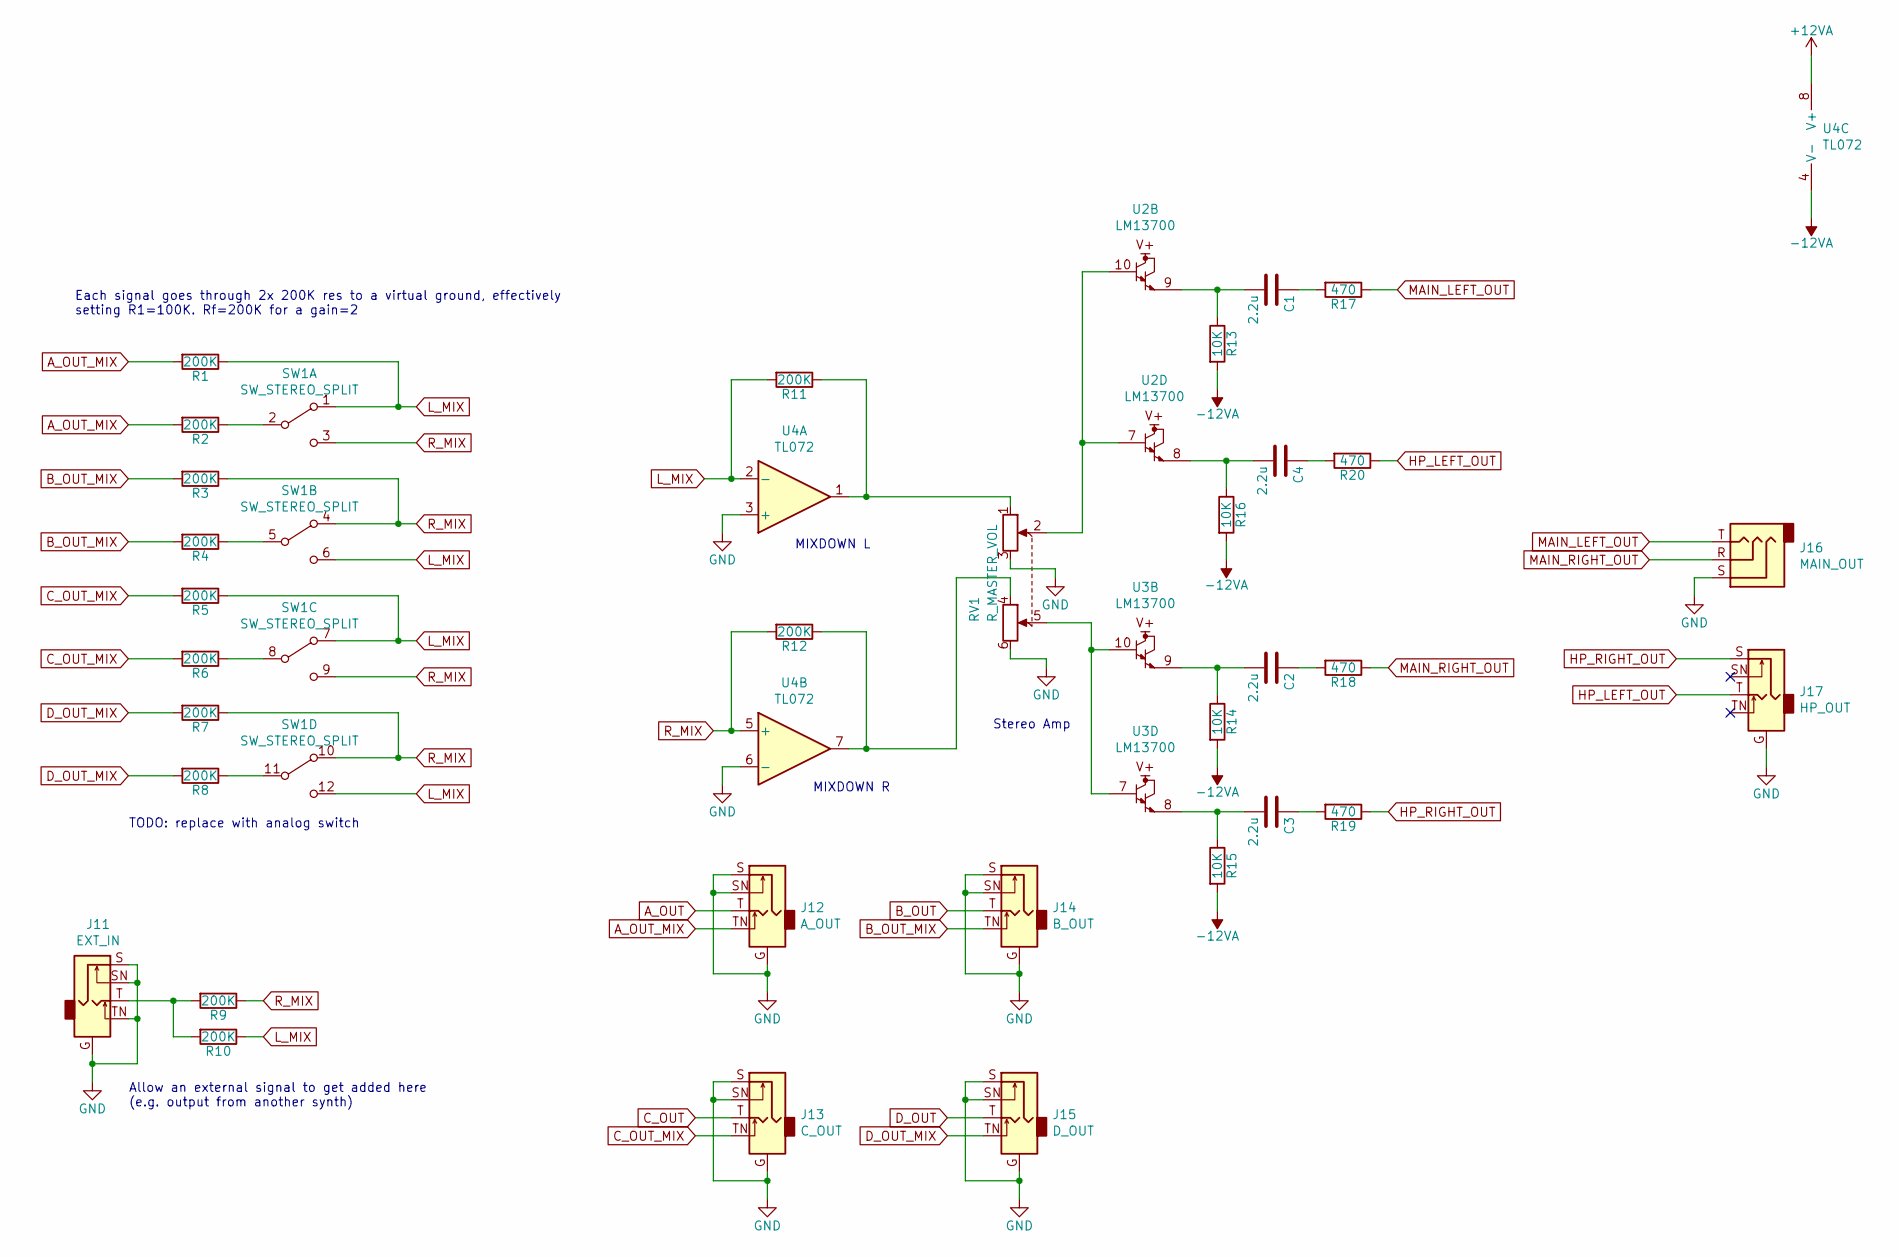
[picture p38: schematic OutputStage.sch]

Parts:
C1, C2, C3, C4: 2.2u; C_Radial_D6.3mm_H5.0mm_P2.50mm
J11: EXT_IN; 3.5MM_Jack_Breakout_Vertical
J12: A_OUT; 3.5MM_Jack_Breakout_Vertical
J13: C_OUT; 3.5MM_Jack_Breakout_Vertical
J14: B_OUT; 3.5MM_Jack_Breakout_Vertical
J15: D_OUT; 3.5MM_Jack_Breakout_Vertical
J16: MAIN_OUT; PinHeader_1x03_P2.54mm_Vertical
J17: HP_OUT; 3.5MM_Jack_Breakout_Vertical
R1, R2, R3, R4, R5, R6, R7, R8, R9, R10, R11, R12: 200K; R_Axial_DIN0204_L3.6mm_D1.6mm_P1.90mm_Vertical
R13, R14, R15, R16: 10K; R_Axial_DIN0204_L3.6mm_D1.6mm_P1.90mm_Vertical
R17, R18, R19, R20: 470; R_Axial_DIN0204_L3.6mm_D1.6mm_P1.90mm_Vertical
RV1: R_MASTER_VOL; PinHeader_2x03_P2.54mm_Vertical
SW1: SW_STEREO_SPLIT; PinHeader_2x06_P2.54mm_Vertical
U2, U3: LM13700; DIP-16_W7.62mm
U4: TL072; DIP-8_W7.62mm

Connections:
+12VA: U4.8 (V+); also elsewhere on the board
-12VA: R13.2, R14.2, R15.2, R16.2, U4.4 (V-); also elsewhere on the board
A_OUT: J12.T; also elsewhere on the board
A_OUT_MIX: J12.TN, R1.2, R2.2
B_OUT: J14.T; also elsewhere on the board
B_OUT_MIX: J14.TN, R3.2, R4.2
C_OUT: J13.T; also elsewhere on the board
C_OUT_MIX: J13.TN, R5.2, R6.2
D_OUT: J15.T; also elsewhere on the board
D_OUT_MIX: J15.TN, R7.2, R8.2
GND: J11.G, J11.S, J11.SN, J11.TN, J12.G, J12.S, J12.SN, J13.G, J13.S, J13.SN, J14.G, J14.S, J14.SN, J15.G, J15.S, J15.SN, J16.S, J17.G, RV1.3, RV1.6, U2.4 (-), U3.4 (-), U4.3 (+), U4.6 (-); also elsewhere on the board
HP_LEFT_OUT: J17.T, R20.1
HP_RIGHT_OUT: J17.S, R19.1
L_MIX: R1.1, R5.1, R10.1, R11.2, SW1.1 (A), SW1.6 (C), SW1.7 (A), SW1.12 (C), U4.2 (-)
MAIN_LEFT_OUT: J16.T, R17.1
MAIN_RIGHT_OUT: J16.R, R18.1
unnamed: C1.1, R17.2
unnamed: C1.2, R13.1, U2.9
unnamed: C2.1, R18.2
unnamed: C2.2, R14.1, U3.9
unnamed: C3.1, R19.2
unnamed: C3.2, R15.1, U3.8
unnamed: C4.1, R20.2
unnamed: C4.2, R16.1, U2.8
unnamed: J11.T, R9.2, R10.2
unnamed 60: U3.1; also elsewhere on the board
unnamed 63: U2.1; also elsewhere on the board
unnamed: R2.1, SW1.2 (B)
unnamed: R4.1, SW1.5 (B)
unnamed: R6.1, SW1.8 (B)
unnamed: R8.1, SW1.11 (B)
unnamed: R11.1, RV1.1, U4.1
unnamed: R12.1, RV1.4, U4.7
unnamed 91: U3.3 (+); also elsewhere on the board
unnamed 94: U3.5; also elsewhere on the board
unnamed 99: U2.3 (+); also elsewhere on the board
unnamed 102: U2.5; also elsewhere on the board
unnamed: RV1.2, U2.7, U2.10
unnamed: RV1.5, U3.7, U3.10
R_MIX: R3.1, R7.1, R9.1, R12.2, SW1.3 (C), SW1.4 (A), SW1.9 (C), SW1.10 (A), U4.5 (+)

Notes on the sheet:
Stereo Amp
Each signal goes through 2x 200K res to a virtual ground, effectively setting R1=100K. Rf=200K for a gain=2
MIXDOWN L
MIXDOWN R
Allow an external signal to get added here (e.g. output from another synth)
TODO: replace with analog switch

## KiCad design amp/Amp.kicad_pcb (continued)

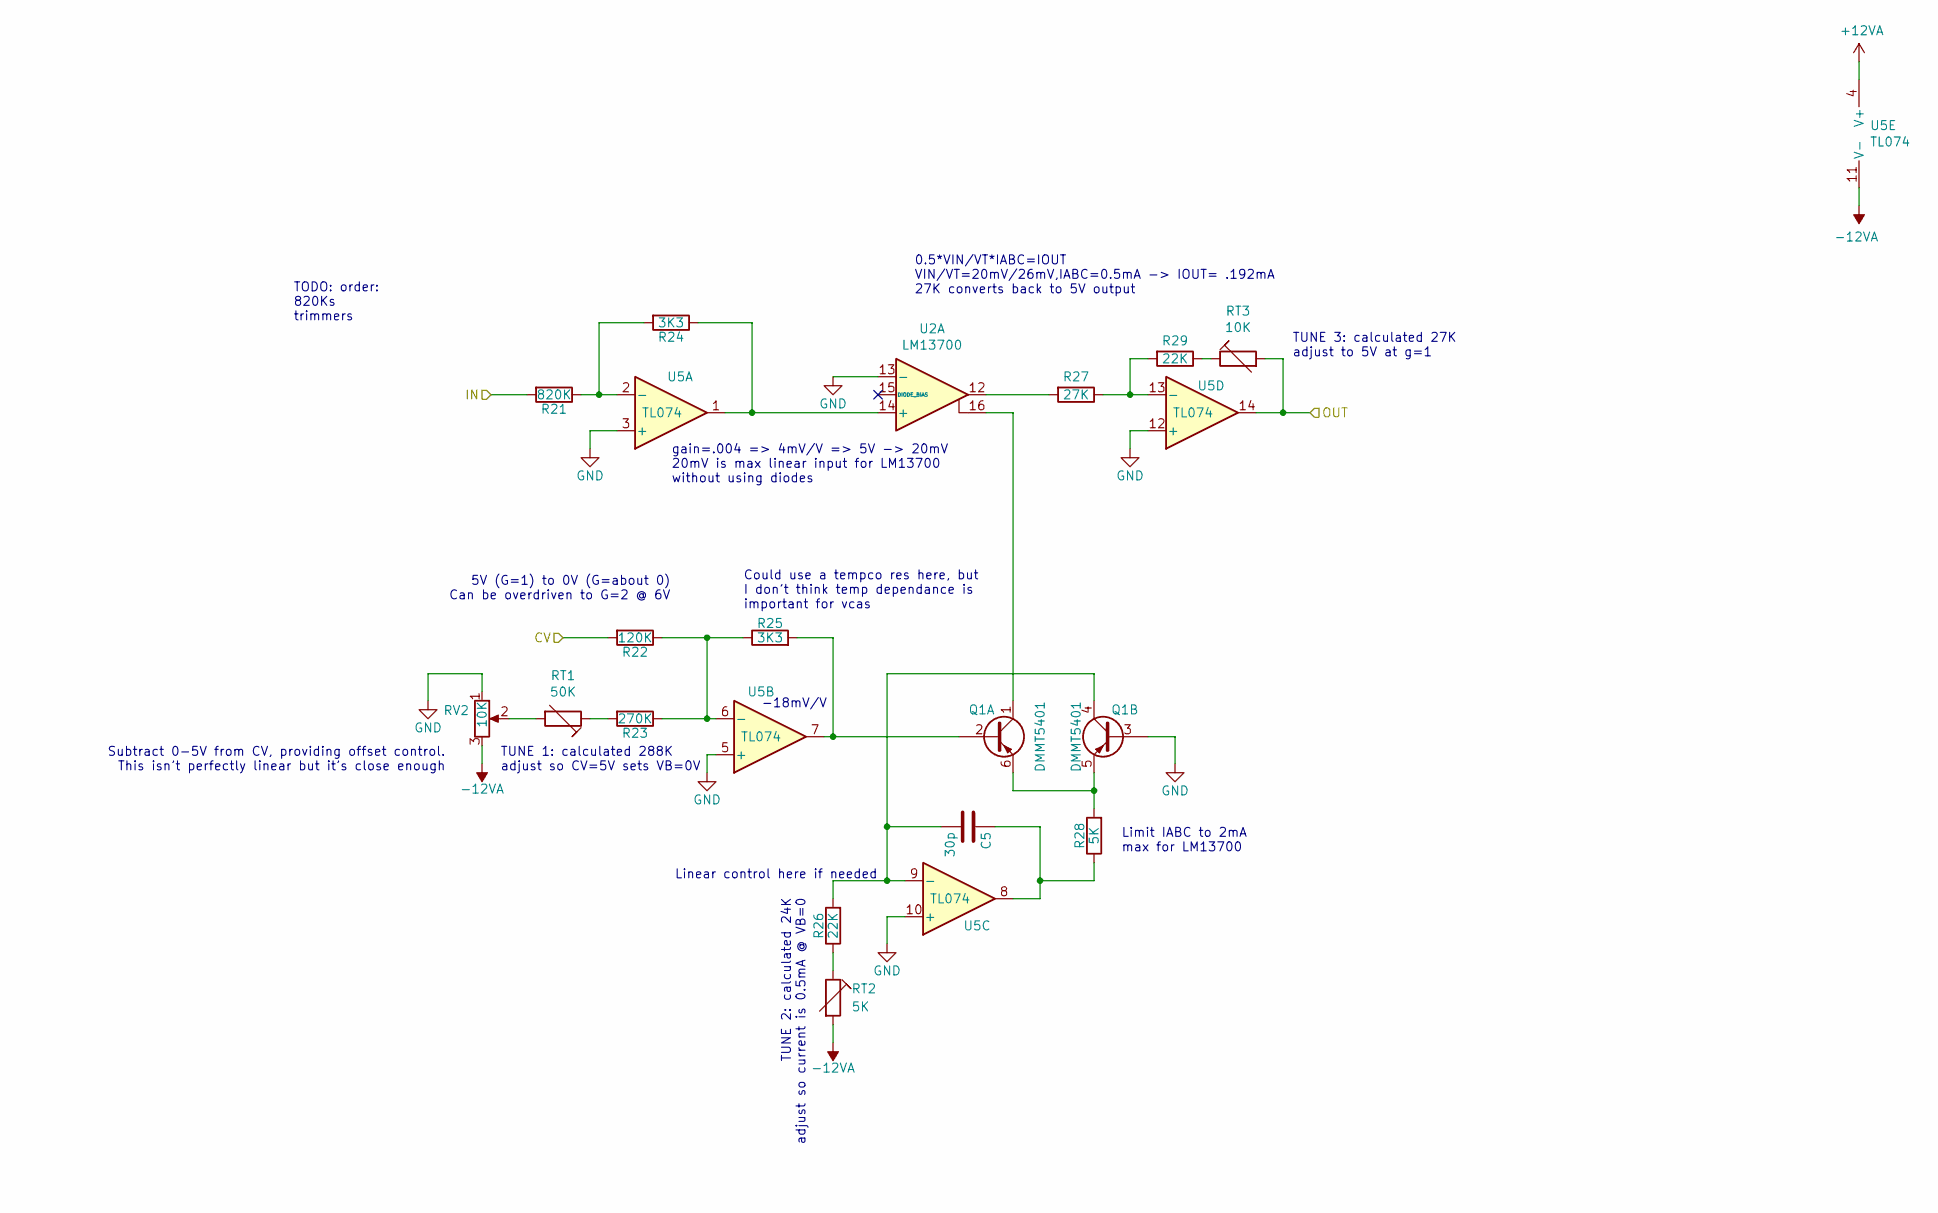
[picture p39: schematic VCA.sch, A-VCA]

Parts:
C5: 30p; C_Disc_D3.0mm_W2.0mm_P2.50mm
Q1: DMMT5401; SOT-23-6
R21: 820K; R_Axial_DIN0204_L3.6mm_D1.6mm_P1.90mm_Vertical
R22: 120K; R_Axial_DIN0204_L3.6mm_D1.6mm_P1.90mm_Vertical
R23: 270K; R_Axial_DIN0204_L3.6mm_D1.6mm_P1.90mm_Vertical
R24, R25: 3K3; R_Axial_DIN0204_L3.6mm_D1.6mm_P1.90mm_Vertical
R26, R29: 22K; R_Axial_DIN0204_L3.6mm_D1.6mm_P1.90mm_Vertical
R27: 27K; R_Axial_DIN0204_L3.6mm_D1.6mm_P1.90mm_Vertical
R28: 5K; R_Axial_DIN0204_L3.6mm_D1.6mm_P1.90mm_Vertical
RT1: 50K; R_Box_L14.0mm_W5.0mm_P9.00mm
RT2: 5K; R_Box_L14.0mm_W5.0mm_P9.00mm
RT3: 10K; R_Box_L14.0mm_W5.0mm_P9.00mm
RV2: 10K; slide_potentiometer_35mm
U2: LM13700; DIP-16_W7.62mm
U5: TL074; DIP-14_W7.62mm

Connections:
+12VA: U5.4 (V+); also elsewhere on the board
-12VA: RT2.2, RV2.3, U5.11 (V-); also elsewhere on the board
A_CV: R22.2; also elsewhere on the board
A_IN: R21.2; also elsewhere on the board
A_OUT: RT3.2, U5.14; also elsewhere on the board
GND: Q1.3 (B2), RV2.1, U2.4 (-), U2.13 (-), U5.3 (+), U5.5 (+), U5.10 (+), U5.12 (+); also elsewhere on the board
unnamed: C5.1, R28.1, U5.8
unnamed: C5.2, Q1.4 (C2), R26.2, U5.9 (-)
unnamed: Q1.1 (C1), U2.16
unnamed: Q1.2 (B1), R25.2, U5.7
unnamed: Q1.5 (E2), Q1.6 (E1), R28.2
unnamed 63: U2.1; also elsewhere on the board
unnamed: R21.1, R24.2, U5.2 (-)
unnamed: R22.1, R23.1, R25.1, U5.6 (-)
unnamed: R23.2, RT1.1
unnamed: R24.1, U2.14 (+), U5.1
unnamed: R26.1, RT2.1
unnamed: R27.1, R29.2, U5.13 (-)
unnamed: R27.2, U2.12
unnamed: R29.1, RT3.1
unnamed 99: U2.3 (+); also elsewhere on the board
unnamed 102: U2.5; also elsewhere on the board
unnamed: RT1.2, RV2.2

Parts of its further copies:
C6, C7, C8: 30p; C_Disc_D3.0mm_W2.0mm_P2.50mm
Q2, Q3, Q4: DMMT5401; SOT-23-6
R30, R39, R48: 820K; R_Axial_DIN0204_L3.6mm_D1.6mm_P1.90mm_Vertical
R31, R40, R49: 120K; R_Axial_DIN0204_L3.6mm_D1.6mm_P1.90mm_Vertical
R32, R41, R50: 270K; R_Axial_DIN0204_L3.6mm_D1.6mm_P1.90mm_Vertical
R33, R34, R42, R43, R51, R52: 3K3; R_Axial_DIN0204_L3.6mm_D1.6mm_P1.90mm_Vertical
R35, R38, R44, R47, R53, R56: 22K; R_Axial_DIN0204_L3.6mm_D1.6mm_P1.90mm_Vertical
R36, R45, R54: 27K; R_Axial_DIN0204_L3.6mm_D1.6mm_P1.90mm_Vertical
R37, R46, R55: 5K; R_Axial_DIN0204_L3.6mm_D1.6mm_P1.90mm_Vertical
RT4, RT7, RT10: 50K; R_Box_L14.0mm_W5.0mm_P9.00mm
RT5, RT8, RT11: 5K; R_Box_L14.0mm_W5.0mm_P9.00mm
RT6, RT9, RT12: 10K; R_Box_L14.0mm_W5.0mm_P9.00mm
RV3, RV4, RV5: 10K; slide_potentiometer_35mm
U6, U7, U8: TL074; DIP-14_W7.62mm

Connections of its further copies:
+12VA: U6.4 (V+), U7.4 (V+), U8.4 (V+); also elsewhere on the board
-12VA: RT5.2, RT8.2, RT11.2, RV3.3, RV4.3, RV5.3, U6.11 (V-), U7.11 (V-), U8.11 (V-); also elsewhere on the board
B_CV: R49.2; also elsewhere on the board
B_IN: R48.2; also elsewhere on the board
B_OUT: RT12.2, U8.14; also elsewhere on the board
C_CV: R31.2; also elsewhere on the board
C_IN: R30.2; also elsewhere on the board
C_OUT: RT6.2, U6.14; also elsewhere on the board
D_CV: R40.2; also elsewhere on the board
D_IN: R39.2; also elsewhere on the board
D_OUT: RT9.2, U7.14; also elsewhere on the board
GND: Q2.3 (B2), Q3.3 (B2), Q4.3 (B2), RV3.1, RV4.1, RV5.1, U6.3 (+), U6.5 (+), U6.10 (+), U6.12 (+), U7.3 (+), U7.5 (+), U7.10 (+), U7.12 (+), U8.3 (+), U8.5 (+), U8.10 (+), U8.12 (+); also elsewhere on the board
unnamed: C6.1, R37.1, U6.8
unnamed: C6.2, Q2.4 (C2), R35.2, U6.9 (-)
unnamed: C7.1, R46.1, U7.8
unnamed: C7.2, Q3.4 (C2), R44.2, U7.9 (-)
unnamed: C8.1, R55.1, U8.8
unnamed: C8.2, Q4.4 (C2), R53.2, U8.9 (-)
unnamed 57: Q2.1 (C1); also elsewhere on the board
unnamed: Q2.2 (B1), R34.2, U6.7
unnamed: Q2.5 (E2), Q2.6 (E1), R37.2
unnamed 60: Q3.1 (C1); also elsewhere on the board
unnamed: Q3.2 (B1), R43.2, U7.7
unnamed: Q3.5 (E2), Q3.6 (E1), R46.2
unnamed 63: Q4.1 (C1); also elsewhere on the board
unnamed: Q4.2 (B1), R52.2, U8.7
unnamed: Q4.5 (E2), Q4.6 (E1), R55.2
unnamed: R30.1, R33.2, U6.2 (-)
unnamed: R31.1, R32.1, R34.1, U6.6 (-)
unnamed: R32.2, RT4.1
unnamed 83: R33.1, U6.1; also elsewhere on the board
unnamed: R35.1, RT5.1
unnamed: R36.1, R38.2, U6.13 (-)
unnamed 86: R36.2; also elsewhere on the board
unnamed: R38.1, RT6.1
unnamed: R39.1, R42.2, U7.2 (-)
unnamed: R40.1, R41.1, R43.1, U7.6 (-)
unnamed: R41.2, RT7.1
unnamed 91: R42.1, U7.1; also elsewhere on the board
unnamed: R44.1, RT8.1
unnamed: R45.1, R47.2, U7.13 (-)
unnamed 94: R45.2; also elsewhere on the board
unnamed: R47.1, RT9.1
unnamed: R48.1, R51.2, U8.2 (-)
unnamed: R49.1, R50.1, R52.1, U8.6 (-)
unnamed: R50.2, RT10.1
unnamed 99: R51.1, U8.1; also elsewhere on the board
unnamed: R53.1, RT11.1
unnamed: R54.1, R56.2, U8.13 (-)
unnamed 102: R54.2; also elsewhere on the board
unnamed: R56.1, RT12.1
unnamed: RT4.2, RV3.2
unnamed: RT7.2, RV4.2
unnamed: RT10.2, RV5.2

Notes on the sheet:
5V (G=1) to 0V (G=about 0) Can be overdriven to G=2 @ 6V
Linear control here if needed
Subtract 0-5V from CV, providing offset control. This isn’t perfectly linear but it’s close enough
-18mV/V
TUNE 2: calculated 24K adjust so current is 0.5mA @ VB=0
Limit IABC to 2mA max for LM13700
gain=.004 => 4mV/V => 5V -> 20mV 20mV is max linear input for LM13700 without using diodes
0.5*VIN/VT*IABC=IOUT VIN/VT=20mV/26mV,IABC=0.5mA -> IOUT= .192mA 27K converts back to 5V output
TODO: order: 820Ks trimmers
Could use a tempco res here, but I don’t think temp dependance is important for vcas
TUNE 1: calculated 288K adjust so CV=5V sets VB=0V
TUNE 3: calculated 27K adjust to 5V at g=1

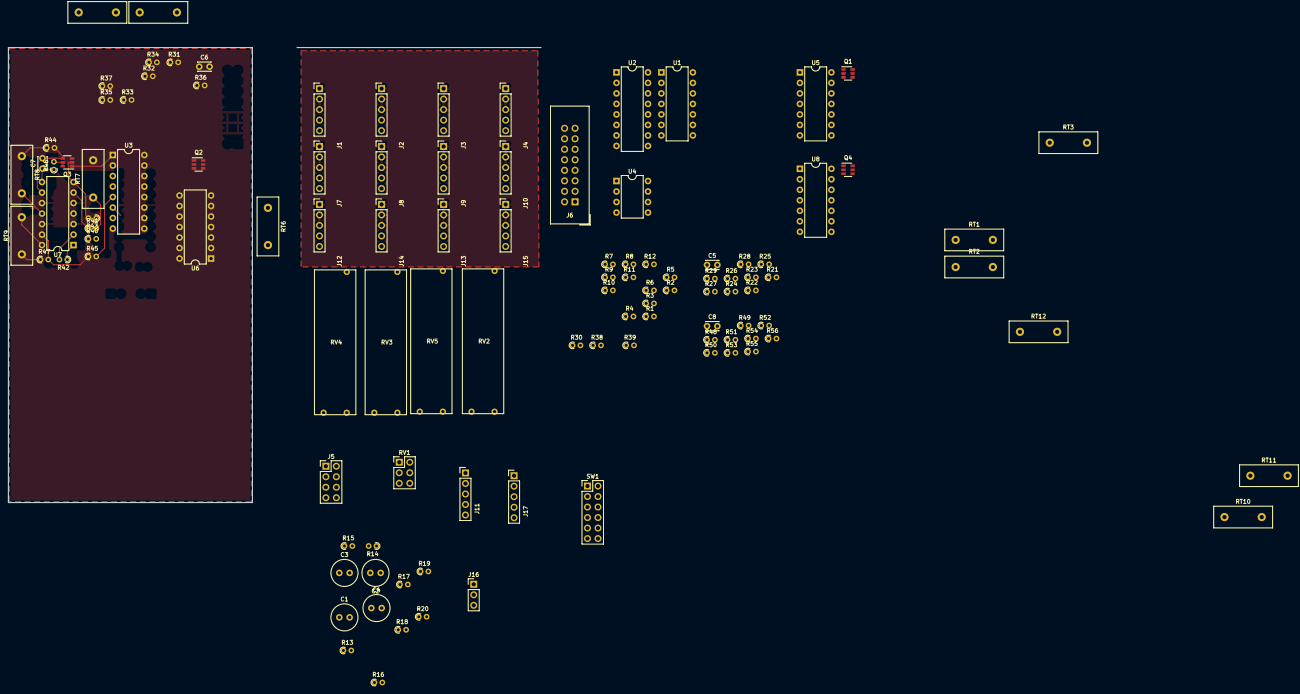
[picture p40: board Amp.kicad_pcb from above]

Board: 2 copper layers, 128.8 x 110.0 mm, 111 parts (0 on the bottom side), 105 nets.

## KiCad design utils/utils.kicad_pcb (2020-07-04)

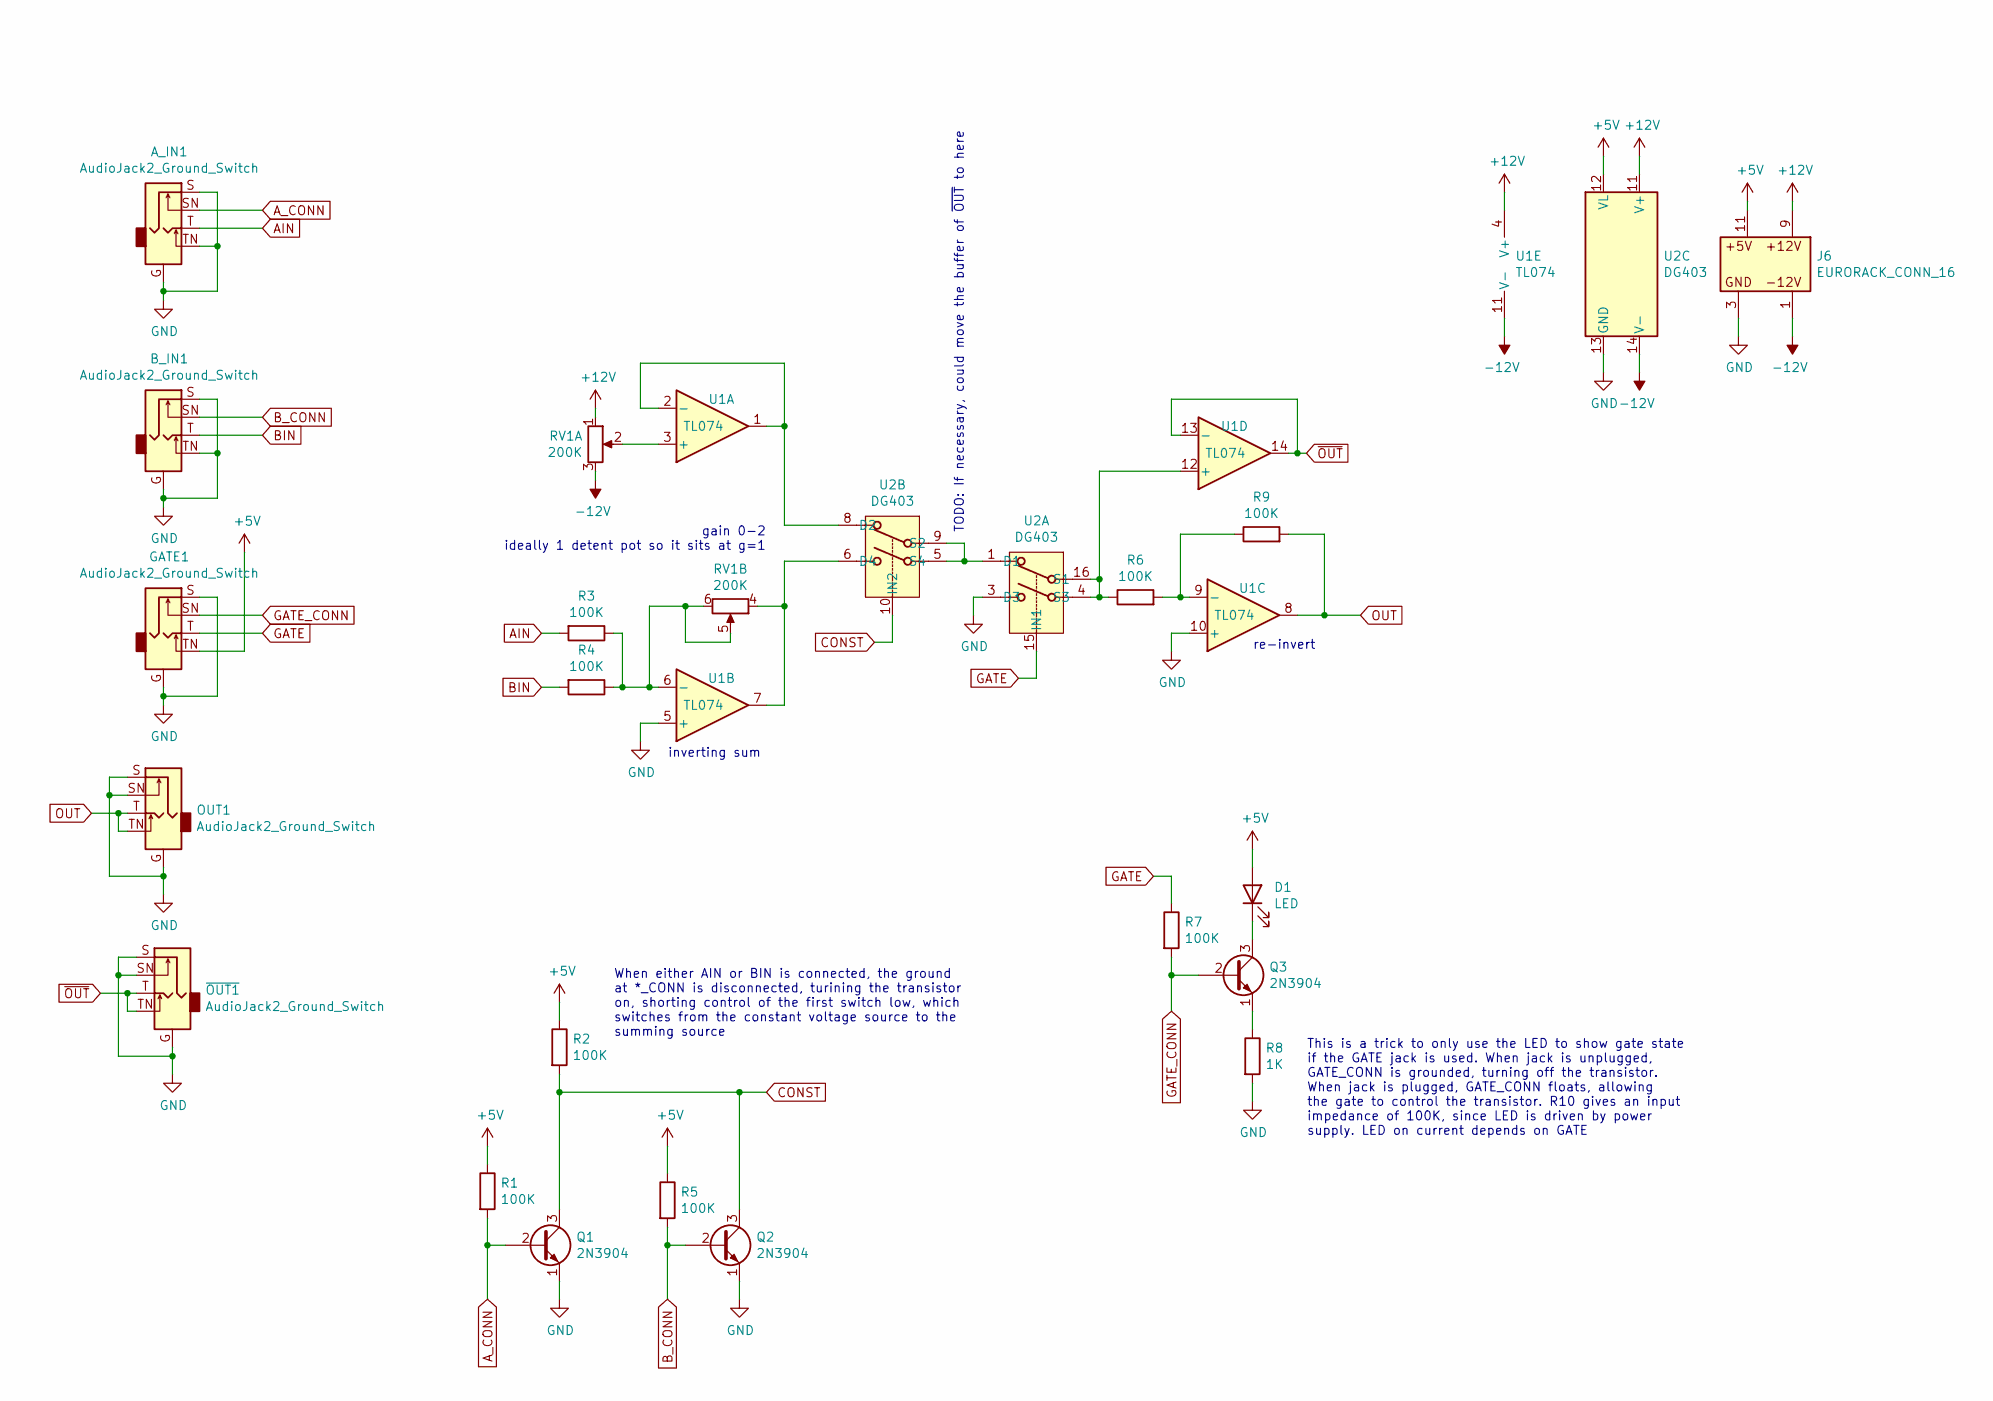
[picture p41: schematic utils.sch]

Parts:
A_IN1: AudioJack2_Ground_Switch; Jack_3.5mm_Ledino_KB3SPRS_Horizontal
B_IN1: AudioJack2_Ground_Switch; Jack_3.5mm_Ledino_KB3SPRS_Horizontal
D1: LED; LED-3MM-SQUARE-ANODE
GATE1: AudioJack2_Ground_Switch; Jack_3.5mm_Ledino_KB3SPRS_Horizontal
J6: EURORACK_CONN_16; EURORACK_16_IDC
OUT1: AudioJack2_Ground_Switch; Jack_3.5mm_Ledino_KB3SPRS_Horizontal
Q1, Q2, Q3: 2N3904; TO-92
R1, R2, R3, R4, R5, R6, R7, R9: 100K; R_Axial_DIN0309_L9.0mm_D3.2mm_P2.54mm_Vertical
R8: 1K; R_Axial_DIN0309_L9.0mm_D3.2mm_P2.54mm_Vertical
RV1: 200K; PinHeader_2x03_P2.54mm_Vertical
U1: TL074; DIP-14_W7.62mm
U2: DG403; SOIC-16_3.9x9.9mm_P1.27mm
~OUT1: AudioJack2_Ground_Switch; Jack_3.5mm_Ledino_KB3SPRS_Horizontal

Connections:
+5V: D1.2 (A), GATE1.TN, J6.11 (5V), R1.1, R2.1, R5.1, U2.12 (VL)
+12V: J6.9 (12V_P), RV1.1, U1.4 (V+), U2.11 (V+)
-12V: J6.1 (12V_N), RV1.3, U1.11 (V-), U2.14 (V-)
AIN: A_IN1.T, R3.2
A_CONN: A_IN1.SN, Q1.2 (B), R1.2
BIN: B_IN1.T, R4.2
B_CONN: B_IN1.SN, Q2.2 (B), R5.2
CONST: Q1.3 (C), Q2.3 (C), R2.2, U2.10 (IN2)
GATE: GATE1.T, R7.1, U2.15 (IN1)
GATE_CONN: GATE1.SN, Q3.2 (B), R7.2
GND: A_IN1.G, A_IN1.S, A_IN1.TN, B_IN1.G, B_IN1.S, B_IN1.TN, GATE1.G, GATE1.S, J6.3 (GND), OUT1.G, OUT1.S, OUT1.SN, Q1.1 (E), Q2.1 (E), R8.2, U1.5 (+), U1.10 (+), U2.3 (D3), U2.13 (GND), ~OUT1.G, ~OUT1.S, ~OUT1.SN
unnamed: D1.1 (K), Q3.3 (C)
unnamed: Q3.1 (E), R8.1
unnamed: R3.1, R4.1, RV1.5, RV1.6, U1.6 (-)
unnamed: R6.1, U1.12 (+), U2.4 (S3), U2.16 (S1)
unnamed: R6.2, R9.1, U1.9 (-)
unnamed: RV1.2, U1.3 (+)
unnamed: RV1.4, U1.7, U2.6 (D4)
unnamed: U1.1, U1.2 (-), U2.8 (D2)
unnamed: U2.1 (D1), U2.5 (S4), U2.9 (S2)
OUT: OUT1.T, OUT1.TN, R9.2, U1.8
~OUT: U1.13 (-), U1.14, ~OUT1.T, ~OUT1.TN

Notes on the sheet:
inverting sum
re-invert
gain 0-2 ideally 1 detent pot so it sits at g=1
This is a trick to only use the LED to show gate state if the GATE jack is used. When jack is unplugged, GATE_CONN is grounded, turning off the transistor. When jack is plugged, GATE_CONN floats, allowing the gate to control the transistor. R10 gives an input impedance of 100K, since LED is driven 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
When either AIN or BIN is connected, the ground at *_CONN is disconnected, turining the transistor on, shorting control of the first switch low, which switches from the constant voltage source to the summing source
TODO: If necessary, could move the buffer of ~OUT~ to here

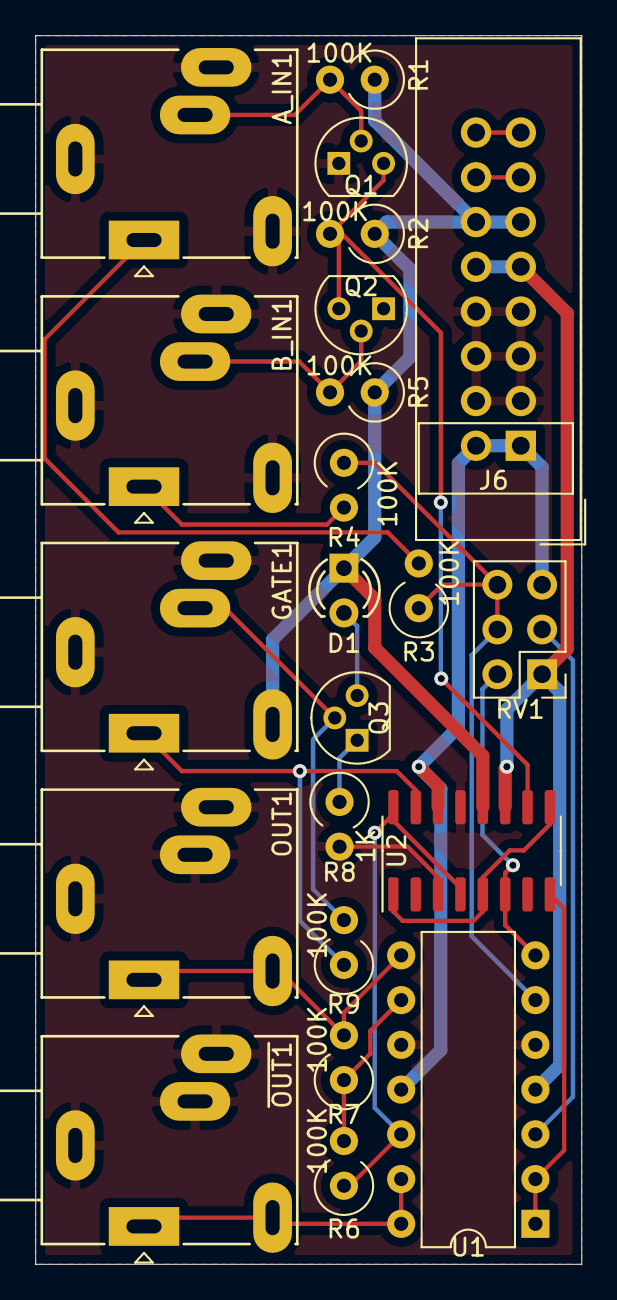
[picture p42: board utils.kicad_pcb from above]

Board: 2 copper layers, 31.0 x 69.8 mm, 21 parts (0 on the bottom side), 22 nets.

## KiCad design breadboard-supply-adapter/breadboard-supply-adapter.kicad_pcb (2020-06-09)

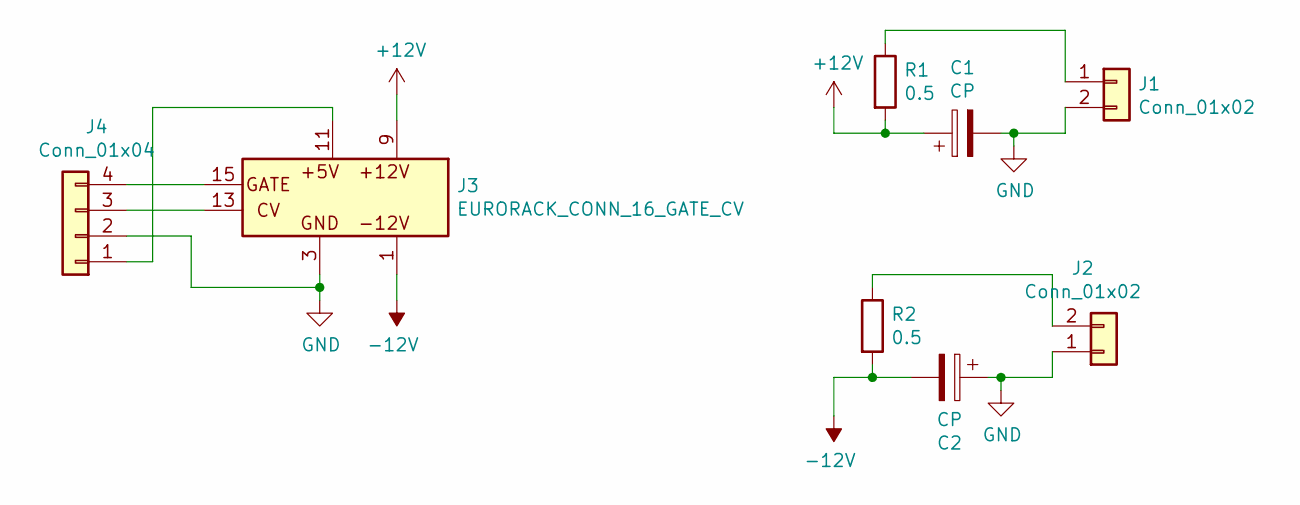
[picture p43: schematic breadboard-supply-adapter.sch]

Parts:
C1, C2: CP; CP_Radial_D5.0mm_P2.00mm
J1, J2: Conn_01x02; PinSocket_1x02_P2.54mm_Vertical
J3: EURORACK_CONN_16_GATE_CV; EURORACK_16_IDC
J4: Conn_01x04; PinSocket_1x04_P2.54mm_Vertical
R1, R2: 0.5; PinSocket_1x02_P2.54mm_Vertical

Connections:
+12V: C1.1, J3.9 (12V_P), R1.2
-12V: C2.2, J3.1 (12V_N), R2.2
GND: C1.2, C2.1, J1.2, J2.1, J3.3 (GND), J4.2
unnamed: J1.1, R1.1
unnamed: J2.2, R2.1
unnamed: J3.11 (5V), J4.1
unnamed: J3.13 (CV), J4.3
unnamed: J3.15 (GATE), J4.4


Board: 2 copper layers, 8 parts (0 on the bottom side), 8 nets.

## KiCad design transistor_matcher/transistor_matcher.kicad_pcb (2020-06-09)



Board: 2 copper layers, 15 parts (4 on the bottom side), 16 nets, no tracks yet.

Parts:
J3: I2C; JST-4-PTH-VERT
Q1, Q2: 2N3904; BJT_Slot
R1: 10K; R_Axial_DIN0204_L3.6mm_D1.6mm_P1.90mm_Vertical
R3: 100; R_Axial_DIN0204_L3.6mm_D1.6mm_P1.90mm_Vertical
R4, R5: 220; R_Axial_DIN0204_L3.6mm_D1.6mm_P1.90mm_Vertical
R6, R7: 4K7; R_Axial_DIN0204_L3.6mm_D1.6mm_P1.90mm_Vertical
RV1: 50K TRIM; Potentiometer_Trimmer_Bourns_PV36W
SW1, SW2: SW_DPDT_x2; SW_E-Switch_EG1271_DPDT
U1: AD8223; SOIC-8_3.9x4.9mm_Pitch1.27mm
U2: LM317_3PinPackage; TO-220-3_Horizontal
U3: Teensy2.0_(Arduino); Teensy2.0

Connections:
+5V: J3.2, R6.2, R7.2, SW1.1, SW1.6, U1.7, U2.3, U3.29
AOUT: U1.6, U3.28
GND: J3.1, R5.1, SW1.3, SW1.4, U1.4, U3.1
unnamed: Q1.3, Q2.3, R1.1
unnamed: R1.2, SW1.2
unnamed: R3.1, U1.8
unnamed: R3.2, U1.1
unnamed: R4.1, R5.2, U2.1
unnamed: RV1.2, SW1.5
unnamed: SW2.2, U1.3
unnamed: SW2.5, U1.2
SCL: J3.4, R6.1, U3.5
SDA: J3.3, R7.1, U3.6
VA: Q1.1, RV1.3, SW2.1, SW2.6
VB: Q2.1, RV1.1, SW2.3, SW2.4
VREF: Q1.2, Q2.2, R4.2, U1.5, U2.2, U3.31

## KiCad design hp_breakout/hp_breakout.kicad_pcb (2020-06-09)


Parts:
J1: AudioJack2_Ground_Switch; Jack_3.5mm_Ledino_KB3SPRS_Horizontal
J2: Conn_01x05_Male; PinHeader_1x05_P2.54mm_Vertical

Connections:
/U?/R: J1.R, J2.2
/U?/RN: J1.RN, J2.3
/U?/S: J1.S, J2.1
/U?/T: J1.T, J2.4
/U?/TN: J1.TN, J2.5

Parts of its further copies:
J3, J5, J7, J9, J11, J13, J15, J17, J19: AudioJack2_Ground_Switch; Jack_3.5mm_Ledino_KB3SPRS_Horizontal
J4, J6, J8, J10, J12, J14, J16, J18, J20: Conn_01x05_Male; PinHeader_1x05_P2.54mm_Vertical

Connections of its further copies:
/sheet5E6F4A6A/R: J13.R, J14.2
/sheet5E6F4A6A/RN: J13.RN, J14.3
/sheet5E6F4A6A/S: J13.S, J14.1
/sheet5E6F4A6A/T: J13.T, J14.4
/sheet5E6F4A6A/TN: J13.TN, J14.5
/sheet5E6F4A6C/R: J15.R, J16.2
/sheet5E6F4A6C/RN: J15.RN, J16.3
/sheet5E6F4A6C/S: J15.S, J16.1
/sheet5E6F4A6C/T: J15.T, J16.4
/sheet5E6F4A6C/TN: J15.TN, J16.5
/sheet5E6F4A6E/R: J17.R, J18.2
/sheet5E6F4A6E/RN: J17.RN, J18.3
/sheet5E6F4A6E/S: J17.S, J18.1
/sheet5E6F4A6E/T: J17.T, J18.4
/sheet5E6F4A6E/TN: J17.TN, J18.5
/sheet5E6F4A68/R: J11.R, J12.2
/sheet5E6F4A68/RN: J11.RN, J12.3
/sheet5E6F4A68/S: J11.S, J12.1
/sheet5E6F4A68/T: J11.T, J12.4
/sheet5E6F4A68/TN: J11.TN, J12.5
/sheet5E6F4A70/R: J19.R, J20.2
/sheet5E6F4A70/RN: J19.RN, J20.3
/sheet5E6F4A70/S: J19.S, J20.1
/sheet5E6F4A70/T: J19.T, J20.4
/sheet5E6F4A70/TN: J19.TN, J20.5
/sheet5E6F46C9/R: J5.R, J6.2
/sheet5E6F46C9/RN: J5.RN, J6.3
/sheet5E6F46C9/S: J5.S, J6.1
/sheet5E6F46C9/T: J5.T, J6.4
/sheet5E6F46C9/TN: J5.TN, J6.5
/sheet5E6F46CB/R: J7.R, J8.2
/sheet5E6F46CB/RN: J7.RN, J8.3
/sheet5E6F46CB/S: J7.S, J8.1
/sheet5E6F46CB/T: J7.T, J8.4
/sheet5E6F46CB/TN: J7.TN, J8.5
/sheet5E6F47F3/R: J9.R, J10.2
/sheet5E6F47F3/RN: J9.RN, J10.3
/sheet5E6F47F3/S: J9.S, J10.1
/sheet5E6F47F3/T: J9.T, J10.4
/sheet5E6F47F3/TN: J9.TN, J10.5
/sheet5E6F4684/R: J3.R, J4.2
/sheet5E6F4684/RN: J3.RN, J4.3
/sheet5E6F4684/S: J3.S, J4.1
/sheet5E6F4684/T: J3.T, J4.4
/sheet5E6F4684/TN: J3.TN, J4.5


Board: 2 copper layers, 43.2 x 80.0 mm, 20 parts (0 on the bottom side), 50 nets.

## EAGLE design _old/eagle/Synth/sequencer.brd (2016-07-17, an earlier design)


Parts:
C1: 10n; 1206
C2, C3: 22pF; 1206
C4, C5: .1u; 1206
C6: 1u; 1206
C7: 10UF-25V-10%(SMT-TANT); EIA6032-NOM
D1: LED-3MM-NO_SILK; LED3MM-NS
IC1: LM741P; DIL08
IC2: ADS1110; SOT-23-6
IC3: DAC8571; 8MSOP
IC4: ATMEGA328P_PDIP; DIL28-3
IO: HEADER-06X1-FEMALE; 06X1-PTH
POWER: M04PTH; 1X04
R1, R2, R3, R4, R7, R9, R10, R11, R18, R20: 10k; 1206
R5, R12, R13, R14, R15, R16: 100k; 1206
R6: 470; 1206
R17: 680; 1206
RP1: 100K; ALPS_POT_KIT
RP2, RP3: 10K; 3386P
SW1, SW2: TAC_SWITCHPTH; TACTILE-PTH
SW3, SW4: TL36YO; TL3XYO
SW5: RATE_SRC; TL3XYO
Y1: 16MHz; HC49US

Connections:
CLEAR: IC4.12 (PD6(AIN0)), R3.2, SW1.3, SW1.4
CV_IN: IO.5, RP2.1
CV_OUT: C1.1, IO.6, R5.2, RP3.2
DIRECT_IN: IC2.1 (VIN+), RP2.2
GND: C1.2, C2.2, C3.2, C4.2, C5.2, C7.C (-), IC2.2 (GND), IC2.6 (VIN-), IC3.5 (A0), IC3.8 (GND), IC4.8 (GND), IC4.22 (GND), POWER.3, R1.1, R2.1, R3.1, R4.1, R6.2, R9.1, R14.1, R16.1, R18.1, R20.1, RP2.3, RP3.3
unnamed: IC4.15 (PB1(OC1A)), R5.1
unnamed: IC3.3 (VSENSE), IC3.4 (VOUT), RP3.1
unnamed: D1.K (C), R6.1
unnamed: IC4.1 (PC6(/RESET)), R7.1
unnamed: C3.1, IC4.9 (PB6(XTAL1/TOSC1)), Y1.2
unnamed: C2.1, IC4.10 (PB7(XTAL2/TOSC2)), Y1.1
unnamed: D1.A, IC4.19 (PB5(SCK))
unnamed: IC1.3 (+IN), R12.1, R13.1, R14.2
unnamed: R17.2, RP1.P$3 (A)
unnamed: C6.2, C7.A (+), R15.1, R16.2
unnamed: C6.1, IC1.2 (-IN), R17.1
PLAYBACKGATE: IC4.14 (PB0(ICP)), IO.1, R20.2
RATE: IC4.4 (PD2(INT0)), R18.2, SW5.2
RATE_EXTERNAL: IO.2, SW5.3 (S)
RATE_INTERNAL: IC1.6 (OUT), R12.2, RP1.P$1 (E), RP1.P$2 (S), SW5.1 (O)
RECORD: IC4.11 (PD5(T1)), IO.4, R4.2, SW2.3, SW2.4
REVERSE: IC4.6 (PD4(XCK/T0)), R2.2, SW4.2
SCL: IC2.3 (SCL), IC3.6 (SCL), IC4.28 (PC5(ADC5/SCL)), R11.1
SDA: IC2.4 (SDA), IC3.7 (SDA), IC4.27 (PC4(ADC4/SDA)), R10.1
TRIGGER: IC4.5 (PD3(INT1)), IO.3, R9.2
TRIGGERMODE: IC4.13 (PD7(AIN1)), R1.2, SW3.2
V-: IC1.4 (V-)
VCC: C4.1, C5.1, IC1.7 (V+), IC2.5 (VDD), IC3.1 (VDD), IC3.2 (VREF), IC4.7 (VCC), IC4.20 (AVCC), POWER.2, R7.2, R10.2, R11.2, R13.2, R15.2, SW1.1, SW1.2, SW2.1, SW2.2, SW3.1 (O), SW4.1 (O)

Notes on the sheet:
INTERNAL_CLOCK
16-bit ADC
16-bit DAC



Board: 2 copper layers, 68.2 x 82.5 mm, 41 parts (5 on the bottom side), 27 nets.

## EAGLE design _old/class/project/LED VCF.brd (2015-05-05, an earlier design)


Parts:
C2, C14, C15, C16: 1000pF; AXIAL-5MM
C5, C7, C8, C9, C10, C11, C12, C13: 0.1uF; AXIAL-5MM
C6, C116: 10uF; E1,8-4
CV_ATTEN_POT_LEG2: IOPAD; ELLIPTICALPADSINGLE
CV_ATTEN_POT_WIPER: IOPAD; ELLIPTICALPADSINGLE
CV_F: OFFBOARD2JACK
CV_RES: OFFBOARD2JACK
CV_RESPOT_LEG2: IOPAD; ELLIPTICALPADSINGLE
CV_RESPOT_WIPER: IOPAD; ELLIPTICALPADSINGLE
FREQPOT_LEG1, FREQPOT_LEG2: IOPAD; ELLIPTICALPADSINGLE
FREQPOT_WIPER: IOPAD; ELLIPTICALPADSINGLE
INPUT_SIGNAL: OFFBOARD2JACK
J1: MTA04-156; 1X4MTA
LEDS: TL082B_P_8; P8
MIXER/STAGE1: TL082B_P_8; P8
OUTPUT_SIGNAL: OFFBOARD2JACK
R1, R2: 100k; AXIAL-0.4
R3, R4, R7, R8, R10, R13, R15, R16: 200k; AXIAL-0.4
R5: 25k; AXIAL-0.4
R6, R9: 2.2; AXIAL-0.4
R11, R14: 1k; AXIAL-0.4
R12, R17: 470; AXIAL-0.4
RESPOT_LEG1, RESPOT_LEG2: IOPAD; ELLIPTICALPADSINGLE
RESPOT_WIPER: IOPAD; ELLIPTICALPADSINGLE
RES_VACTROL: CUSTOM_VACTROL_HAYDENTHROUGH-HOLE; CUSTOM_VACTROL_HAYDEN
STAGE2/3, STAGE4: TL082B_P_8; P8
U$1: OCTOPUS_LED_QUAD_LDRTHROUGH_HOLE; OCTOPUS_LED_QUAD_LDR

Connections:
+15V: C5.P$1 (1), C8.P$1 (1), C9.P$1 (1), C12.P$1 (1), C116.+, FREQPOT_LEG1.P$1, LEDS.8 (VCC+), MIXER/STAGE1.8 (VCC+), R6.P$1 (1), RESPOT_LEG1.P$1, STAGE2/3.8 (VCC+), STAGE4.8 (VCC+)
-15V: C6.-, C7.P$2 (2), C10.P$2 (2), C11.P$2 (2), C13.P$2 (2), LEDS.4 (VCC-), MIXER/STAGE1.4 (VCC-), R9.P$1 (1), STAGE2/3.4 (VCC-), STAGE4.4 (VCC-)
AGND: C2.P$2 (2), C5.P$2 (2), C6.+, C7.P$1 (1), C8.P$2 (2), C9.P$2 (2), C10.P$1 (1), C11.P$1 (1), C12.P$2 (2), C13.P$1 (1), C14.P$2 (2), C15.P$2 (2), C16.P$2 (2), C116.-, CV_ATTEN_POT_LEG2.P$1, CV_F.GND, CV_RES.GND, CV_RESPOT_LEG2.P$1, FREQPOT_LEG2.P$1, INPUT_SIGNAL.GND, J1.2, J1.3, LEDS.3 (1IN+), LEDS.5 (2IN+), MIXER/STAGE1.3 (1IN+), OUTPUT_SIGNAL.GND, R11.P$2 (2), R14.P$2 (2), RESPOT_LEG2.P$1
CV_F_ATTEN: CV_ATTEN_POT_WIPER.P$1, R15.P$2 (2)
CV_RES_ATTEN: CV_RESPOT_WIPER.P$1, R4.P$1 (1)
FREQ_POT: FREQPOT_WIPER.P$1, R16.P$2 (2)
FROM_RES_CNTRL: R5.P$2 (2), RES_VACTROL.R2
LED2+: R8.P$2 (2), R11.P$1 (1), RES_VACTROL.LED+
LED2-: R12.P$2 (2), RES_VACTROL.LED-
LED+: R13.P$1 (1), R14.P$1 (1), U$1.LED+
LED-: R17.P$2 (2), U$1.LED-
MIXER_OUTPUT: MIXER/STAGE1.1 (1OUT), R2.P$1 (1), U$1.LDR1_1
unnamed: CV_RES.SIGNAL, R3.P$1 (1)
unnamed: LEDS.6 (2IN-), R3.P$2 (2), R4.P$2 (2), R7.P$2 (2), R8.P$1 (1)
unnamed: J1.1, R6.P$2 (2)
unnamed: INPUT_SIGNAL.SIGNAL, R1.P$2 (2)
unnamed: J1.4, R9.P$2 (2)
unnamed: LEDS.2 (1IN-), R10.P$1 (1), R13.P$2 (2), R15.P$1 (1), R16.P$1 (1)
unnamed: CV_F.SIGNAL, R10.P$2 (2)
unnamed: LEDS.1 (1OUT), R17.P$1 (1)
unnamed: LEDS.7 (2OUT), R12.P$1 (1)
OUTPUT: OUTPUT_SIGNAL.SIGNAL, R5.P$1 (1), STAGE4.1 (1OUT), STAGE4.2 (1IN-)
RES_POT: R7.P$1 (1), RESPOT_WIPER.P$1
STAGE1_INPUT: C14.P$1 (1), MIXER/STAGE1.5 (2IN+), U$1.LDR1_2
STAGE1_OUTPUT: MIXER/STAGE1.6 (2IN-), MIXER/STAGE1.7 (2OUT), U$1.LDR2_1
STAGE2_INPUT: C2.P$1 (1), STAGE2/3.3 (1IN+), U$1.LDR2_2
STAGE2_OUTPUT: STAGE2/3.1 (1OUT), STAGE2/3.2 (1IN-), U$1.LDR3_1
STAGE3_INPUT: C15.P$1 (1), STAGE2/3.5 (2IN+), U$1.LDR3_2
STAGE3_OUTPUT: STAGE2/3.6 (2IN-), STAGE2/3.7 (2OUT), U$1.LDR4_1
STAGE4_INPUT: C16.P$1 (1), STAGE4.3 (1IN+), U$1.LDR4_2
TO_RES_CNTRL: MIXER/STAGE1.2 (1IN-), R1.P$1 (1), R2.P$2 (2), RES_VACTROL.R1

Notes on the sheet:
NOTE: Leg 1 of the front panel potentiometer is wired directly to an attenuated resonance control voltage input jack also on the front panel.
NOTE: These three pins are wired to a front panel frequency control potentiometer.
NOTE: These three pins are wired to a front panel resonance control potentiometer.
NOTE: Leg 1 of the front panel potentiometer is wired directly to an attenuated frequency control voltage input jack also on the front panel.


Board: 2 copper layers, 67.0 x 66.0 mm, 52 parts (0 on the bottom side), 31 nets.

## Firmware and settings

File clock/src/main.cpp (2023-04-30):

#include <Arduino.h>
#include "RotaryEncoder.h"
#include "BufferedInput.h"
#include "Button.h"
#include "Timer.h"
#include "TapTempo.h"
#include "PauseState.h"
#include "ChangeTimeout.h"

// #define BACKPACK_DISPLAY 1

// Pins
#ifdef ARDUINO_AVR_ATmega2560
// Mega
#define CLOCK_PIN 10
#define SUBDIV_PIN 13
#define KNOB_A_PIN 11
#define KNOB_B_PIN 12
#define CV_IN_PIN A9
#define A_BUTTON_PIN 7
#define B_BUTTON_PIN 8
#define C_BUTTON_PIN 9
#define LED_A_PIN 14
#define LED_B_PIN 15
#define DISPLAY_PORT 6 /* PORTF */
#define DISPLAY_CTRL_PINS \
  {                       \
    7, 6, 5               \
  }
#define DISPLAY_ALT_WIRINGS \
  {                         \
    false, false, false     \
  }
#else
// Bare ATMega168p
#define CLOCK_PIN 10
#define SUBDIV_PIN 11
#define KNOB_A_PIN A0
#define KNOB_B_PIN A2
#define CV_IN_PIN A1
#define LED_A_PIN 12
#define LED_B_PIN 13
#define A_BUTTON_PIN 8
#define B_BUTTON_PIN 9
#define C_BUTTON_PIN 7
#define DISPLAY_PORT 4 /* PORTD */
#define DISPLAY_CTRL_PINS \
  {                       \
    A3, A4, A5            \
  }
#endif
// in order to simplify the PCB design to fit within the 3HP
// constraints, the center 7-segment is wired up differently
#define DISPLAY_ALT_WIRINGS \
  {                         \
    false, true, false      \
  }

#ifdef BACKPACK_DISPLAY
#include "BackpackDisplay.h"
BackpackDisplay display;
#else
#include "SevenSegmentArrayDisplay.h"
SevenSegmentArrayDisplay<3> display;
uint8_t displayPins[] = DISPLAY_CTRL_PINS;
bool altWirings[] = DISPLAY_ALT_WIRINGS;
#endif
Button aButton;
Button bButton;
Button cButton;
BufferedInput<16> cvInput;
TapTempo tapTempo;
RotaryEncoder knob;
PauseState pauseState;
SettingsManager settingsManager;
ChangeTimeout bpmChange;

#ifdef ARDUINO_AVR_ATmega2560
ISR(PCINT0_vect) // PORTB PCINT
{
  knob.tick();
}
#else
ISR(PCINT1_vect) // PORTC PCINT
{
  knob.tick();
}
#endif

void setup()
{
#ifdef ARDUINO_AVR_ATmega2560
  // Serial pins are used for other things on bare ATMega
  Serial.begin(9600);
#endif
#ifdef BACKPACK_DISPLAY
  display.begin();
#else
  display.begin(DISPLAY_PORT, displayPins, altWirings);
#endif
  // indicate we're doing setup by writing a dash
  // to each display and stepping through them
  // at each step
  display.setChar(0, '_');
  display.setChar(1, '_');
  display.setChar(2, '_');
  display.tick();
  pinMode(LED_A_PIN, OUTPUT);
  digitalWrite(LED_A_PIN, HIGH);
  pinMode(LED_B_PIN, OUTPUT);
  digitalWrite(LED_B_PIN, HIGH);
  display.tick();
  settingsManager.begin();
  display.tick();
  Timer.begin(CLOCK_PIN, SUBDIV_PIN, settingsManager.getCurrentSettings());
  display.tick();
  bpmChange.begin(1500);

  knob.begin(KNOB_A_PIN, KNOB_B_PIN);
  display.tick();
  aButton.begin(A_BUTTON_PIN, 100);
  display.tick();
  bButton.begin(B_BUTTON_PIN, 100);
  display.tick();
  cButton.begin(C_BUTTON_PIN, 100);
  display.tick();
  cvInput.begin(CV_IN_PIN);
  display.tick();
  display.clear();
  digitalWrite(LED_A_PIN, LOW);
  digitalWrite(LED_B_PIN, LOW);
  display.tick();
}

// On each loop:
// 1. handle the input state based on the buttons pressed
// 2. wait 10ms, updating the display the whole time
void loop()
{
  bool aPressed = aButton.isPressed();
  bool bPressed = bButton.isPressed();
  bool cPressed = cButton.isPressed();
  int8_t knobMotion = knob.readChanges();
  Timer.setBPMOffset(cvInput.read() / 4);    // scale cvInput to 0-256 BPM
  uint16_t tapBpm = tapTempo.tick(cPressed); // need to tick tap tempo on every loop
  pauseState.setState(aPressed && bPressed);
  Timer.setEnabled(!pauseState.isPaused());

  if (pauseState.isPaused())
  {
    // freeze clock and restart subdivisions
    Timer.reset();
    tapTempo.cancel();
    display.displayPaused();
    if (pauseState.isTap(cPressed))
    {
      Timer.singleTick();
    }
    // Long hold of C button does full reset
    else if (cPressed)
    {
      display.displayReset('F');
      if (cButton.isLongHold())
      {
        // Full reset
        settingsManager.restoreDefaults();
        Timer.loadSettings(settingsManager.getCurrentSettings());
        display.blinkReset('F');
        Timer.reset();
      }
    }
    // Long hold of A button saves current settings
    else if (aPressed)
    {
      display.displayReset('S');
      if (aButton.isLongHold())
      {
        settingsManager.writeSettings(Timer.getCurrentSettings());
        display.blinkReset('S');
      }
    }
    // Long hold of B button loads stored settings
    else if (bPressed)
    {
      display.displayReset('L');
      if (bButton.isLongHold())
      {
        Timer.loadSettings(settingsManager.getCurrentSettings());
        display.blinkReset('L');
        Timer.reset();
      }
    }
  }
  else if (aPressed)
  {
    // Knob controls subdivision setting
    int8_t subdiv = Timer.incrementSubdivisions(knobMotion);
    display.displaySubdivisions(subdiv);
  }
  else if (bPressed)
  {
    // Knob controls swing setting
    int8_t swing = Timer.incrementSwing(3 * knobMotion);
    display.displayNumber(swing);
  }
  else if (cPressed)
  {
    // if tapping tempo, show the base BPM tapped
    if (tapTempo.isActive())
    {
      Timer.setBaseBPM(tapBpm);
      bpmChange.noteChanged();
      display.displayNumber(tapBpm);
    }
  }
  else
  {
    // Default mode, knob controls base BPM
    uint16_t bpm = Timer.incrementBaseBPM(knobMotion);
    if (knobMotion != 0)
    {
      bpmChange.noteChanged();
    }
    // if the BPM is changing, display the base BPM,
    // otherwise show the true BPM including CV
    if (bpmChange.isChanging())
    {
      display.displayNumber(bpm);
    }
    else
    {
      display.displayNumber(Timer.getBPM());
    }
  }

  // Do the main control loop at 10ms, but continue
  // to tick the display in that time
  digitalWrite(LED_A_PIN, Timer.beatOn() ? HIGH : LOW);
  digitalWrite(LED_B_PIN, Timer.subdivOn() ? HIGH : LOW);
  display.tickFor(10);
}

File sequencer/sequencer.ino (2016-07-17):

#include "Wire.h"

// I2C addresses
#define dac8571 0x4C //10011[A0]0
#define ads1110 0x48

#define BUFF_SIZE 768 //this is pretty close to maxing out the memory of a ATMEGA328P. Chosen because it's a power-of-two-ish number
#define DEBUG 0       //set to 1 to see Serial ouput

//#define analogInPin A0
//#define analogOutPin 9
#define reversePin 4
#define recordPin 5
#define clearPin 6
#define triggerModePin 7
#define playbackGatePin 8
#define ledPin 13

//UNO interrupt0 => pin 2, interrupt1 => pin 3
#define sampleInterrupt 0
#define triggerInterrupt 1
#define triggerPin 3

volatile uint16_t BUFFER[BUFF_SIZE];         // Sample memory
volatile int readIndex, writeIndex = 0;   // pointers to read/write positions

//state variables
volatile boolean recordBtn, clearBtn;     //are these buttons pressed?
volatile boolean playbackReverse = false; //are we in reverse playback mode?
volatile boolean triggerMode = false;     // are we in trigger mode (playback doesn't loop but starts on interrupt)?
volatile boolean triggered = false;       // has a sample trigger been fired and hasn't completed?
volatile boolean playing = false;         // is there a sample actually playing back right now?

//TODO maybe smarter to replace current triggerMode implementation where we are always
// in trigger mode, and you can send a onComplete pulse back to the trigger to loop

void setup() {
  if(DEBUG) Serial.begin(9600); 
  pinMode(recordPin, INPUT);
  pinMode(clearPin, INPUT);
  pinMode(reversePin, INPUT);
  pinMode(triggerModePin, INPUT);
  pinMode(triggerPin, INPUT);
//  pinMode(analogOutPin, OUTPUT);
  pinMode(ledPin, OUTPUT);
  pinMode(playbackGatePin, OUTPUT);
  
  //when we get a signal on interrupt0, play/record. This way the sample rate
  // is externally controllable
  attachInterrupt(sampleInterrupt, sample, RISING);

  Wire.begin();

  Wire.beginTransmission(ads1110);
  Wire.write(0x8C); 
  Wire.endTransmission();
}

void loop() {
  //this is where less timing-critical code goes.
  // Here we sample user inputs (switches and the like)
  
  recordBtn = digitalRead(recordPin);
  clearBtn = digitalRead(clearPin);
  digitalWrite(ledPin, (recordBtn ? HIGH : LOW)); //light up LED when recording
  digitalWrite(playbackGatePin, (playing ? HIGH : LOW)); //pull the playbackGate high when playing
  
  // check if there was a change in trigger mode
  if(digitalRead(triggerModePin) != triggerMode){
    triggerMode = !triggerMode;
    // enable/disable the trigger interrupt
    if(triggerMode){
      attachInterrupt(triggerInterrupt, trigger, RISING); 
    }else{
      detachInterrupt(triggerInterrupt);
    }
  }
  
  //check if we need to reverse direction
  if(digitalRead(reversePin) != playbackReverse){
    readIndex = (playbackReverse ? 0 : writeIndex-1); //jump to beginning of sequence
    playbackReverse = !playbackReverse;
  }
  if(clearBtn){
    //to clear the memory, we don't actually need to touch the BUFFER at all.
    // just need to reset the write index back to zero. Past data will get overwritten
    // on the next record
    readIndex = writeIndex = 0;
//    analogWrite(analogOutPin, 0); //explicitly pull the output low
    writeDAC(0);
  }
  
  if(DEBUG) debugPrint();
  delay(50); //reasonable button sample rate
}

// interrupt handler
void trigger(){
  if(triggered) readIndex = (playbackReverse ? writeIndex-1 : 0); //restart sample on fresh trigger
  triggered = true;
}


void sample(){
//  cli(); // disable interrupts
  sei(); //enable interrupts TODO: bad practice. race conditions could occur!
  if(recordBtn && writeIndex < BUFF_SIZE){ //if record is pressed and there's still memory in the BUFFER
    //record
//    BUFFER[writeIndex++] = analogRead(analogInPin) << 6;
//    uint16_t data = readADC();
    BUFFER[writeIndex++] = 2*readADC();
//    BUFFER[writeIndex++] = 65536 >> 4;
  
  }else if(writeIndex > 0){// if there are samples to play
    //play
    if(!triggerMode || triggered){
      playing = true;      
//      analogWrite(analogOutPin, BUFFER[readIndex] >> 6);
      writeDAC(BUFFER[readIndex]);
      if(playbackReverse){
        if(--readIndex<0){
          readIndex = writeIndex-1;
          triggered = false;
        }
      }else{
        if(++readIndex>writeIndex-1){
          playing = false;
          readIndex=0;
          triggered = false;
        }
      }
    }
  }else{
    playing = false;
  }
//  sei(); //enable interrupts
}


void debugPrint(){
    // sanity checks
//    Serial.print(readIndex);
//    Serial.print("\t");
//    Serial.print(writeIndex);
//    Serial.print("\t");
//    Serial.print(BUFFER[readIndex]);
//    Serial.print("\t");
//    Serial.print(recordBtn);
//    Serial.print("\t");
//    Serial.print(clearBtn);
//    Serial.print("\t");
//    Serial.print(triggerMode);
//    Serial.print("\t");
//    Serial.print(triggered);
//    Serial.print("\t");
//    Serial.println(playing);
Serial.println(BUFFER[readIndex]);
}

void writeDAC(uint16_t data){
  Wire.beginTransmission(dac8571);
  Wire.write(0x10); //0001 0000 | 00[00=store,01=write,10=fromstore,11=broadcast]0000
  Wire.write((byte)(data>>8));
  Wire.write((byte)data);
  Wire.endTransmission();
}

uint16_t readADC(){
 byte highbyte, lowbyte;
 Wire.requestFrom(ads1110, 3);
 while(Wire.available()) // ensure all the data comes in
 {
   highbyte = Wire.read(); // high byte * B11111111
   lowbyte = Wire.read(); // low byte
   Wire.read(); //configRegister
 }
 return highbyte * 256 + lowbyte;
}

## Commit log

2015-04-28 inital commit
    [sequencer.brd, sequencer.sch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]
2015-05-04 new stuff
    [sequencer.brd, sequencer.sch]
2015-05-05 cleaned up
    [sequencer.drl]
2015-05-05 added classwork
    [LED VCF.brd, LED VCF.sch, Part1-rotated.stl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]
2015-05-05 added ADC, cleaned up schematic
    [sequencer.brd, sequencer.sch]
2015-05-13 uncommited board changes
    [sequencer.brd, sequencer.sch]
2015-05-17 updated sequencer eagle files for current version
    [sequencer.brd, sequencer.sch]
2015-05-17 updated schematic for BOM
    [sequencer.brd, sequencer.sch]
2015-05-20 board tweaks
    [sequencer.brd, sequencer.sch]
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2016-07-17 added other files
    [sequencer.brd, sequencer.sch]
2019-04-11 started amplifier design
    [Amp.kicad_pcb, Amp.sch]
2019-04-15 getting close on the amp
    [Amp.sch]
2019-05-28 updated amp - LM13700 with PNP-exp. control
    [Amp.sch]
2020-03-15 created base connector breakout project
    [hp_breakout.kicad_pcb, hp_breakout.sch]
2020-03-15 10 identical boards
    [file5E6F22F9.sch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]
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2020-03-16 updated amp schematic with glue
    [Amp.sch]
2020-03-17 updated VCA based on new calculations
    [Amp.sch]
2020-03-17 added notes
    [Amp.sch]
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2020-03-20 updated schematic for VBE measurement, started on board layout
    [transistor_matcher.kicad_pcb, transistor_matcher.sch]
2020-03-21 simplfied based on emperical tests
    [transistor_matcher.kicad_pcb, transistor_matcher.sch]
2020-03-28 basic sketch to prove inst. amp is working I think we really need a constant upper reference voltage
    [transistor_matcher.sch]
2020-03-29 updated to include display
    [transistor_matcher.sch]
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2020-04-05 separated amp into sheets
    [AVCA.sch, Amp.sch, BVCA.sch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]
2020-05-20 reworked amp sheets and notes
    [AVCA.sch, Amp.sch, BVCA.sch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]
2020-05-20 update amp config for quad-cascade design
    [AVCA.sch, Amp.sch, InputStage.sch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]
2020-05-20 add eurorack connector, fix some issues
    [AVCA.sch, Amp.sch, InputStage.sch]
2020-05-21 initial vco notes (not thoroughly validated or calculated
    [vco.kicad_pcb, vco.sch]
2020-05-23 rename shared kicad dir
    [AVCA.sch]
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2020-05-23 fix for eurorack connector
    [utils.kicad_pcb, utils.sch]
2020-05-23 added a few more untility footprints
    [InputStage.sch]
2020-05-24 use jacks directly for horizontal
    [utils.kicad_pcb, utils.sch]
2020-05-24 switched fet with cd4066
    [utils.kicad_pcb, utils.sch]
2020-05-24 pcb mostly laid out
    [utils.kicad_pcb, utils.sch]
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2020-05-24 move the quirks of the pcb out of the schematic
    [utils.kicad_pcb, utils.sch]
2020-05-24 switch to 10-pin header
    [utils.kicad_pcb, utils.sch]
2020-05-24 use +/-10V power supply for amps
    [utils.kicad_pcb, utils.sch]
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2020-05-25 LED driver for gate
    [utils.sch]
2020-05-25 experimented some more with the led
    [utils.sch]
2020-05-25 quick prototype of a breadboard power supply connector
    [breadboard-supply-adapter.kicad_pcb, breadboard-supply-adapter.sch]
2020-05-25 reversed the polarity of the neg cap (oops)
    [breadboard-supply-adapter.kicad_pcb, breadboard-supply-adapter.sch, fuse-resistor.xlsx]
2020-05-28 rework PCB
    [panel.dxf, utils.kicad_pcb, utils.sch]
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2020-05-28 use through-holes for pot
    [utils.kicad_pcb, utils.sch]
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2020-05-30 testing 555 as pwm control
    [panel.xlsx]
2020-05-30 add support for fixed CV output when no input
    [utils.kicad_pcb, utils.sch]
2020-05-30 correction based on breadboard test
    [utils.kicad_pcb, utils.sch]
2020-05-31 correct ground issue
    [utils.kicad_pcb, utils.sch]
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2020-06-01 made progress on VCO
    [current-capacitance-calc.xlsx, panel.dxf, vco.sch]
2020-06-02 fix some bugs in the circuit
    [utils.kicad_pcb, utils.sch]
2020-06-02 fix amp connector
    [InputStage.sch]
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2020-06-08 adjust params to lower gain=1 current to keep shape up to gain=2
    [amp.xlsx]
2020-06-08 updated schematic to match
    [VCA.sch, amp.xlsx]
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2020-06-16 experimenting with error
    [current-capacitance-calc.xlsx, vco.sch]
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2020-07-04 reworked utilities around better analog switch modules
    [utils.kicad_pcb, utils.sch]
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2020-07-04 reworked silkscreen
    [utils.kicad_pcb]
2020-07-04 corrected pin order on the pot breakout
    [utils.kicad_pcb, utils.sch]
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2020-07-20 tested utils rev b
    [utils.sch]
2020-08-01 got analog latch working, started schematic
    [adsr.kicad_pcb, adsr.sch]
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2020-08-01 prepared pcb for dual envelopes
    [adsr.kicad_pcb, adsr.sch, env.sch]
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2020-08-02 get rid of propigating controls
    [InputStage.sch]
2020-08-02 adjusted amp to a 10V control voltage range
    [InputStage.sch, VCA.sch]
2020-08-02 scaled adsr to support 0-10V input
    [env.sch]
2020-08-02 use a current mirror to isolate reference currents, buffer vin, tune params
    [adsr.sch, env.sch]
2020-08-02 use diode to force positive VIN
    [env.sch]
2020-08-29 corrections based on prototype pcb
    [VCA.sch]
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2020-09-12 assembled breadboard VCO and waveshaper
    [vco.sch]
2021-01-03 write code for shape selector, design CV input stage of vco
    [vco.sch]
2022-02-06 rework ASDR
    [adsr.kicad_pcb, adsr.sch, calcs.xlsx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]
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2022-02-06 reduce to one input
    [adsr.kicad_pcb, adsr.sch, env.sch]
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2022-09-10 planning and proof-of-concept code
    [clock.kicad_pcb, clock.sch]
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2022-09-11 switch to attiny84 and think more about control scheme
    [clock.sch]
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2022-09-19 move reference to blog
    [clock.sch]
2022-09-24 rework clock circuit
    [clock.sch]
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2022-09-25 pcb layout first pass
    [clock.kicad_pcb, clock.sch]
2022-09-25 cleanup pcb and silkscreen
    [clock.kicad_pcb, clock.sch]
2022-10-08 switch to frequency correct mode and update bpm register values
    [Timer.h, main.cpp]
2022-10-08 analog input pin protection
    [clock.sch]
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2022-10-16 get working on bare mcu
    [clock.sch]
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2022-10-17 switch side of bottom header for structural support
    [clock.kicad_pcb]
2022-10-17 simplify some complex routing
    [clock.kicad_pcb]
2022-11-25 redesign pcb around rotary encoder
    [clock.kicad_pcb, clock.sch]
2022-11-25 make a bit more space
    [clock.kicad_pcb, clock.sch]
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2023-01-01 fix PCB
    [clock.kicad_pcb, clock.sch]
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2023-01-02 update to Kicad 6 and fix some layout issues
    [clock.kicad_pcb, clock.kicad_sch]
2023-01-02 update adsr to kicad 6
    [adsr.kicad_pcb, adsr.kicad_sch, env.kicad_sch]
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2023-01-21 fix some PCB bugs
    [clock.kicad_pcb, clock.kicad_sch]
2023-01-21 fix inputs
    [clock.kicad_sch]
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2023-01-31 re-create panel in kicad
    [clock.kicad_pcb]
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2023-02-27 test out on pcb
    [clock.kicad_pcb]
2023-03-06 make ground plane connected, move LEDs wide
    [clock.kicad_pcb, clock.kicad_sch]
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2023-03-18 flip display direction of subdivisions
    [Timer.h, main.cpp]
2023-04-30 fix bug in timer
    [Timer.h, main.cpp]
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2023-05-01 fixed and separated pcb
2024-10-22 add reusable openscad layout definitions
    [eurorack.scad]
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2024-10-23 flip y orientation
    [eurorack.scad]
2024-10-23 reverse y-axis orientation
2024-10-23 Revert "reverse y-axis orientation"
    This reverts commit be2b3902423d8e89fe58d89905e9280b5649029d.
2024-10-23 Revert "flip y orientation"
    This reverts commit a8479f8d3d33ab95d629eb13d20a0d69ed88b72e.
    [eurorack.scad]
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2026-08-29 rework master board for space and symmetry
2026-08-29 rework channel board for space
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

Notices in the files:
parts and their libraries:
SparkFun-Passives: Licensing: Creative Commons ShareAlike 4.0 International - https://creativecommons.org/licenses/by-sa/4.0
